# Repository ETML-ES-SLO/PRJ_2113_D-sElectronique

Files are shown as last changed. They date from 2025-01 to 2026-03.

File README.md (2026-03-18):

# 2113_DeElectronique_V3

Ce projet implémente une application pour microcontrôleur PIC32MM0064GPL020, développée avec MPLAB X et XC32.

## Sommaire

- [Présentation](#présentation)
- [Informations de génération](#informations-de-génération)
- [Compilation](#compilation)
- [Utilisation](#utilisation)
- [Documentation Doxygen](#documentation-doxygen)
- [Diagrammes](#diagrammes)
- [Ressources](#ressources)

## Présentation

Ce dépôt contient le code source et la configuration pour le projet électronique basé sur le PIC32MM.
Il s’agit de réaliser un dé électronique qui puisse être produit en petite série à l’ETML et distribué aux visiteurs de l’ES, par exemple lors des portes ouvertes. S’agissant d’un cadeau, une attention particulière sera portée à la minimalisation des coûts. Le fonctionnement sera le suivant :

Lorsque le montage est secoué puis reposé à l’horizontale, un nombre aléatoire entre 1 et 6 sera affiché à l’aide de 7 LEDs. Il ne doit y avoir aucun bouton. Les LED seront disposées à la manière d’un dé à lancer. Les LED restent allumées 10 secondes, puis le montage s’éteint (coupure d’alimentation totale, sauf pour l’élément de détection du secouement). Ce dernier est le seul sous tension en permanence et réveille le montage à chaque nouveau secouement.

""" Actuellement un bouttons est nécéssaire lors du premier allumage pour configurer accéléromètre, aussi la demande à été modifier pour passer à 3s d'affichage """

Utilisation de l'accéléromètre MC3419 avec une configuration nécéssitant ~0,5g pour déclenchement. 
La résolution du capteur MC3419 est typiquement de 14 bits (0 à 16383 pour ±2g).
1 LSB = 4g (de -2g à +2g)/ 16384 = 0,000244 g ≈ 0,244 mg

Seuil (g) = Valeur_seuil * (Plage_en_g / 2^résolution)
          = 2000 * (4 / 16384 )
          = 2000 * 0,000244
          = 0,488 g

La documentation technique est générée avec Doxygen.

## Modifications apportées entre V2 et V3

- Modification de la fonction d'attente avec utilisation du timer (précision accrue et meilleure gestion du temps).
- Ajout de la possibilité de modifier le changement de la consigne PWM avec le CoreTimer (meilleure flexibilité et contrôle).
- Ajout du réglage d'intensité automatique avec les "rampes" (transition douce de l'intensité).
- Refactorisation et amélioration des commentaires pour une meilleure génération de documentation Doxygen.
- Refactorisation de la structure principale du main.

## Informations de générations

```
Product Revision  :  PIC24 / dsPIC33 / PIC32MM MCUs - 1.75.1
Device            :  PIC32MM0064GPL020

Les drivers générés sont testés avec :
    Compiler      :  XC16 v1.35
    MPLAB         :  MPLAB X v5.05

La version 3 de cette application est conçue et testée avec :
    Compiler      :  XC32 v2.5 
    MPLAB         :  MPLAB X v5.50
```

## Versionning 
 Latest Hardware : 2113E_DeElectronique
 
 Latest Software : 2113_DeElectonique_V3.X_2024

le Hardware version D et E sont compatibles avec le soft V3  

## Compilation

1. crée un dossier "PROJ" sous" C:\microchip\harmony\v2_06\apps\"
2. Cloner ce dépôt à l'intérieur  le chemin devrais être : "C:\microchip\harmony\v2_06\apps\PROJ\PRJ_2113_D-sElectronique"
4. Ouvrez le projet dans MPLAB X.
5. Sélectionnez le compilateur XC32 v2.5.
6. Compilez le projet (`Build Project`).

## Utilisation

- Chargez le firmware sur la carte cible (2113E_DeElectronique) via MPLAB X (la carte doit être alimentée en +1,5V).
- Maintenire le bouton S1 enfoncer pendant la durée de programmation de la carte.
- Retirer la sonde de programation (snap/icd4) appuyer sur le switch environs 1s.
- secouer
- pour éteindre: retirer la pile 

## Etat actuel 

- Les résistances R14 et R17 ont été changées, 1k & 5k6 --> 10k & 56k.

### Résultat des tirrages 
- sur 130 tirrages: 



Le N°1 sort le plus souvent

## Documentation Doxygen

La documentation complète du code est disponible dans le dossier [html/](html/).  
[Consulter la documentation Doxygen](https://docdees.neocities.org/)
(ouvrir dans un browser une fois le dépot en local) exemple du rendus : 





## Diagrammes

Précédente version (V2)



Nouvelle version (V3) 



les autres diagrammes sont disponibles sous "C:\microchip\harmony\v2_06\apps\PROJ\PRJ_2113_D-sElectronique\soft\2113_DeElectronique_V3.X\code2flow"

## Ressources

- [Diagramme de flux (Code2Flow)](https://app.code2flow.com/)
- [VS Code](https://code.visualstudio.com/)
- [GitHub Copilot](https://github.com/features/copilot)
- [MPLAB X IDE](https://www.microchip.com/en-us/tools-resources/develop/mplab-x-ide)
- [Graphviz](https://graphviz.gitlab.io/)
- [Doxygen](https://www.doxygen.nl/index.html)
- [MCC Standalone (MPLAB Code Configurator)](https://www.microchip.com/en-us/tools-resources/configure/mplab-code-configurator)
- [Documentation Microchip PIC32MM](https://www.microchip.com/wwwproducts/en/PIC32MM0064GPL020)

---

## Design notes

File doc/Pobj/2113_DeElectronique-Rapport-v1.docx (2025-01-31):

2113_DeElectronique

Travail de diplôme

École supérieure

Filière électronique

A l'attention de :

M.Castoldi

M.Isoz

M.Zosso

8 novembre 2021

ETML

Maxime Colloud

# Introduction

## Contexte

Ce projet porte sur la conception d’un dé électronique destiné à être produit en série à l’EML et distribué aux visiteurs des portes ouvertes de l’ETML-ES.

## Résumé du cahier des charges

(Cahier des charges à voir en annexe)

### Objectif

Réaliser un dé électronique le moins couteux possible qui une fois secoué puis reposé horizontalement affichera pour une durée de 10 sec un chiffre aléatoire entre 1 et 6 à l’aide de 7LEDS disposées à la manière d’un dé à lancer. Après la durée d’affichage, le système se met hors-tension (sauf pour l’élément de détection de secousse).

### Données d’objectif

#### A) Les composants principaux

- 7 LEDs
- Accéléromètre avec interruption pour l’enclenchement du système
- MCU PC32MX ou PIC32MM
- Alimentation par pile AA ou AAA

#### B) Autonomie

Autonomie minimale de 10'000 lancés de dé et d’un an en mode veille

#### C) Coûts

- Composants peu couteux
- PCB simple ou double face (pas de composants bottom)
- Boitier simple concevable à l’ETML

#### D) Dimensions maximales

Dimensions maximales du boitier : 70 x 70 x 25 mm.

#### E) Logo

Logo ETML + mention « Ecole supérieure – filière électronique » doivent être visible sur l’objet final.

# Pré-étude

## Planning

(Voir planning en annexe)

## Schéma général du système

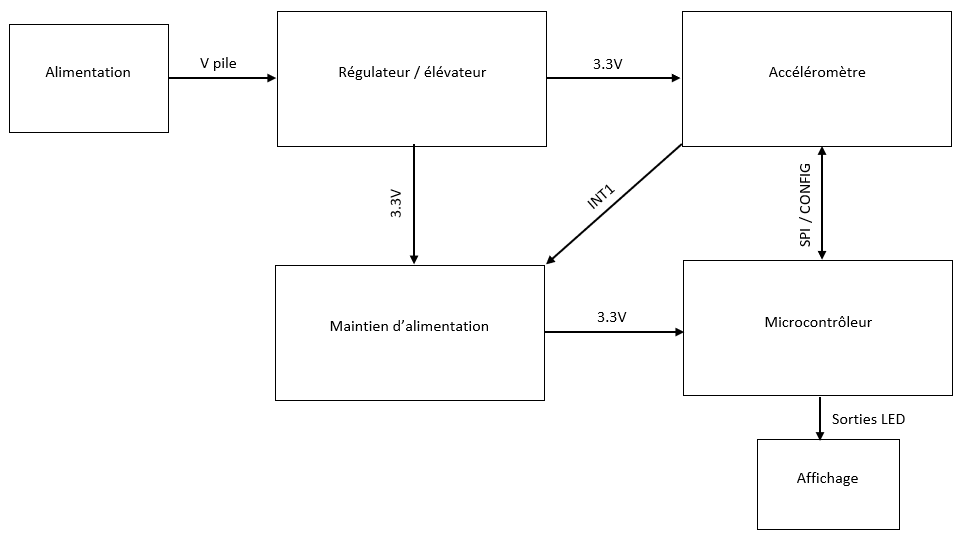
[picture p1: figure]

## Contrainte du choix des composants

Pour le choix des composants, le cahier des charges ne donne pas de contrainte particulière autre que 2 familles de microcontrôleur à choix, l’alimentation par pile AA ou AAA et un coût bas des prix.

### Méthode sélection des composants :

Pour choisir les composants qui seront utilisés pour le projet, plusieurs éléments ont été pris en compte :

- Le prix du composant
- Disponibilité du composant
- Utilisabilité
- Disponibilité
- Taille de boitier

## Choix de l’alimentation

### Tension d’alimentation du système :

L’alimentation du système est définie par les deux circuits : microcontrôleur et accéléromètre.

#### Tension microcontrôleur

#### Tension accéléromètre

### Options d’alimentation :

#### 2 piles :

2 piles AA permettent une tension entre 2V piles vides et 3V piles pleines. Cette option serait fonctionnelle mais utilise 2 piles. Pour la fonction simple d’un dé, 2 piles font beaucoup de capacité et prennent plus de place

#### 2 piles + régulateur :

Avec un régulateur, les problèmes sont identiques que pour 2 piles seules, le régulateur viendra ajouter une stabilité à la tension, mais usera moins les piles dû à la perte de tension régulateur de 0.3V en moyenne entre l’entrée et la sortie.

#### 1 pile + élévateur :

L’élévateur permet d’utiliser une seule pile et de l’utiliser jusqu’à sa décharge complète.

#### Choix effectué :

J’ai choisi l’option 1 pile + élévateur. Cette option permet d’utiliser 1 seule pile utilisant un minimum de place sur le PCB et d’utiliser la pile jusqu’à sa fin de vie. L’élévateur conservera une tension fixe sur la carte.

## Choix des composants principaux

### Complexité des recherches

Avec les pénuries actuelles de semi-conducteurs, il est prévu que des problèmes de disponibilité de composants se fassent ressentir, ne permettant pas forcément d’acquérir les composants les plus efficaces mais de choisir au contraire des composants utilisable et disponible.

### Microcontrôleur

Le choix du microcontrôleur était contraint par un choix entre deux famille PIC32MM et PIC32 MX. Le choix s’est porté sur le plus petit microcontrôleur étant donné que pour le fonctionnement du dé électronique ne demande que peu de mémoire RAM et peu de mémoire FLASH. Puisque le projet est destiné à être un cadeau à des visiteurs et que le prix doit être au plus bas, en comparant les deux familles de microcontrôleur et ceux disponible, le choix final s’est porté sur la famille MM qui est moins cher et sur le modèle PIC32MM064GPL020.

### Accéléromètre

Les problèmes de semi-conducteur, se sont fait ressentir dans le choix de l’accéléromètre. La famille ST était un choix de départ par sa documentation très complète, des exemples de codes disponibles. De plus cette famille d’accéléromètre a déjà été utilisé à l’ETML-ES et un support d’aide sur son fonctionnement serait possible. Le fabricant conçoit de plus des petites cartes avec l’accéléromètre monté qui permet de pouvoir tester le fonctionnement de l’accéléromètre avec un kit micro en attendant l’arrivée de la commande du PCB et le montage de la carte.

Malheureusement la grande partie des accéléromètres sont en rupture de stock, les cartes montées sont indisponibles et les accéléromètres disponibles ont un prix élevé. Le choix s’est donc tourné sur un accéléromètre disponible, à bas prix avec une documentation complète, des fichiers .h et .c de l’accéléromètre, cependant pas d’exemples de codes disponible. Selon ces derniers critères, il ne restait que le MC3419.

### Élévateur

L’élévateur est le composant dont le choix a été le plus complexe avec les problèmes de semi-conducteur. La plupart des élévateurs sont en rupture de stock. Je me suis tourné sur le choix de la disponibilité et de l’utilisabilité d’un élévateur, mais aussi sur un élévateur possédant un boitier standard afin de permettre à la fin de la pénurie de remplacer l’élévateur actuel par un autre élévateur plus adapté, voir même moins couteux. En triant les options de tensions de sortie entre 3 et 3.3V, le seul élévateur restant disponible était le R1210N331D-TR-FE.

Le choix était tout d’abord tourné vers un élévateur avec une tension de sortie de 3V ce qui consommerait moins qu’une tension de 3.3V mais tous les élévateurs utilisables étaient en rupture de stock.

# Design

## Schéma bloc

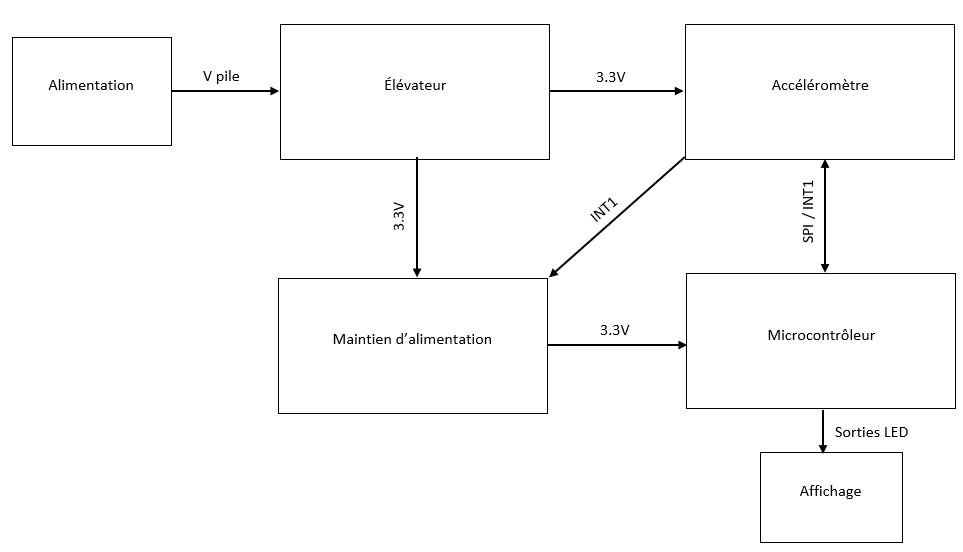
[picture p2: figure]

## Détail des blocs fonctionnels

### Général

Le principe utilisé est une alimentation du système par une pile AA.

La pile est connectée à l’élévateur pour élever sa tension à 3.3V et permet le fonctionnement du microcontrôleur et de l’accéléromètre.

Afin de garder le système en basse consommation hors utilisation, seul l’accéléromètre est alimenté en permanence par l’élévateur afin rester fonctionnel. Lorsque l’accéléromètre décèle un mouvement de secouement, il active une pin d’interruption qui vient activer l’alimentation du microcontrôleur.

Le microcontrôleur à son réveil affiche un chiffre aléatoire pour une durée de 10sec puis reset l’interruption de l’accéléromètre coupant l’alimentation du microcontrôleur.

### Alimentation

L’alimentation est une pile de format AA 1.5V.

### Élévateur

Le bloc élévateur a pour but d’élever la tension de la pile à la tension fixe de 3.3V pour alimenter le système. L’élévateur accepte une tension de minimum 1V pour son fonctionnement (tension d’une pile considérée vide).

### Maintien d’alimentation

Cette partie sert « d’interrupteur » à l’alimentation du microcontrôleur. Celui-ci bloque le 3.3V de l’élévateur et le laisse passer lorsque l’accéléromètre active le montage qui alimente le microcontrôleur.

### Accéléromètre

L’accéléromètre a pour intérêt de détecter un mouvement, dont le seuil de détection pour être réglé pour détecter un secouement plus ou moins fort. L’accéléromètre agit avec la partie de maintien d’alimentation en activant une sortie d’intettupt quand les conditions de secouements sont atteintes et enclenche l’alimentation du microcontrôleur.

### Microcontrôleur

Cœur du système, le microcontrôleur entre en action lorsque l’accéléromètre active son alimentation. Celui-ci à son réveil déterminera si le montage est alimenté pour la première fois (réveil par détection de pile sans action de l’accéléromètre) dans quel cas il activera une sortie agissant sur le maintien d’alimentation pour se garder alimenter le temps de configurer l’accéléromètre, puis s’éteindra en baissant cette pin.

Dans le cas d’un réveil par l’accéléromètre, le microcontrôleur sera connecté à la pin interrupt de l’accéléromètre pour détecter un réveil pour accéléromètre. Il génèrera un chiffre aléatoire pour une durée de 10sec avant de reset l’interrupt de l’accéléromètre et retourner en état hors tension.

### Affichage

L’affichage se fait à partir de 7 LED basse consommation disposé de la manière d’un dé à lancer.

## Calculs

### Évaluation des couts

Les couts ont été calculés sur la base du prix lors d’une commande de 100 pièces.

(Voir évaluation des couts en annexes)

### Évaluation de la consommation

#### Consommation hors utilisation :

Hors utilisation, la consommation provient de l’accéléromètre et de perte dans l’élévateur.

La datasheet indique une consommation de 77uA.

Le courant sur la pile est plus élevé que le courant en sortie de l’élévateur dû à l’élévation de tension, pour faire une moyenne approximative, je vais prendre comme tension de pile 1.25V.

3.3V / 1.25V = 2.64 (rapport d’augmentation in / out)

Le courant sur la pile est donc en moyenne 2.64x plus gros qu’à la sortie de l’élévateur.

Les 77uA deviennent alors :

77 * 2.64 = 203.28uA

En considérant une capacité de pile moyennant 2000mAh, on peut calculer la durée approximative du système hors fonctionnement.

2000 / 0.20328 / 24 = 409.9 jours.

#### Consommation en utilisation :

Par approximation, on considère en moyenne que 3.5 LED sont allumées sur 100 lancés. Pour 2mA de consommation, ça fait 7mA nécessaire pour les LED.

7 * 2.64 = 18.48 mA sur la pile

Je considère par approximation une consommation moyenne de 20mA.

Un lancer dure en moyenne 10 sec.

Donc on peut calculer.

Nbr lancer= (Capacité pile)/(I*T)= (2000*3600)/(20*10)= 36^(') 000 lancers

### Dimensionnement de l’élévateur

Pour dimensionner l’élévateur, les calculs d’un autre élévateur de taxas instruments ont été utilisés puisque l’élévateur choisi n’indique pas de calculs de dimensionnement dans sa datasheet.

La recherche du pire cas a été utilisée pour calculer les composants.

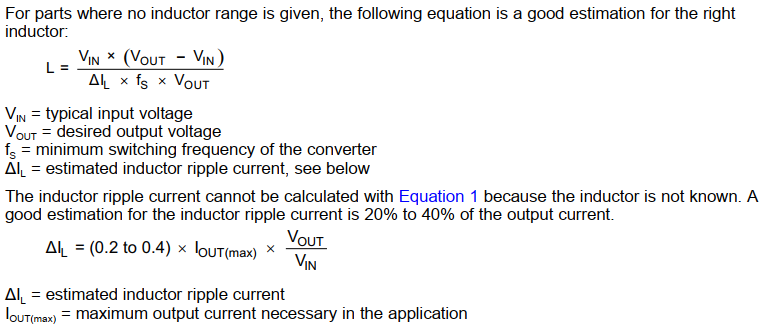
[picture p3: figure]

La fréquence de switching de l’élévateur est indiquée à 180kHz par le fabricant.

Le courant max utilisé est une approximation à 20mA.

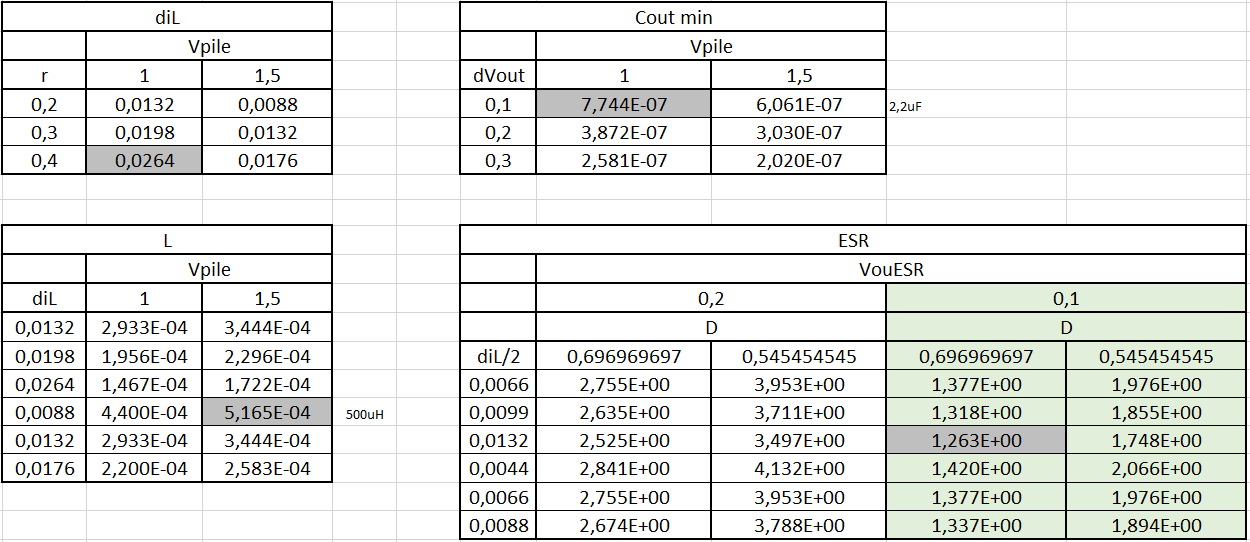
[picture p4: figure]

L est arrondi à 560uA.

## Schéma électrique complet

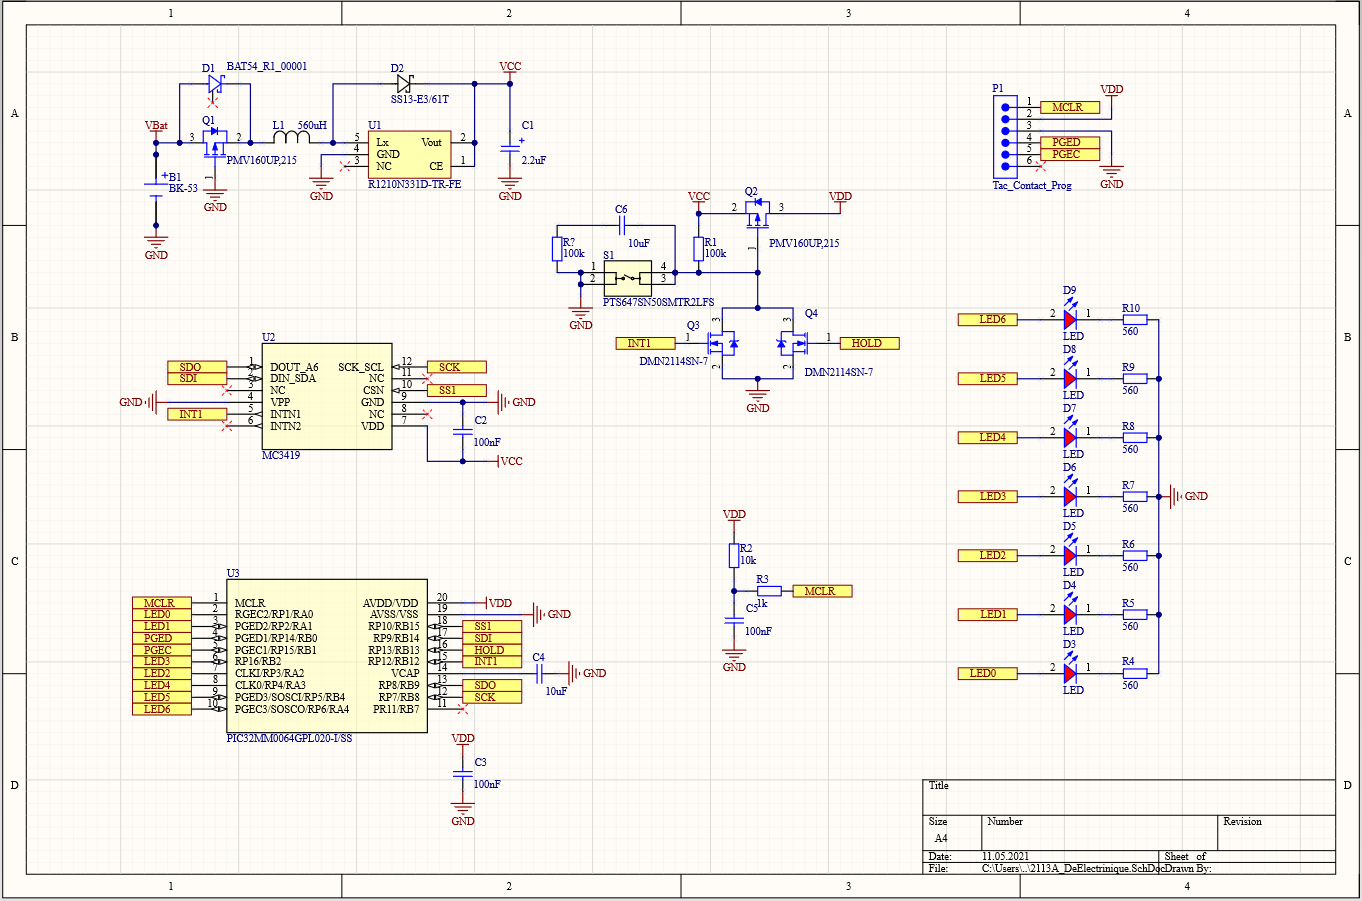
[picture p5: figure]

(Voir en annexe le schéma en meilleur format)

## Bloc schématique

### Alimentation

La pile est connectée à l’élévateur qui augmentera la tension à 3.3V. La diode D2 est une équivalente à la diode recommandée par le fabricant.

Pour éviter les tensions inverse par une mise à l’envers de la pile, un MOSFET canal P est placé avec la source sur la pile ce qui permet selon le fonctionnement interne d’avoir la diode du MOSFET qui permet la conduction avec la pile dans le bon sens. La diode D1 est prévue par sécurité pour permettre d’avoir la tension minimal drain source si la diode du MOSFET demande une tension trop élevée. Pile vide = 1V, si la diode du MOSFET demande 0.7V, la tension drain-source ne sera plus respectée.

### Maintien d’alimentation

Les valeurs du RC sur le schéma ne sont pas les meilleurs. Le but étant de tester le fonctionnement, puis de chercher les bonnes valeurs si le montage fonctionne comme voulu.

Le principe de fonctionnement de ce montage est le suivant :

Le MOSFET Q2 est un canal P et celui-ci conduite lorsqu’il y a une logique basse sur sa gate. Les MOSFET Q3 et Q4 sont canaux N et conduisent avec une logique haute.

Par défaut, les MOSFET Q3 et Q4 ne conduisent pas, le MOSFET Q2 a donc la tension 3.3V à ses bornes. Lorsqu’il y a un des deux MOSFET Q3 ou Q4 qui conduit, la gate du MOSFET Q2 se trouve à la masse et se met à conduire. La résistance R1 permet de créer une différence de potentiel entre le drain et la gate du MOSFET Q2 lors de sa conduction. Elle permet de plus une limitation de courant et avec une valeur de 100k, les pertes d’énergie son basses.

Dans le but de détecter une première mise sous tension, un RC avec C6, R1 et R11 a été implémenté, celui-ci va créer lors d’une mise de pile, une tension de 0V sur la gate Q2 et permettre une conduction. Le condensateur va ensuite se charger et restera charger évitant des pertes d’énergies par la suite.

Le but de la résistance R11 est de limiter le courant qui circulera au travers des MOSFET lors de la décharge du condensateur.

Par sécurité en cas de non-fonctionnement du RC, un bouton est implémenté en parallèle pour permettre de faire la détection de première mise sous tension manuellement et de configurer l’accéléromètre.

Le signal HOLD provient du microcontrôleur pour activer son auto-maintient d’alimentation.

Le signal INT1 provient de la pin d’interrupt de l’accéléromètre pour activer l’alimentation lors d’une détection de secoument.

L’ajout de la partie détection de première mise sous tension a été faite précipitamment pour cause d’un envoi de PCB en fabrication qui devait se faire au plus vite. Les valeurs schématique R11 et C6 ne sont pas représentative des valeurs du besoin et fonctionnelle. Celle-ci non pas été calculé avant la commande du PCB et ont été déterminé par la suite.

### Accéléromètre

L’accéléromètre fonctionne en SPI ou I2C, pour activer la communication par SPI, il suffi de mettre la pin 10 CSN à 0. La pin 1 DOUT_A6 est une sortie de donnée SPI, la pin 2 DIN_SDA est une entrée de donnée SPI, la pin 12 SCK_SCL est l’entrée clock SPI et la pin 5 INTN1 est la pin d’interrupt de l’accéléromètre qui se mettra à 1 lors d’une détection de secouement.

C2 est un condensateur de découplage.

### Microcontrôleur

Le microcontrôleur utilise les pins SPI en 4 fils, il utilise une pin pour le signal de maintien d’alimentation HOLD, une pin d’entrée avec le signal INT1 de l’accéléromètre pour avoir l’information lors de son réveil d’un réveil par accéléromètre et non la première mise sous tension.

Chaque LED sont connectées sur une pin du microcontrôleur.

### Debug

Il a été choisi pour le connecteur de débug d’utiliser des pads sans connecteur et de venir directement se plug sur la carte. Ça permet une économie de place et de prix.

### Affichage

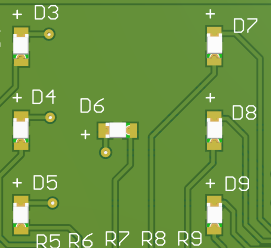
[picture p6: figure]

Les LEDS sont des LED low power rouge, permettant un besoin de 2mA pour fonctionner. Les LED rouges sont les LED qui demandaient la tension la plus basse de fonctionnement.

## PCB

L’implémentation des composants s’est faite comme suit :

Les LED ont été placées au milieu de la carte. Le support de pile en bordure de carte pour permettre l’ajout et le retrait facile de la pile. Le reste des composants a été placé selon la place restante et par bloc fonctionnel.

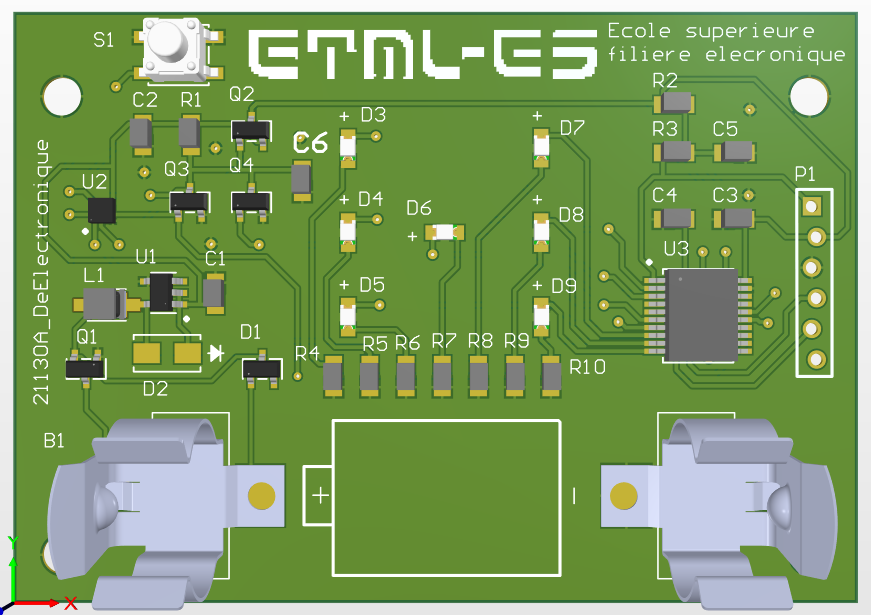
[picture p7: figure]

# Soft

## Diagramme du soft

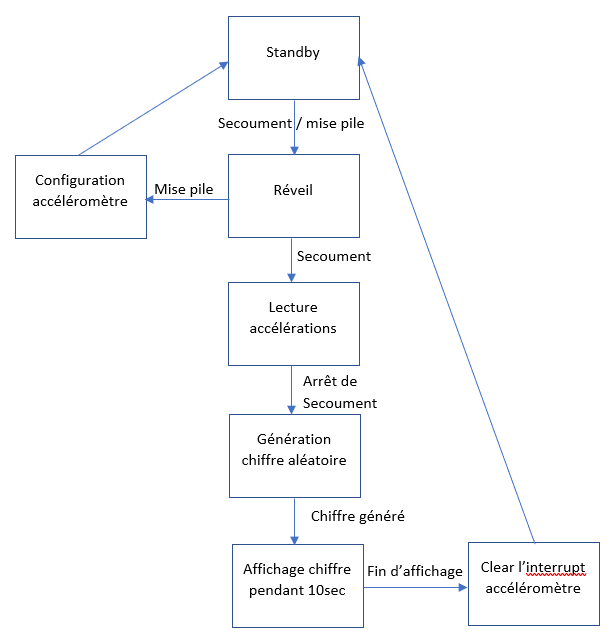
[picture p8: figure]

### Explication soft

Initialement, le programme est en standby avec le microcontrôleur hors tension.

Lors de la mise de la pile ou par l’accéléromètre, le microcontrôleur se réveille et se configure. Il lit le signal INT1 pour connaitre la raison de son réveil (mise de la pile ou réveil par l’accéléromètre). Si le signal INT1 est à 0, alors c’est une mise de pile, dans ce cas, le signal HOLD est levé pour maintenir l’alimentation du microcontrôleur, puis par SPI, configure l’accéléromètre selon les paramètres nécessaires au fonctionnement du dé avec de descendre le signal HOLD et couper l’alimentation du microcontrôleur.

Lors d’un réveil par l’accéléromètre, le signal INT1 est lu à l’état haut et le programme lit les registres d’axes pour identifier la continuité ou l’arrêt de l’action de secoument. Une foi le secoument terminé, les axes sont lus et les valeurs sont utilisés avec la fonction RAND qui permet une génération pseudo aléatoire d’un nombre, le modulo 6 de ce nombre est effectué pour acquérir un chiffre entre 0 et 5 pseudo aléatoire.

Le nombre une fois généré est affiché sur les LED pour une durée de 10 sec puis le flag d’interruption qui aura pour effet de remettre le signal INT1 à 0 et ainsi couper l’alimentation du microcontrôleur

## Création d’un projet MCC

Les projets utilisant la famille MM utilise pour la configuration des chips, le Code Configurator ou MCC d’MPLAB X. Il faut alors au préalable avoir installé l’extension du MCC trouvable sur le site MPLAB X.

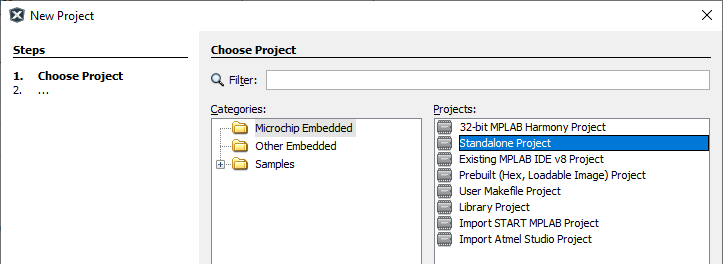
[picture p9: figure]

Une fois installé, il faut créer un projet Standalone Project puis choisir le microcontrôleur utilisé (pour le dé c’est le PIC32MM064GPL020).

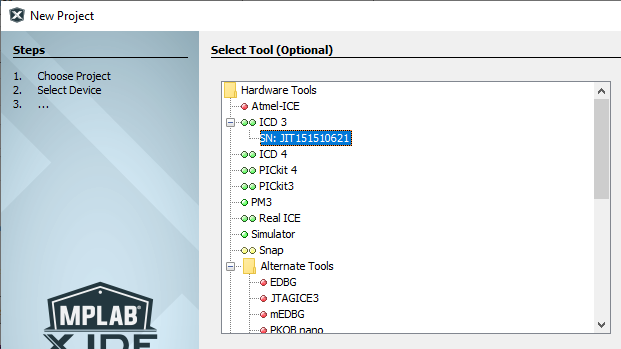
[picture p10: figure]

Pour ce projet, l’outil utilisé est l’ICD 3

Avec le compilateur XC32

On nomme ensuite le projet qui peut être placé à n’importe quel endroit.

## Configuration du microcontrôleur

Pour ouvrir le MCC, il faut aller sous l’onglet Tools -> Embedded et choisir le MCC.

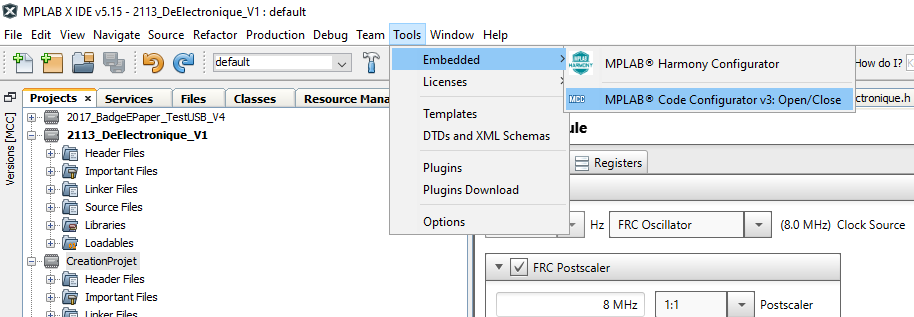
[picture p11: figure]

L’interface du code configurator est intuitif et on se repère rapidement.

### Clock

Par défaut, le clock secondaire est actif et ceci empêche l’utilisation de 2 pins, il faut desable le SOSCEN.

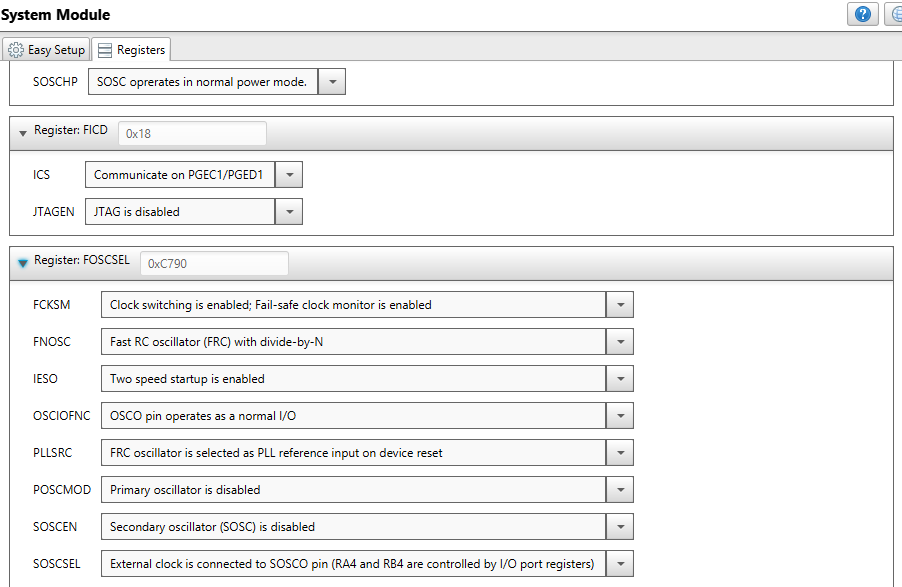
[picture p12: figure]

### Timer

Puisque le dé doit afficher un chiffre pour une durée de 10sec (spécification du cahier des charges), un timer est ajouté pour timer précisément cette durée.

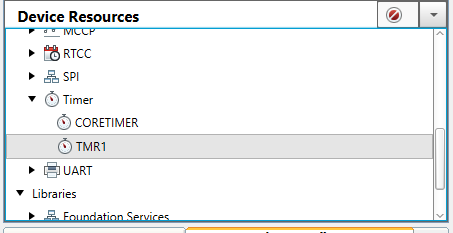
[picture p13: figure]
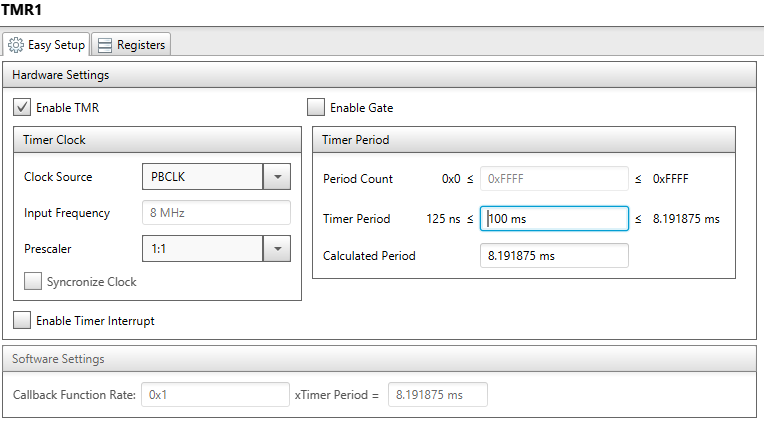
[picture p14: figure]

L’interface permet de rentrer manuellement la durée de période. Une durée de 100ms a été choisi en premier lieu pour effectuer des tests et dans le cas où une durée plus courte de 10sec soit nécessaire.

Lorsque l’on rentre la durée souhaitée, si le timer ne permet pas d’accéder à la durée choisie, il se configurera avec la valeur la plus proche. Ci-dessus, le prescaler étant trop petit, la durée max est de 8.191875ms.

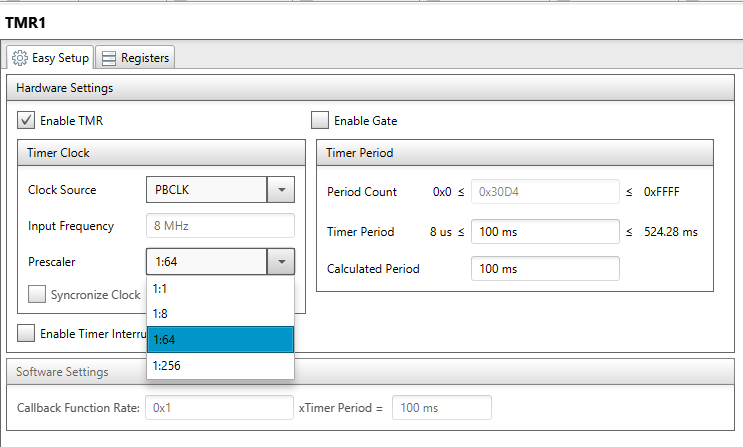
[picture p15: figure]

Il suffi dans ce cas de modifier le prescaler et de rentrer de nouveau les 100ms pour configurer la période comme choisi.

### SPI

Le SPI est configuré comme suit :

Enable en mode 8 bits, le BaudRate est laissé par défaut de même que le clock source.

La partie SPI Mode a été configurée par le biais de mesure pour correspondre à la forme de signaux que l’accéléromètre utilise. Cela car je n’ai pas exactement compris à quoi correspond le Clock Polarity et le Clock Edge.

Signaux mesurés :

MISO

MOSI

CSS

CLK

Forme des signaux de la datasheet :

### Pins configuration

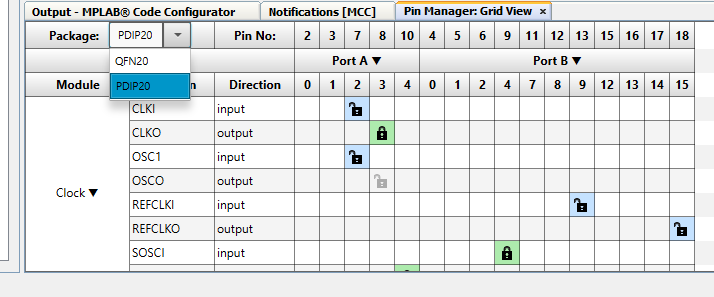
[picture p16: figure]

Pour la configuration des pins il faut prêter attention à une chose, ce microcontrôleur possède plusieurs boitiers, il faut donc commencer par sélectionner le bon package.

On sélectionne les pins d’entrées et sorties facilement avec le pin manager.

Le cadenas bleu représente une configuration possible non active, les cadenas verts représentent une configuration active et les cadenas beige représente les configurations bloquées. Par exemple une pin output ne peut être également input.

Il faut prêter également attention au pin module, les pins output doivent avoir la case output coché sinon celles-ci seront considérées input même si la configuration du pin manager est output. Il est aussi possible ici de configurer une pin pour démarrer à l’état haut.

### Interrupt

Dans l’Interrupt Manager, on détermine les interruptions actives. Pour le dé, l’interrupt du TMR1 est activée.

### Warning restant

Un warning est restant, mais ne pose pas de problème au fonctionnement. Je n’ai pas trouvé à quoi il correspond et comment le régler.

### Génération

Pour générer les configurations, il suffit de cliquer sur Generate et les fichiers sont automatiquement générés ou modifiés.

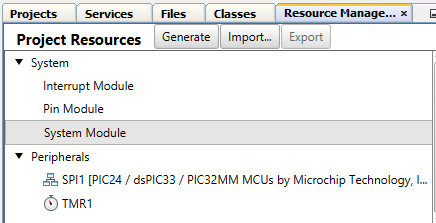
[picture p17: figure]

En annexe les fichiers main.c, DeElectronique.c / .h

## Configurations accéléromètre

Pour la configuration de l’accéléromètre, l’init de base du fichier.c fourni par le fabricant a été utilisé et complété. (Par manque de temps et le projet pas entièrement fonctionnel, les configurations ne sont pas optimales au fonctionnement et ont été copiées des fichiers d’exemples trouvés.

### Range

Le registre range permet de définir l’intensité et la plage de détection de secousses.

La configuration à 2g de l’init de base du fabricant a été utilisée.

### Sample Rate

Le Sample Rate règle la fréquence de mesure des axes.

La configuration à 100 Hz du fabricant a été laissée.

### INT1

La polarité de la pin INT1 peut être configuré avec le registre suivant :

Selon l’utilisation besoin, les bit 2 et 3 sont activés pour configurer la sortie en push-pull active haute. Par défaut La sortie INT1 se met automatiquement à 1 lorsque le flag de l’interruption qui sera utilisée est levé et se remet à 0 quand le flag est baissé.

### Activation de l’interruption Shake

Plusieurs type d’interrupt sont existantes et peuvent être configurés.

L’interruption qui sera la plus pertinente est la Shake interrupt.

Pour activer cette interruption, il faut configurer plusieurs registres :

Le bit 3 du registre 0x06

Et les bit 2 et 3 du registre 0x09

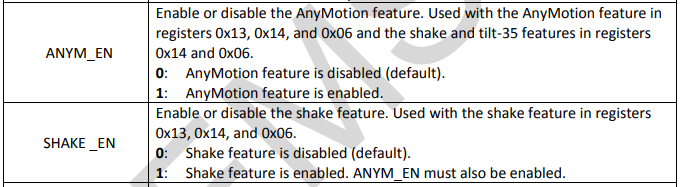
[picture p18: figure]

Le fabricant indique que lors d’un contrôle du flag d’interrupt en polling, il est préférable d’utiliser le registre 0x14 et y lire le bit 3. Si celui-ci est à 1, le flag est levé. On peut ensuite clear le flag en mettant ce même bit à 0.

### Utiliser l’interruption Shake

Beaucoup de temps a été dépensé pour comprendre et configurer correctement l’interruption. Ceci dû à des tournures de phrase peu clair et à des codes exemples inexistant. Après un moment au point mort, le maître de diplôme a fourni de l’aide afin de comprendre comment bien configurer cette interruption et la rendre fonctionnelle.

Après un moment de recherche et de compréhension de documentation, il s’est avéré que d’autres registres devaient impérativement être configuré car les valeurs par défaut ne fonctionnaient pas.

Le Shake Treshold Registers

Qui détermine la valeur de secousse à dépasser.

Et le Shake Duration, Peak-To-Peak Register

Qui détermine selon ce que j’ai compris avec le SHK_CNT le nombre de fois en une période de mesure que la valeur limite doit être dépassée.

Il n’a pas été compris à quoi correspond la valeur PK_P2P_DUR.

En cherchant sur le net, nous avons finalement trouvé une bride d’information utilisable. Une datasheet d’une carte pluggable avec l’accéléromètre a été trouvé.

Dans cette documentation des valeurs sont présentes et nous avons configurés les registres avec ces valeurs.

Finalement les interruptions ont pu fonctionner avec ces valeurs.

En annexe les fichier accéléromètre .c / .h qui contiennent les fonctions et define de l’accéléromètre.

# Tests et Mesures

## Lecture accéléromètre

Pour tester la lecture des registres, j’utilise une variable qui contiendra la lecture du registre à lire. Le registre choisi pour ce test est le registre d’ID du chip, il contient donc la valeur connu 0xA4 (information du datasheet)

La valeur lue est celle attendu, la lecture des registres est fonctionnelle.

## Écriture accéléromètre

Pour confirmer l’écriture dans les registres, j’utilise une variable qui lit un registre avant modification, j’écris une donnée dans le registre, puis lis de nouveau le registre. Si la valeur lue change pour afficher la nouvelle configuration, alors l’écriture fonctionne correctement.

Le registre utilisé possède la valeur 0x10 par défaut.

La valeur du registre est remplacée par la valeur 0xAA, puis le registre est lu de nouveau.

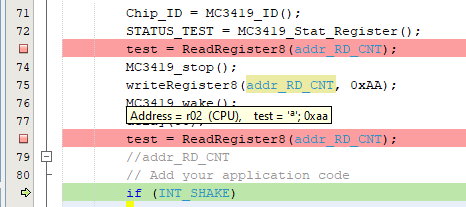
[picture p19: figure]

Lors des premiers tests d’écriture, je ne parvenais pas à écrire dans les registres et la valeur par défaut ne se modifiait pas. Finalement j’ai appris après plusieurs tests, que le chip doit être mis en mode standby afin d’écrire dans les registres (l’information n’était pas présente dans la datasheet).

L’écriture dans les registres est donc belle et bien fonctionnelle.

## Configurations

Pour tester les configurations des registres. Afin de vérifier si les données sont bien envoyées et les registres configurés, j’ai lu chaque registre afin de confirmer les valeurs modifiées et les configurations de l’accéléromètre.

En mode débug, chaque valeur est lue une par une en pas à pas.

Les valeurs de chaque registre sont bien configurées comme voulu.

## Alimentation

Dans un premier temps, l’élévateur a été monté et testé seul sans le reste de la carte.

La tension en sortie de l’élévateur et le courant de consommation a été relevé avec un multimètre. Une alimentation variable a été utilisée en remplacement de la pile aux conditions de tension d’une pile pleine (1.5V) et d’une pile vide (1V).

Tension d’alime mesurée à 1.5V :

Vout = 3.302V

I = 349uA

Tension d’alime mesurée à 1V :

Vout = 3.3V

I = 798uA

Alimentation inverse : pas de courant qui circule dans le circuit. (Juste élévateur monté)

## Signaux d’alimentation avec pile

Le signal du 3.3V est mesuré en mode AC afin de retirer la constante continue.

Le signal a beaucoup de bruit mais la tension oscille peu, le signal est globalement assez stable. Une oscillation de 19.75mV est mesurée.

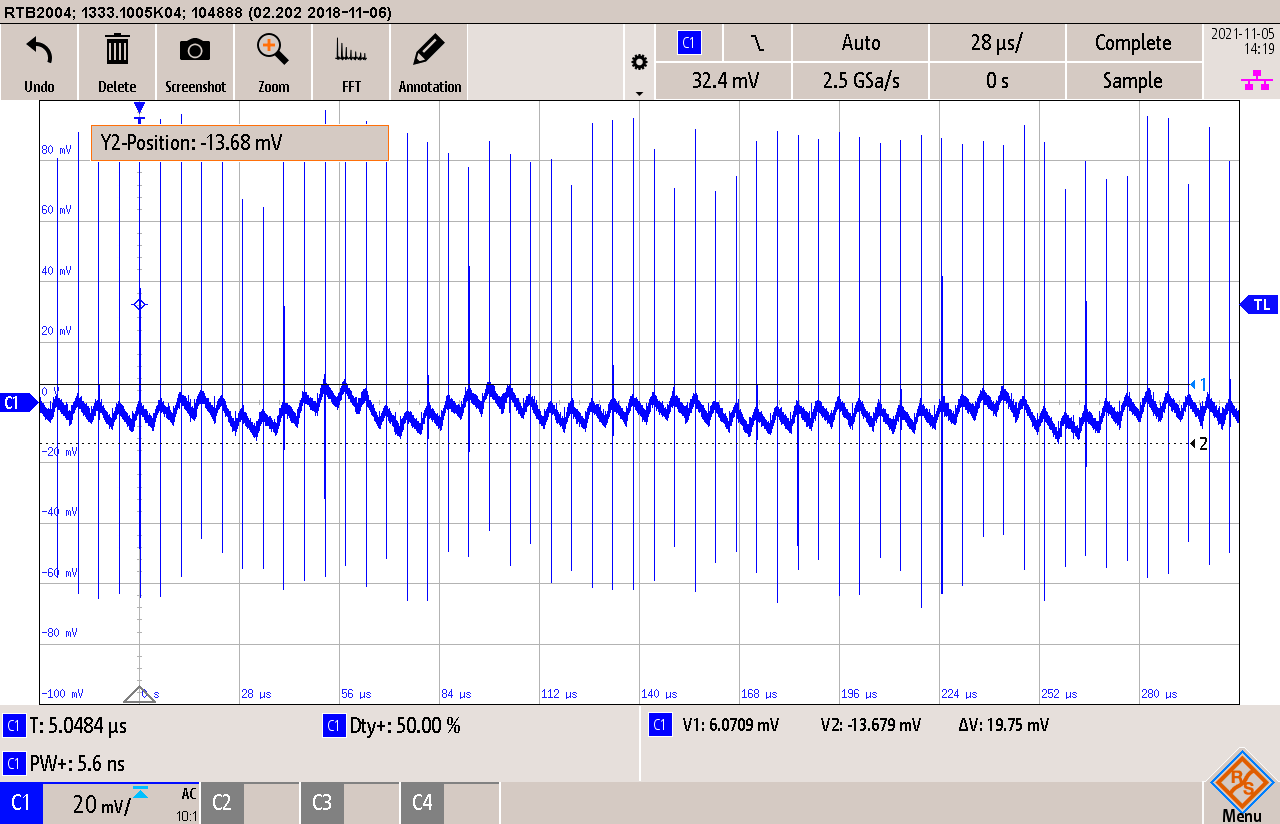
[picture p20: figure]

En zoomant sur les piques de bruit, on observe une oscillation du signal qui doit être dû au fonctionnement de l’élévateur. L’oscillation est faible 155.46mV et ne pose pas de problème particulier.

## Alimentation lors d’un secouement

Lorsque l’action de secoument est effectuée, un dysfonctionnement du dé apparait. Le programme contrôle en permanence le flag d’interruption puis lorsqu’un secoument intervient, les LED s’allument. Cependant lors du secoument, les LED clignotent brièvement au lieu du temps désigné. Ceci intervient lors de l’alimentation par pile. En utilisant le mode debug et en alimentant par la sonde de debug, ce problème n’intervient aucunement.

Lors d’un secoument par pile, le signal 3.3V chute d’environ 1.1V.

## État dysfonctionnel du dé

Un état dysfonctionnel du dé a été observé dans le cas d’alimentation par pile lorsqu’un secoument est détecté et que les LED doivent s’allumer.

Le dé se met à essayer d’allumer les LED sans arrêt mais celles-ci ne s’allument que très brièvement au lieu du durée d’éclairage programmée pour 5sec lors du test. Le bref clignotement des LED persiste ensuite sans arrêt et la carte ne parvient pas à se mettre hors tension.

## Test RC et bouton

Le montage RC de détection de première mise sous tension, permet en effet de mettre sous tension le microcontrôleur lors de la mise de la pile. Cependant il semble que le condensateur ne se charge pas et le montage reste en permanence sous tension.

Le RC a donc été retiré et le bouton mit à la place.

Avec le bouton monté, j’ai remarqué un problème quelque peu étrange. En effet la mise de la pile met sous tension le microcontrôleur.

Une mesure de conductivité a été faite pour contrôler un éventuel court-circuit entre les alimentations mais celle-ci sont bien séparées.

Pour trouver l’origine du problème, j’ai mesuré différents points autour des MOSFET Q2, Q3 et Q4.

Première mesure drain Q2 pin 2 : 3.3V, 2ème mesure gate Q2 : 0V.

Ces premières mesures indiquent alors que l’un des MOSFET Q3 ou Q4 conduit.

Q4 étant relié au microcontrôleur celui-ci ne devrait pas pouvoir conduire à l’insertion de la pile étant piloté par le microcontrôleur qui se trouve hors tension à ce moment. L’accéléromètre quant à lui en partant du principe qu’il doit être reconfiguré après chaque mise hors tension, le pin relié à la gate Q3 elle en open drain et ne devrait pas pouvoir piloter le MOSFET non plus.

Mesure gate Q4 : 0V

Mesure gate Q3 : lors de la mesure de tension éteint la LED de test (mise hors tension du montage) tension mesurée : aucune, pin en l’air.

Selon les observations, lors de la mise sous tension du microcontrôleur, la gate du MOSFET Q3 étant en l’air est parasité et maintient l’alimentation du système.

Pour retirer les parasite, dû aux pins en l’air, l’accéléromètre est configuré avec sa pin d’interruption en push-pull.

Pour les parasites du microcontrôleur, des résistances pull-down sont ajoutées à la gate des MOSFET Q3 et Q4.

Pull-down Q4 :

100k

Pull-down Q3 :

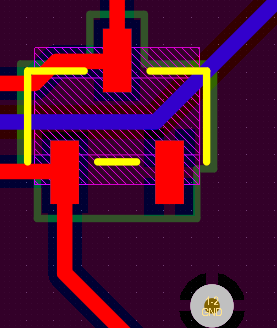
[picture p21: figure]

0

100k

Les pull-down ont pu régler les problèmes de parasite, le système ne se met plus sous tension sans action de mise sous tension voulu.

## Mise pile et utilisation du bouton

Le signal 3.3V a été mesuré lors de la mise de la pile, de l’appui bouton qui configure l’accéléromètre suivi d’un secouement et de l’allumage des LED.

Détection de secouement

Bouton

Mise pile

Sur cet oscillogramme, on remarque une chute de tension lors de l’appui bouton, une chute plus importante encore lors du secouement. On peut ensuite voir une dernière chute de tension qui correspond à l’état dysfonctionnel du dé.

Lors des chutes de tensions, la tension d’alimentation se trouve en dessous du seuil de fonctionnement des deux IC.

## Test des signaux du maintien d’alimentation

Observant le problème de dysfonctionnement, les signaux 3.3V élévateur, 3.3V microcontrôleur et HOLD sont mesurés ensemble.

Cette première mesure est effectuée sous les paramètres de programme suivants :

Activation du signal HOLD, configuration de l’accéléromètre et remise à 0 du signal HOLD. Cette partie étant sans RC, le bouton est utilisé pour indiquer la première mise sous tension.

Ces mesures sont faites sans le RC puis avec RC, les signaux restent identiques.

Canal 1 : tension du condensateur RC

Canal 2 : Tension de l’alimentation du microcontrôleur.

Canal 3 : Signal HOLD

Canal 4 : Tension de sortie d’élévateur

Dans cette première mesure, la mise de la pile ne pose pas de problème, la tension de sortie d’élévateur est à 3.3V. Lors de l’appui sur le bouton, on remarque une chute de tension de 1.5V pour tomber à 1.86V qui se trouve en dessous de la tension d’alimentation de fonctionnement minimum nécessaire. Pour ce programme, même si la chute de tension est trop importante, il n’y a pas de problème soft ni hardware.

Cette deuxième mesure, utilise le même procédé que la précédente mais le programme doit allumer les LED avant de couper l’alimentation.

Pour cette fonctionnalité, la tension de sortie de l’élévateur tombe à 2.21V, même si le microcontrôleur devrait pouvoir supporter une tension d’alimentation minimale de 2V, il y a un effet perturbateur qui provoque le dysfonctionnement du programme.

Lors de l’affichage, on perçoit un bref allumage qui se répète sans arrêt. Sur la mesure on peut voir que le signal HOLD chute pratiquement à 0V avant de remonter. D’après les observations, ceci se produit au moment de l’allumage des LED.

## Ajout du RC

Le fonctionnement du RC est testé de nouveau maintenant les problèmes de pins flottantes réglés afin de déterminer l’utilisabilité de ce système en tant que détection de mise de pile. Bien que le dé doive encore non fonctionnel, on peut déjà déterminer le fonctionnement sans la partie d’allumage des LED.

Comme précédemment, la mesure est faite lors de la mise de la pile, la configuration de l’accéléromètre et la remise à 0 du signal HOLD par le soft. Le condensateur du RC est un 100nF pour avoir un RC faible et la résistance R1 à 10 ohms (suffisamment faible pour éviter un diviseur de tension problématique sur la gate de Q2).

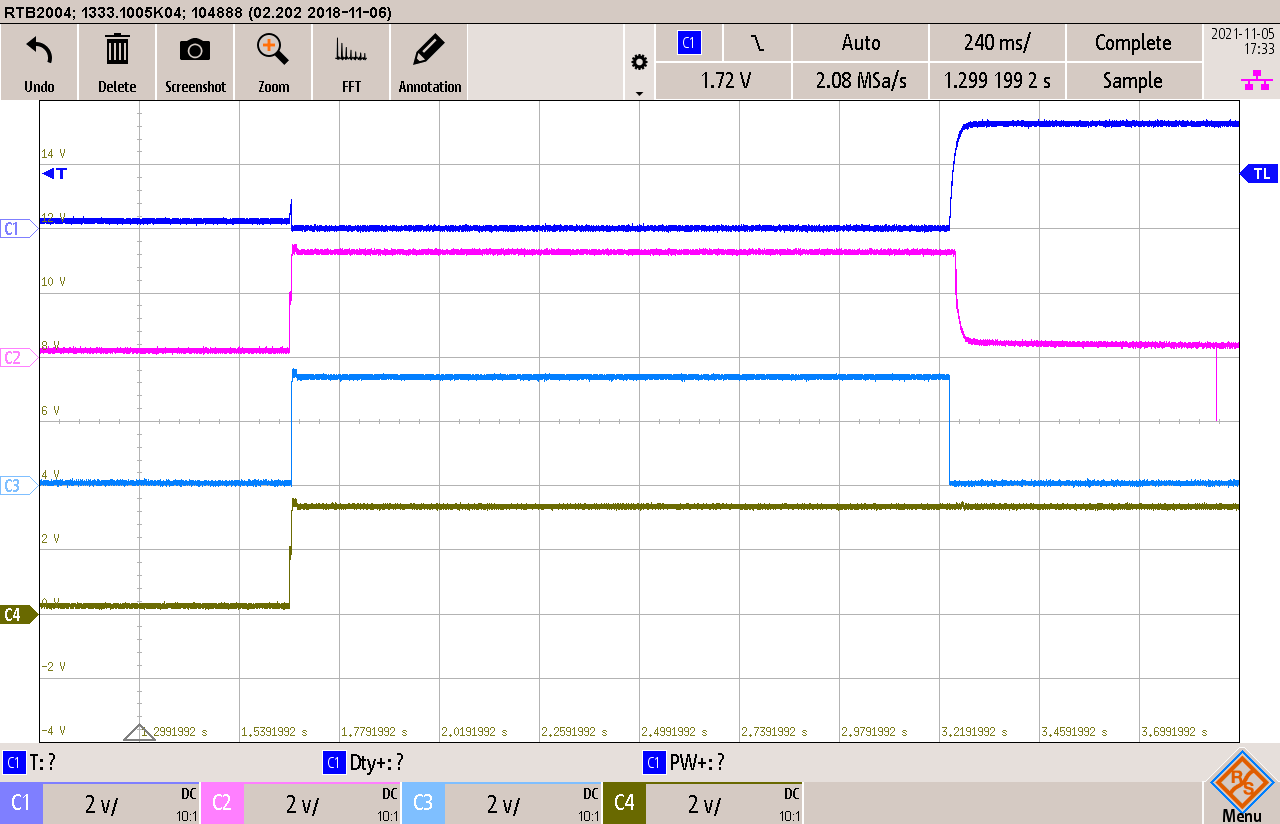
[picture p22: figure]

On peut bien voir que le RC fonctionne bien et peut être utiliser sur la forme finale du projet fonctionnel. On voit à la mise de la pile un pique de tension sur le condensateur. Correspondant à la charge du condensateur le temps de la configuration du microcontrôleur et la mise à 1 du signal HOLD par le soft. Une foi le signal de maintien levé, le condensateur se décharge au travers du MOSFET ouvert.

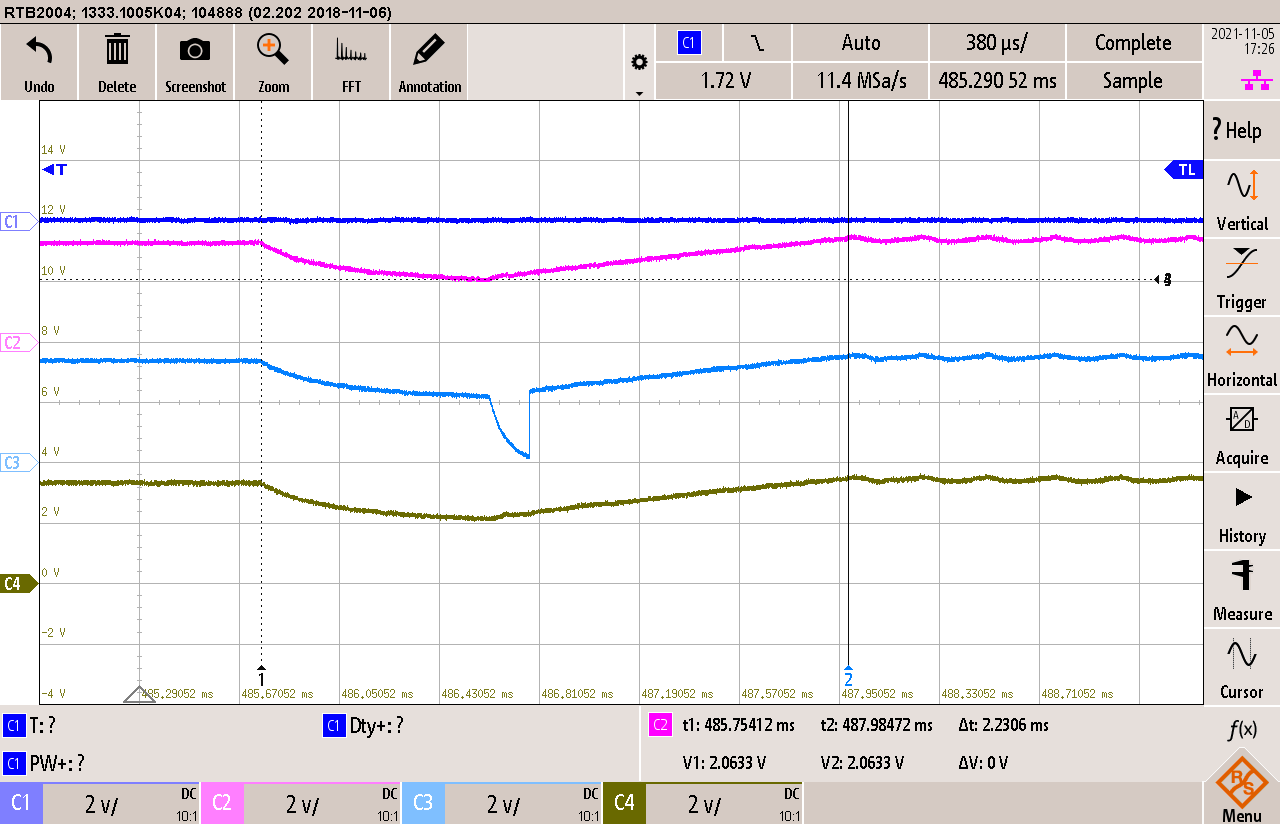
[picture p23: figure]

Pour effet comparatif, la mesure avec l’allumage des LED comme précédemment sans RC a été effectuée avec le RC monté. Le même problème est observé.

Les chutes de tensions interviennent lors de l’affichage des LED uniquement lors d’alimentation par l’élévateur, je suppose donc que l’élévateur ne parvient pas à fournir l’appel de courant créer par l’affichage. Je suppose qu’il serait possible de régler ce problème en utilisant un condensateur en sortie de l’élévateur avec une capacité suffisante pour compenser la demande d’énergie.

## Test fonctionnement D1

La diode D1 avait été prévu dans le cas où la diode du MOSFET Q1 demanderait trop de tension pour conduire et empêcherait d’avoir la tension minimum de conduction du FET.

Pour tester le besoin de cette diode, la diode D1 n’a dans un premier temps pas été monté et à l’aide d’une alimentation, la conduction du MOSFET a été testé à 1.5V d’entrée et 1V d’entrée (tensions de pile pleine et pile vide). Dans les deux cas la conduction s’est faite ce qui montre donc que la diode D1 n’est finalement pas nécessaire. Cependant il est possible que le seuil de conduction de la diode du MOSFET et le seuil de conduction VGS soit à l’avantage et que sur une série de 100 dés, quelques-uns peuvent se retrouver avec les seuils à désavantage et dans ce cas, D1 resterait nécessaire. Par précaution, la diode restera sur le montage.

# Conclusion

## Priorités

Les priorités quant à l’élaboration du projet ont été redéfini en cours de réalisation, selon le planning, après la commande du PCB, le boitier devait être créé. Celui-ci n’étant finalement pas la partie importante, il a été laissé pour la fin, de plus la forme de la carte pourrait être changé sur la version finale, le boitier n’est donc que la dernière chose à concevoir.

Pour commencer c’est la validation du microcontrôleur qui était prioritaire puis de l’accéléromètre avec communication entre les deux. Ensuite la partie alimentation, suivi du maintien d’alimentation, de la détection de première mise sous tension et enfin du boitier.

## Problèmes rencontrés

### SPI

#### Inversion des signaux :

Lors de la conception schématique, une confusion avec les signaux SDI et SDO est intervenu, le signal out du microcontrôleur avait été connecté au signal out de l’accéléromètre, idem avec les signal in SPI.

Les pistes ont été coupées et des fils connectés correctement.

#### Clock

Au départ, la communication SPI ne fonctionnait pas, ceci était dû au clock qui n’était pas correctement réglé et a dû être réglé à l’aide de mesure des signaux.

(Se référer à la partie configuration du SPI)

### PCB

#### Composant manquant

L’ajout de la détection de première mise sous tension avait été effectuée avec précipitation et la résistance n’a pas eu de désignation. Lors de l’importation sur le PCB le message d’erreur n’a pas été vu et la résistance n’est pas présente sur le PCB

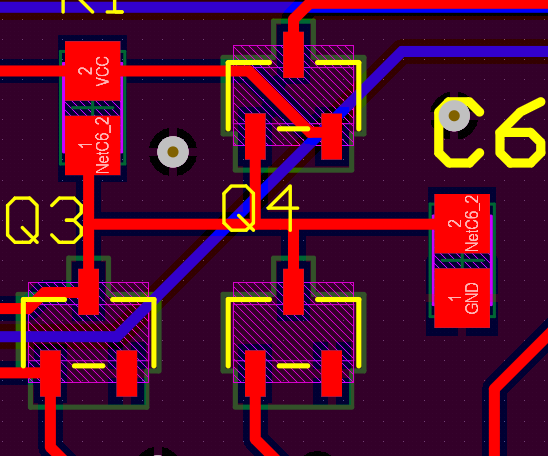
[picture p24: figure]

### Pull-down

Précisé dans la partie Tests et Mesures, la gate des MOSFET de maintien d’alimentation était en l’air et des conductions non désirées sont apparus. Des pull-down ont donc été ajoutées.

### Génération de fichier bug

Lors de la création du projet, un bug soft est intervenu lors la génération des fichiers. Celui-ci ne faisait plus lien correctement avec l’exploration de fichier et les fichiers. La conséquence fut l’incapacité d’ouvrir les fichiers du projet pour les modifier. Le problème fut persistant malgré plusieurs essais différents pour le régler. Finalement le bug avait disparu le lendemain, mais a fait perdre une grande partie de la journée.

### Configuration de l’interruption accéléromètre

La plus grosse difficulté rencontrée était la configuration de l’interruption de l’accéléromètre. Plusieurs jours ont été utilisés pour parvenir à comprendre comment configurer correctement l’interruption. Après plusieurs tests différents, des exemples recherchés, la solution a été trouvé avec l’aide du maître de diplôme.

Ne trouvant pas de solution, j’ai laissé de côté un moment le soft pour monter et valider l’alimentation sur une deuxième carte PCB.

## Conclusion du projet

### Communication

La communication entre l’accéléromètre et le microcontrôleur fonctionne parfaitement, on peut lire et écrire dans les registres. La configuration fonctionne ainsi que l’interruption lors de secoument.

### Génération de chiffre aléatoire

La génération du chiffre aléatoire n’est pas mentionnée dans le rapport car les mesures de validation n’ont pas été effectuées par manque de temps. Des tests rapides ont été fait. La génération aléatoire semble correctement fonctionnelle mais par manque de mesure et de test de répétition, cette partie n’est pas validé.

### Détection de mise de pile

La détection de mise de pile est fonctionnelle comme souhaité avec le RC.

### Détection de secouement

La détection de secouement fonctionne et l’accéléromètre parvient à réveiller le microcontrôleur.

### Alimentation

L’élévateur parvient à créer du 3.3V avec la tension d’une pile pleine et vide.

### Durée d’affichage

La durée d’affichage de 10 sec a été rapidement hors mesure et fonctionnait correctement.

### Chute de tension

Le dysfonctionnement observé et mesuré du système provient par supposition d’une demande de courant lors de l’allumage des LED que l’élévateur ne parvient pas à fournir. La tension d’alimentation du microcontrôleur chutant trop, provoque un dysfonctionnement de celui-ci.

### Boitier

Par manque de temps et n’étant que la dernière priorité du projet, le boitier n’a pas été conçu.

## Améliorations

### Alimentation

Je suppose qu’il serait possible d’utiliser un condensateur de sortie d’élévateur avec une meilleure capacité afin de fournir l’énergie demandé lors de l’allumage des LED et compensé la chute de tension avec le condensateur pour l’annuler.

Le dimensionnement avait été effectué avec une approximation de courant max de sortie à 20mA qui après constat du dysfonctionnement n’est pas le cas. La consommation est plus élevée mais n’a pas pu être correctement mesurée dû au LED qui ne parviennent à s’allumer correctement.

### Renommage des fonctions

Renommer les fonctions du soft pour les rendre plus compréhensible.

## Suite du projet

Il reste au projet de régler le problème de chute de tension trop élevé. De terminer et valider le soft.

Ainsi que d’effectué les modifications nécessaire (voir fichier de modification).

## Suivi du planning

Voir le suivi d’avancement en annexe

Globalement, le planning a assez bien été suivi, avec un peu de retard. La dernière semaine, plusieurs tâches ont été effectuées le planning n’est plus suivi. Ce fait dû au problème de configuration de l’interrupt Shake rencontré et du choix de mettre un peu de côté ce point pour tester la partie alimentation.

Lausanne le, 8 novembre 2021

Maxime Colloud

# Annexes

- Cahier des charge
- Planning
- Suivi d’avancement
- Schéma électrique
- Évaluation des couts
- Fichiers soft accéléromètre et projet
- Journal de travail
- Procès-verbaux

Page 47 sur 47 08.11.2021

Maxime Colloud 2113_DeElectronique

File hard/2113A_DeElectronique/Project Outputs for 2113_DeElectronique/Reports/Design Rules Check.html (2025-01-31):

Altium

# Design Rule Verification Report

Date: | | 15.10.2021
Time: | | 16:04:30
Elapsed Time: | | 00:00:01
Filename: | | C:\Users\Public\Documents\Altium\Projects\2113_DeElectronique\2113_DeElectronique.PcbDoc

Warnings: | | 0
Rule Violations: | | 0

## Summary

Warnings | Count
Total | 0

Rule Violations | Count
Clearance Constraint (Gap=0.15mm) (All),(All) | 0
Short-Circuit Constraint (Allowed=No) (All),(All) | 0
Un-Routed Net Constraint ( (All) ) | 0
Modified Polygon (Allow modified: No), (Allow shelved: No) | 0
Width Constraint (Min=0.15mm) (Max=1.5mm) (Preferred=0.2mm) (All) | 0
Power Plane Connect Rule(Relief Connect )(Expansion=0.175mm) (Conductor Width=0.2mm) (Air Gap=0.2mm) (Entries=4) (All) | 0
Minimum Annular Ring (Minimum=0.175mm) (((ObjectKind = 'Pad') OR (ObjectKind = 'Via')) And (Layer = 'MultiLayer') And (HoleDiameter <= AsMM(0.45))) | 0
Minimum Annular Ring (Minimum=0.175mm) (((ObjectKind = 'Pad') OR (ObjectKind = 'Via')) And (Layer = 'MultiLayer') And (HoleDiameter > AsMM(0.45))) | 0
Hole Size Constraint (Min=0.25mm) (Max=10mm) (All) | 0
Hole To Hole Clearance (Gap=0.35mm) (All),(All) | 0
Minimum Solder Mask Sliver (Gap=0.08mm) (All),(All) | 0
Silk To Solder Mask (Clearance=0.2mm) (IsPad),(All) | 0
Silk to Silk (Clearance=0.2mm) (All),(All) | 0
Net Antennae (Tolerance=0mm) (All) | 0
Board Clearance Constraint (Gap=0mm) (All) | 0
Height Constraint (Min=0mm) (Max=25mm) (Prefered=12.5mm) (All) | 0
Total | 0

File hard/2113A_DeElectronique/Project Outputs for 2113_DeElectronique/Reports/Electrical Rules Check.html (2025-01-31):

Altium

# Electrical Rule Check Report

Date: | | 15.10.2021
Time: | | 16:04:31
Filename: | | C:\Users\Public\Documents\Altium\Projects\2113_DeElectronique\Project Outputs for 2113_DeElectronique\Reports\Electrical Rules Check.html

Class | Document | Message
Warning | 2113_DeElectrinique.SchDoc | NetD4_2 contains IO Pin and Unspecified Port objects (Pin U3-3, Port LED1, Port LED1).
Warning | 2113_DeElectrinique.SchDoc | NetD6_2 contains IO Pin and Unspecified Port objects (Pin U3-6, Port LED3, Port LED3).
Warning | 2113_DeElectrinique.SchDoc | NetD8_2 contains IO Pin and Unspecified Port objects (Pin U3-9, Port LED5, Port LED5).
Warning | 2113_DeElectrinique.SchDoc | NetD9_2 contains IO Pin and Unspecified Port objects (Pin U3-10, Port LED6, Port LED6).
Warning | 2113_DeElectrinique.SchDoc | NetP1_4 contains IO Pin and Unspecified Port objects (Pin U3-4, Port PGED, Port PGED).
Warning | 2113_DeElectrinique.SchDoc | NetP1_5 contains IO Pin and Unspecified Port objects (Pin U3-5, Port PGEC, Port PGEC).
Warning | 2113_DeElectrinique.SchDoc | NetQ3_1 contains IO Pin and Output Pin objects (Pin U3-15, Pin U2-5).
Warning | 2113_DeElectrinique.SchDoc | NetQ3_1 contains IO Pin and Unspecified Port objects (Pin U3-15, Port INT1, Port INT1, Port INT1).
Warning | 2113_DeElectrinique.SchDoc | NetQ3_1 contains Output Pin and Unspecified Port objects (Pin U2-5, Port INT1, Port INT1, Port INT1).
Warning | 2113_DeElectrinique.SchDoc | NetQ4_1 contains IO Pin and Unspecified Port objects (Pin U3-16, Port HOLD, Port HOLD).
Warning | 2113_DeElectrinique.SchDoc | NetU2_1 contains IO Pin and Unspecified Port objects (Pin U2-1, Pin U3-13, Port SDO, Port SDO).
Warning | 2113_DeElectrinique.SchDoc | NetU2_2 contains IO Pin and Unspecified Port objects (Pin U2-2, Pin U3-17, Port SDI, Port SDI).
Warning | 2113_DeElectrinique.SchDoc | NetU2_10 contains Input Pin and Unspecified Port objects (Pin U2-10, Port SS1, Port SS1).
Warning | 2113_DeElectrinique.SchDoc | NetU2_10 contains IO Pin and Unspecified Port objects (Pin U3-18, Port SS1, Port SS1).
Warning | 2113_DeElectrinique.SchDoc | NetU2_12 contains Input Pin and Unspecified Port objects (Pin U2-12, Port SCK, Port SCK).
Warning | 2113_DeElectrinique.SchDoc | NetU2_12 contains IO Pin and Unspecified Port objects (Pin U3-12, Port SCK, Port SCK).
Warning | 2113_DeElectrinique.SchDoc | Un-Designated Part R?

Back to top

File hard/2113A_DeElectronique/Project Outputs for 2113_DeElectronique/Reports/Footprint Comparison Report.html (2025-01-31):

Altium customize

# Footprint Comparison Report

Date: | | 15.10.2021
Time: | | 16:04:32
Elapsed Time: | | 00:00:00
Filename: | | C:\Users\Public\Documents\Altium\Projects\2113_DeElectronique\2113_DeElectronique.PcbDoc

## Contents

Contents

Components Status Summary

Matched Components List

Missing PCB Components List

## Components Status Summary

## Matched Components List

Designator | Footprint | Footprint reference | Footprint to reference Library
B1 | BK-53 | BK-53 | C:\Users\Public\Documents\Altium\Projects\2113_DeElectronique\2113_DeElectronique.PcbLib
C1 | CONDO_0805 | Condo_0805 | C:\Users\Public\Documents\Altium\Projects\2113_DeElectronique\2113_DeElectronique.PcbLib
C2 | CONDO_0805 | Condo_0805 | C:\Users\Public\Documents\Altium\Projects\2113_DeElectronique\2113_DeElectronique.PcbLib
C3 | CONDO_0805 | Condo_0805 | C:\Users\Public\Documents\Altium\Projects\2113_DeElectronique\2113_DeElectronique.PcbLib
C4 | CONDO_0805 | Condo_0805 | C:\Users\Public\Documents\Altium\Projects\2113_DeElectronique\2113_DeElectronique.PcbLib
C5 | CONDO_0805 | Condo_0805 | C:\Users\Public\Documents\Altium\Projects\2113_DeElectronique\2113_DeElectronique.PcbLib
C6 | Condo_0805 | Condo_0805 | C:\Users\Public\Documents\Altium\Projects\2113_DeElectronique\2113_DeElectronique.PcbLib
D1 | SOT23-3 | SOT23-3 | C:\Users\Public\Documents\Altium\Projects\2113_DeElectronique\2113_DeElectronique.PcbLib
D2 | DO-214AC | DO-214AC | C:\Users\Public\Documents\Altium\Projects\2113_DeElectronique\2113_DeElectronique.PcbLib
D3 | LED_0805 | LED_0805 | C:\Users\Public\Documents\Altium\Projects\2113_DeElectronique\2113_DeElectronique.PcbLib
D4 | LED_0805 | LED_0805 | C:\Users\Public\Documents\Altium\Projects\2113_DeElectronique\2113_DeElectronique.PcbLib
D5 | LED_0805 | LED_0805 | C:\Users\Public\Documents\Altium\Projects\2113_DeElectronique\2113_DeElectronique.PcbLib
D6 | LED_0805 | LED_0805 | C:\Users\Public\Documents\Altium\Projects\2113_DeElectronique\2113_DeElectronique.PcbLib
D7 | LED_0805 | LED_0805 | C:\Users\Public\Documents\Altium\Projects\2113_DeElectronique\2113_DeElectronique.PcbLib
D8 | LED_0805 | LED_0805 | C:\Users\Public\Documents\Altium\Projects\2113_DeElectronique\2113_DeElectronique.PcbLib
D9 | LED_0805 | LED_0805 | C:\Users\Public\Documents\Altium\Projects\2113_DeElectronique\2113_DeElectronique.PcbLib
L1 | self 1206 (3225) | self 1206 (3225) | C:\Users\Public\Documents\Altium\Projects\2113_DeElectronique\2113_DeElectronique.PcbLib
P1 | TAC_CONTACT_PROG | TAC_Contact_Prog | C:\Users\Public\Documents\Altium\Projects\2113_DeElectronique\2113_DeElectronique.PcbLib
Q1 | SOT23-3 | SOT23-3 | C:\Users\Public\Documents\Altium\Projects\2113_DeElectronique\2113_DeElectronique.PcbLib
Q2 | SOT23-3 | SOT23-3 | C:\Users\Public\Documents\Altium\Projects\2113_DeElectronique\2113_DeElectronique.PcbLib
Q3 | SOT23-3 | SOT23-3 | C:\Users\Public\Documents\Altium\Projects\2113_DeElectronique\2113_DeElectronique.PcbLib
Q4 | SOT23-3 | SOT23-3 | C:\Users\Public\Documents\Altium\Projects\2113_DeElectronique\2113_DeElectronique.PcbLib
R1 | RES_0805 | Res_0805 | C:\Users\Public\Documents\Altium\Projects\2113_DeElectronique\2113_DeElectronique.PcbLib
R2 | RES_0805 | Res_0805 | C:\Users\Public\Documents\Altium\Projects\2113_DeElectronique\2113_DeElectronique.PcbLib
R3 | RES_0805 | Res_0805 | C:\Users\Public\Documents\Altium\Projects\2113_DeElectronique\2113_DeElectronique.PcbLib
R4 | RES_0805 | Res_0805 | C:\Users\Public\Documents\Altium\Projects\2113_DeElectronique\2113_DeElectronique.PcbLib
R5 | RES_0805 | Res_0805 | C:\Users\Public\Documents\Altium\Projects\2113_DeElectronique\2113_DeElectronique.PcbLib
R6 | RES_0805 | Res_0805 | C:\Users\Public\Documents\Altium\Projects\2113_DeElectronique\2113_DeElectronique.PcbLib
R7 | RES_0805 | Res_0805 | C:\Users\Public\Documents\Altium\Projects\2113_DeElectronique\2113_DeElectronique.PcbLib
R8 | RES_0805 | Res_0805 | C:\Users\Public\Documents\Altium\Projects\2113_DeElectronique\2113_DeElectronique.PcbLib
R9 | RES_0805 | Res_0805 | C:\Users\Public\Documents\Altium\Projects\2113_DeElectronique\2113_DeElectronique.PcbLib
R10 | RES_0805 | Res_0805 | C:\Users\Public\Documents\Altium\Projects\2113_DeElectronique\2113_DeElectronique.PcbLib
S1 | PTS647SN50SMTR2LFS | PTS647SN50SMTR2LFS | C:\Users\Public\Documents\Altium\Projects\2113_DeElectronique\2113_DeElectronique.PcbLib
U1 | SOT23-5 | SOT23-5 | C:\Users\Public\Documents\Altium\Projects\2113_DeElectronique\2113_DeElectronique.PcbLib
U2 | MC3419 | MC3419 | C:\Users\Public\Documents\Altium\Projects\2113_DeElectronique\2113_DeElectronique.PcbLib
U3 | SSOP20_SS_MCH | SSOP20_SS_MCH | C:\Users\Public\Documents\Altium\Projects\2113_DeElectronique\2113_DeElectronique.PcbLib

Back to top

## Missing PCB Components List

Designator | Footprint | Footprint reference | Path to reference Library
R? | | Res_0805 | C:\Users\Public\Documents\Altium\Projects\2113_DeElectronique\2113_DeElectronique.PcbLib

Back to top

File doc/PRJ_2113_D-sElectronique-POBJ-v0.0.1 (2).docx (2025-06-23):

# Projet ETML-ES – Modification POBJ

Note: Les textes explicatifs en italique peuvent être supprimés

A remplir par l'initiateur

PROJET: | 2113-D-sElectronique
Entreprise/Client: | ETML-ES | Département: | SLO
Demandé par (Prénom, Nom): | | Date: | -
Objet (No ou réf, pièce, PCB...) | Software / Firmware
Version à modifier: | V2.X

A remplir par l'exécutant

Auteur (ETML-ES): | Aymeric Clauzel | Filière: | SLO
Nouvelle version: | V3 | Date: | 03.02.2025

# 1 Projet

## 1.1 Description sommaire du projet à modifier

Il s’agit de réaliser un dé électronique qui puisse être produit en petite série à l’ETML et distribué aux visiteurs de l’ES, par exemple lors des portes ouvertes. S’agissant d’un cadeau, une attention particulière sera portée à la minimalisation des coûts. Le fonctionnement sera le suivant :

Lorsque le montage est secoué puis reposé à l’horizontale, un nombre aléatoire entre 1 et 6 sera affiché à l’aide de 7 LEDs. Il ne doit y avoir aucun bouton. Les LED seront disposées à la manière d’un dé à lancer. Les LED restent allumées 10 secondes, puis le montage s’éteint (coupure d’alimentation totale, sauf pour l’élément de détection du secouement). Ce dernier est le seul sous tension en permanence et réveille le montage à chaque nouveau secouement.

## 1.2 Référence conception

Disponibles dans le dossier du projet (rapport, cdc…):
K:\ES\PROJETS\SLO\2113_DeElectronique

# 2 Objectifs principaux des modifications ou ajouts

L’objectif principale est de faire en sorte qu’à chaque secouement les leds s’allument pendant 10 secondes avant de s’éteindre. Un nouveau secouement doit redéclencher le roll du dé, peu importe la force ou le temps. L’extinction totale du système se fait en retirant la pille.

# 3 Résumé de l’état actuel

Actuellement l’allumage des LEDS ne correspond pas à la demande du cdc, parfois elles ne s’allument pas. Parfois il faut secouer pendant longtemps avant que les leds s’allument.

# 4 Tâches à réaliser

## 4.1 Livrable

Firmware ou software qui réalise la ou les fonctions demandées par le CDC, dans sa version 3. structogramme / flow chart du fonctionnement principal.
Flow chart/détails des fonctions sous formes de diagrammes de flux/structo.

## 4.2 Archivage sur Github (optionnel)

Le projet est archivé sur Git selon accord avec le mandant

https://github.com/ETML-ES-SLO/PRJ_2113_D-sElectronique

Donner les droits de collaboration

## 4.3 Table des tâches à réaliser

Contenu du tableau ci-dessous en exemple

# | Priorité | Description | Fait | Vu

1 | 3 | Lire le rapport effectué par MAXIME COLLOUD | ok
2 | 2 | Créer un nouveau projet dans l’environnement Mplab(v3) | ok
3 | 2 | Tester le fonctionnement actuel | ok
4 | 1 | Faire le descriptif détaillé avec lien correspondant au soft actuel | Nok
5 | 1 | Maitrise des registres de configuration accéléromètre | Ok
6 | 1 | Test de gestion de l’interruption de Wake-up | Ok
7 | 1 | Faire nouveau structo/flow chart | ok
8 | 1 | Faire les modifications nécessaires du soft | ok
9 | 1 | Tester le fonctionnement final | ok
10 | 2 | Faire le descriptif détaillé avec lien correspondant au soft actuel | nok
11 | 1 | Valider le fonctionnement avec client | Ok
n | 1 | Documenter tout le travail effectué. | X

1 = Elevé 2 = Moyen 3 = Faible

# 5 Détail des modifications ou ajouts

# | Description | Fait | Approuvé

1 | Réaliser une fonction PWM, pour gérer l’allumage des LEDs (0-100%) | x
2 | Modification de la fonction d’attente (bloquante) | x
3 | Modifier si nécessaire la gestion de l’interruption de l’accéléromètre | Pas besoin
4 | Réaliser une rampe pour l’allumage et l’extinction des LEDs | x
5 | Refractor structure principale pour SM | x
6 | Ajout de la détection d’une interruption anymotion pour plus de fluidité | x
7 | Crée une fonction qui a pour seul but de Clear l’interruption | x
8 | Utiliser le CoreTimer pour modifier la consigne de Rapport cyclique (inutilisée) | x
9 | Création d’un Readme pour le repo | x

# 6 Matériel nécessaire

- MPLAB X version IDE 5.15→ V5.5 et version compilateur 2.15→ V2.5
- PCB_DéElectronique Version « E »
- Débugger : Mplab-ICD4 / Snap

## 6.1 Stockage du fichier

Ce fichier sera stocké à la racine du dossier /doc du projet 2113_DeElectronique.

Ainsi, tous les fichiers de modifications des pièces ou PCBs faisant partie du projet sont centralisés dans le même répertoire. La numérotation devient implicite.

## 6.2 Stockage des logiciels

Les codes sources sont stockés ici :

Racine du dossier /soft

Ou sur GitHub :

https://github.com/ETML-ES-SLO/PRJ_2113_D-sElectronique

JMO – Nov 20182203_Bootloader-MOD-V2.0.docxPage 1

ECOLE SUPERIEURE ELCO – SLO

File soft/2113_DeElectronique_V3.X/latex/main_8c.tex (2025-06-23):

\doxysection{main.\+c File Reference}
\hypertarget{main_8c}{}\label{main_8c}\index{main.c@{main.c}}
{\ttfamily \#include "{}Main.\+h"{}}\newline
{\ttfamily \#include "{}Mc32\+Delays.\+h"{}}\newline
{\ttfamily \#include "{}mcc\+\_\+generated\+\_\+files/system.\+h"{}}\newline
{\ttfamily \#include "{}mcc\+\_\+generated\+\_\+files/spi1.\+h"{}}\newline
{\ttfamily \#include "{}mcc\+\_\+generated\+\_\+files/pin\+\_\+manager.\+h"{}}\newline
{\ttfamily \#include "{}Accelerometre.\+h"{}}\newline
{\ttfamily \#include "{}De\+Electronique.\+h"{}}\newline
{\ttfamily \#include "{}mcc\+\_\+generated\+\_\+files/tmr1.\+h"{}}\newline
{\ttfamily \#include $<$stdbool.\+h$>$}\newline
{\ttfamily \#include $<$stdlib.\+h$>$}\newline
Include dependency graph for main.\+c\+:\nopagebreak
\begin{figure}[H]
\begin{center}
\leavevmode

\end{center}
\end{figure}
\doxysubsubsection*{Functions}
\begin{DoxyCompactItemize}
\item 
int \mbox{\hyperlink{main_8c_a840291bc02cba5474a4cb46a9b9566fe}{main}} (void)
\begin{DoxyCompactList}\small\item\em Point d\textquotesingle{}entrée principal de l\textquotesingle{}application. \end{DoxyCompactList}\item 
void \mbox{\hyperlink{main_8c_af345062c9eb0b26d8fac05edc69e3e03}{APP\+\_\+\+TMR1\+\_\+\+Call\+Back}} (void)
\begin{DoxyCompactList}\small\item\em Callback du timer 1, décrémente le délai stocké dans App\+Data. \end{DoxyCompactList}\item 
void \mbox{\hyperlink{main_8c_abcbd1769c7d03ea90681c10fe1f03775}{APP\+\_\+\+Wait\+Start}} (uint16\+\_\+t waiting\+Time\+\_\+ms)
\begin{DoxyCompactList}\small\item\em Attente bloquante pendant un temps donné en ms (utilise le timer 1). \end{DoxyCompactList}\item 
void \mbox{\hyperlink{main_8c_a4fa8fbe773cf61081a19c1a85c05ff51}{Set\+States}} (\mbox{\hyperlink{_main_8h_aa19be6305a5a4485e1e70de70ed7d677}{states}} newstate)
\begin{DoxyCompactList}\small\item\em Change l\textquotesingle{}état courant de l\textquotesingle{}application. \end{DoxyCompactList}\item 
void \mbox{\hyperlink{main_8c_a096c0676aeef0819a2515076d21a363e}{APP\+\_\+\+CORETIMER\+\_\+\+CALLBACK}} (void)
\begin{DoxyCompactList}\small\item\em Callback du core timer pour gérer la variation de RC. \end{DoxyCompactList}\end{DoxyCompactItemize}
\doxysubsubsection*{Variables}
\begin{DoxyCompactItemize}
\item 
\mbox{\hyperlink{structapp_data}{app\+Data}} \mbox{\hyperlink{main_8c_a49a8f8cf002afdba8fdadf6769c332c9}{appdata}}
\end{DoxyCompactItemize}

\doxysubsection{Function Documentation}
\Hypertarget{main_8c_a096c0676aeef0819a2515076d21a363e}\index{main.c@{main.c}!APP\_CORETIMER\_CALLBACK@{APP\_CORETIMER\_CALLBACK}}
\index{APP\_CORETIMER\_CALLBACK@{APP\_CORETIMER\_CALLBACK}!main.c@{main.c}}
\doxysubsubsection{\texorpdfstring{APP\_CORETIMER\_CALLBACK()}{APP\_CORETIMER\_CALLBACK()}}
{\footnotesize\ttfamily \label{main_8c_a096c0676aeef0819a2515076d21a363e} 
void APP\+\_\+\+CORETIMER\+\_\+\+CALLBACK (\begin{DoxyParamCaption}\item[{void}]{}{}\end{DoxyParamCaption})}

Callback du core timer pour gérer la variation de RC. 

\Hypertarget{main_8c_af345062c9eb0b26d8fac05edc69e3e03}\index{main.c@{main.c}!APP\_TMR1\_CallBack@{APP\_TMR1\_CallBack}}
\index{APP\_TMR1\_CallBack@{APP\_TMR1\_CallBack}!main.c@{main.c}}
\doxysubsubsection{\texorpdfstring{APP\_TMR1\_CallBack()}{APP\_TMR1\_CallBack()}}
{\footnotesize\ttfamily \label{main_8c_af345062c9eb0b26d8fac05edc69e3e03} 
void APP\+\_\+\+TMR1\+\_\+\+Call\+Back (\begin{DoxyParamCaption}\item[{void}]{}{}\end{DoxyParamCaption})}

Callback du timer 1, décrémente le délai stocké dans App\+Data. 

End of File \Hypertarget{main_8c_abcbd1769c7d03ea90681c10fe1f03775}\index{main.c@{main.c}!APP\_WaitStart@{APP\_WaitStart}}
\index{APP\_WaitStart@{APP\_WaitStart}!main.c@{main.c}}
\doxysubsubsection{\texorpdfstring{APP\_WaitStart()}{APP\_WaitStart()}}
{\footnotesize\ttfamily \label{main_8c_abcbd1769c7d03ea90681c10fe1f03775} 
void APP\+\_\+\+Wait\+Start (\begin{DoxyParamCaption}\item[{uint16\+\_\+t}]{waiting\+Time\+\_\+ms}{}\end{DoxyParamCaption})}

Attente bloquante pendant un temps donné en ms (utilise le timer 1). 

Lance une attente bloquante pendant un temps donné (ms).

\begin{DoxyParams}{Parameters}
{\em waiting\+Time\+\_\+ms} & Durée d\textquotesingle{}attente en millisecondes \\
\hline
\end{DoxyParams}
Here is the call graph for this function\+:\nopagebreak
\begin{figure}[H]
\begin{center}
\leavevmode

\end{center}
\end{figure}
Here is the caller graph for this function\+:\nopagebreak
\begin{figure}[H]
\begin{center}
\leavevmode

\end{center}
\end{figure}
\Hypertarget{main_8c_a840291bc02cba5474a4cb46a9b9566fe}\index{main.c@{main.c}!main@{main}}
\index{main@{main}!main.c@{main.c}}
\doxysubsubsection{\texorpdfstring{main()}{main()}}
{\footnotesize\ttfamily \label{main_8c_a840291bc02cba5474a4cb46a9b9566fe} 
int main (\begin{DoxyParamCaption}\item[{void}]{}{}\end{DoxyParamCaption})}

Point d\textquotesingle{}entrée principal de l\textquotesingle{}application. 

\begin{DoxyReturn}{Returns}
1 en cas de fin de programme 
\end{DoxyReturn}
Initialisation de l\textquotesingle{}application.

\begin{DoxyItemize}
\item Configure le système et les périphériques.
\item Définit les valeurs par défaut des variables d\textquotesingle{}état.
\item Vérifie l\textquotesingle{}absence d\textquotesingle{}interruption pour configurer l\textquotesingle{}accéléromètre.
\item Passe à l\textquotesingle{}état d\textquotesingle{}attente d\textquotesingle{}interruption.
\end{DoxyItemize}

Attente d\textquotesingle{}une interruption de l\textquotesingle{}accéléromètre.

\begin{DoxyItemize}
\item Lit le registre d\textquotesingle{}état de l\textquotesingle{}accéléromètre.
\item Vérifie les interruptions de type "{}shake"{} et "{}any motion"{}.
\item Si une interruption est détectée et que c\textquotesingle{}est la première fois depuis la mise sous tension, passe à l\textquotesingle{}état de calcul.
\end{DoxyItemize}

Calcule la valeur pseudo-\/aléatoire du dé à partir des registres de l\textquotesingle{}accéléromètre.

\begin{DoxyItemize}
\item Additionne les valeurs des axes X, Y, Z pour obtenir une graine.
\item Utilise srand/rand pour générer un nombre pseudo-\/aléatoire.
\item Garantit que le résultat est compris entre 1 et 6 (jamais 0).
\item Passe à l\textquotesingle{}état d\textquotesingle{}affichage.
\end{DoxyItemize}

Prépare l\textquotesingle{}affichage du résultat sur les LEDs.

\begin{DoxyItemize}
\item Initialise le rapport cyclique PWM (RC) à 10.
\item Active l\textquotesingle{}affichage (disp=1).
\item Passe à l\textquotesingle{}état d\textquotesingle{}attente d\textquotesingle{}affichage.
\end{DoxyItemize}

Lance l\textquotesingle{}attente d\textquotesingle{}affichage du résultat.

\begin{DoxyItemize}
\item Démarre l\textquotesingle{}attente bloquante (affichage du dé).
\item Passe à l\textquotesingle{}état d\textquotesingle{}extinction.
\end{DoxyItemize}

Éteint les LEDs et met le système en veille si aucune interruption n\textquotesingle{}est détectée.

\begin{DoxyItemize}
\item Éteint l\textquotesingle{}affichage.
\item Efface les interruptions de l\textquotesingle{}accéléromètre.
\item Si aucune interruption, coupe l\textquotesingle{}alimentation et boucle infinie pour arrêt total.
\end{DoxyItemize}Here is the call graph for this function\+:\nopagebreak
\begin{figure}[H]
\begin{center}
\leavevmode

\end{center}
\end{figure}
\Hypertarget{main_8c_a4fa8fbe773cf61081a19c1a85c05ff51}\index{main.c@{main.c}!SetStates@{SetStates}}
\index{SetStates@{SetStates}!main.c@{main.c}}
\doxysubsubsection{\texorpdfstring{SetStates()}{SetStates()}}
{\footnotesize\ttfamily \label{main_8c_a4fa8fbe773cf61081a19c1a85c05ff51} 
void Set\+States (\begin{DoxyParamCaption}\item[{\mbox{\hyperlink{_main_8h_aa19be6305a5a4485e1e70de70ed7d677}{states}}}]{newstate}{}\end{DoxyParamCaption})}

Change l\textquotesingle{}état courant de l\textquotesingle{}application. 

\begin{DoxyParams}{Parameters}
{\em newstate} & Nouvel état à appliquer \\
\hline
\end{DoxyParams}
Here is the caller graph for this function\+:\nopagebreak
\begin{figure}[H]
\begin{center}
\leavevmode

\end{center}
\end{figure}

\doxysubsection{Variable Documentation}
\Hypertarget{main_8c_a49a8f8cf002afdba8fdadf6769c332c9}\index{main.c@{main.c}!appdata@{appdata}}
\index{appdata@{appdata}!main.c@{main.c}}
\doxysubsubsection{\texorpdfstring{appdata}{appdata}}
{\footnotesize\ttfamily \label{main_8c_a49a8f8cf002afdba8fdadf6769c332c9} 
\mbox{\hyperlink{structapp_data}{app\+Data}} appdata}

Generated \doxylink{main_8c}{main.\+c} file from MPLAB Code Configurator

@\+Company Microchip Technology Inc.

@\+File Name \doxylink{main_8c}{main.\+c} la

@\+Summary This is the generated \doxylink{main_8c}{main.\+c} using PIC24 / ds\+PIC33 / PIC32\+MM MCUs.

@\+Description This source file provides main entry point for system intialization and application code development. Generation Information \+: Product Revision \+: PIC24 / ds\+PIC33 / PIC32\+MM MCUs -\/ 1.\+75.\+1 Device \+: PIC32\+MM0064\+GPL020 The generated drivers are tested against the following\+: Compiler \+: XC16 v1.\+35 MPLAB \+: MPLAB X v5.\+05 Section\+: Included Files

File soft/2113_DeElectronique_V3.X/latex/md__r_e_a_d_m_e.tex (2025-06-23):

\chapter{2113\+\_\+\+De\+Electronique\+\_\+\+V3}
\hypertarget{md__r_e_a_d_m_e}{}\label{md__r_e_a_d_m_e}\index{2113\_DeElectronique\_V3@{2113\_DeElectronique\_V3}}
\label{md__r_e_a_d_m_e_autotoc_md0}%
\Hypertarget{md__r_e_a_d_m_e_autotoc_md0}%

Ce projet implémente une application pour microcontrôleur PIC32\+MM0064\+GPL020, développée avec MPLAB X et XC32.\hypertarget{md__r_e_a_d_m_e_autotoc_md1}{}\doxysection{\texorpdfstring{Sommaire}{Sommaire}}\label{md__r_e_a_d_m_e_autotoc_md1}

\begin{DoxyItemize}
\item Présentation
\item Informations de génération
\item Compilation
\item Utilisation
\item Documentation Doxygen
\item Diagrammes
\item Ressources
\end{DoxyItemize}\hypertarget{md__r_e_a_d_m_e_autotoc_md2}{}\doxysection{\texorpdfstring{Présentation}{Présentation}}\label{md__r_e_a_d_m_e_autotoc_md2}
Ce dépôt contient le code source et la configuration pour le projet électronique basé sur le PIC32\+MM. ~\newline
 La documentation technique est générée avec Doxygen.\hypertarget{md__r_e_a_d_m_e_autotoc_md3}{}\doxysection{\texorpdfstring{Modifications apportées entre V2 et V3}{Modifications apportées entre V2 et V3}}\label{md__r_e_a_d_m_e_autotoc_md3}

\begin{DoxyItemize}
\item Modification de la fonction d\textquotesingle{}attente avec utilisation du timer (précision accrue et meilleure gestion du temps).
\item Ajout de la possibilité de modifier le changement de la consigne PWM avec le Core\+Timer (meilleure flexibilité et contrôle).
\item Ajout du réglage d\textquotesingle{}intensité automatique avec les "{}rampes"{} (transition douce de l\textquotesingle{}intensité).
\item Refactorisation et amélioration des commentaires pour une meilleure génération de documentation Doxygen.
\item Refactorisation de la structure principale du main.
\end{DoxyItemize}\hypertarget{md__r_e_a_d_m_e_autotoc_md4}{}\doxysection{\texorpdfstring{Informations de générations}{Informations de générations}}\label{md__r_e_a_d_m_e_autotoc_md4}

\begin{DoxyCode}{0}
\DoxyCodeLine{Product\ Revision\ \ :\ \ PIC24\ /\ dsPIC33\ /\ PIC32MM\ MCUs\ -\/\ 1.75.1}
\DoxyCodeLine{Device\ \ \ \ \ \ \ \ \ \ \ \ :\ \ PIC32MM0064GPL020}
\DoxyCodeLine{}
\DoxyCodeLine{Les\ drivers\ générés\ sont\ testés\ avec\ :}
\DoxyCodeLine{\ \ \ \ Compiler\ \ \ \ \ \ :\ \ XC16\ v1.35}
\DoxyCodeLine{\ \ \ \ MPLAB\ \ \ \ \ \ \ \ \ :\ \ MPLAB\ X\ v5.05}
\DoxyCodeLine{}
\DoxyCodeLine{La\ version\ 3\ de\ cette\ application\ est\ conçue\ et\ testée\ avec\ :}
\DoxyCodeLine{\ \ \ \ Compiler\ \ \ \ \ \ :\ \ XC32\ v2.5\ }
\DoxyCodeLine{\ \ \ \ MPLAB\ \ \ \ \ \ \ \ \ :\ \ MPLAB\ X\ v5.50}

\end{DoxyCode}
\hypertarget{md__r_e_a_d_m_e_autotoc_md5}{}\doxysection{\texorpdfstring{Compilation}{Compilation}}\label{md__r_e_a_d_m_e_autotoc_md5}

\begin{DoxyEnumerate}
\item crée un dossier "{}\+PROJ"{} sous"{} C\+:\textbackslash{}microchip\textbackslash{}harmony\textbackslash{}v2\+\_\+06\textbackslash{}apps\textbackslash{}"{} 2. Cloner ce dépôt à l\textquotesingle{}intérieur  le chemin devrais être \+: "{}C\+:\textbackslash{}microchip\textbackslash{}harmony\textbackslash{}v2\+\_\+06\textbackslash{}apps\textbackslash{}\+PROJ\textbackslash{}\+PRJ\+\_\+2113\+\_\+D-\/s\+Electronique"{} 4. Ouvrez le projet dans MPLAB X. 5. Sélectionnez le compilateur XC32 v2.\+5. 6. Compilez le projet ($<$tt$>$\+Build Project$<$/tt$>$).  @section autotoc\+\_\+md6 Utilisation  -\/ Chargez le firmware sur la carte cible (2113\+E\+\_\+\+De\+Electronique) via MPLAB X (la carte doit être alimentée en +1,5\+V). -\/ Retirer la sonde de programation (snap/icd4) appuyer sur le switch environs 1s. -\/ secouer -\/ pour éteindre\+: retirer la pile   @section autotoc\+\_\+md7 Etat actuel -\/ Possibilité d\textquotesingle{}apparition de l\textquotesingle{}interruption sans que le microcontroleur ne soit totalement éteind/allumé à déterminer.  -\/ Après quelques rolls de dé puis laisser \texorpdfstring{$\sim$}{\string~}2h un roll était toujour possible aucun problème... (n\textquotesingle{}empêche pas le point précédent) @section autotoc\+\_\+md8 Documentation Doxygen  \+La documentation complète du code est disponible dans le dossier $<$a href="{}html/"{} \texorpdfstring{$>$}{>}html/
\end{DoxyEnumerate}. ~\newline
 \href{./html/index.html}{\texttt{ Consulter la documentation Doxygen}} (ouvrir dans un browser une fois le dépot en local) exemple du rendus \+:

\hypertarget{md__r_e_a_d_m_e_autotoc_md9}{}\doxysection{\texorpdfstring{Diagrammes}{Diagrammes}}\label{md__r_e_a_d_m_e_autotoc_md9}
Précédente version (V2)

Nouvelle version (V3)

les autres diagrammes sont disponibles sous "{}\+C\+:\textbackslash{}microchip\textbackslash{}harmony\textbackslash{}v2\+\_\+06\textbackslash{}apps\textbackslash{}\+PROJ\textbackslash{}\+PRJ\+\_\+2113\+\_\+\+D-\/s\+Electronique\textbackslash{}soft\textbackslash{}2113\+\_\+\+De\+Electronique\+\_\+\+V3.\+X\textbackslash{}code2flow"{}

\#\# Ressources

\begin{DoxyItemize}
\item \href{https://app.code2flow.com/}{\texttt{ Diagramme de flux (Code2\+Flow)}}
\item \href{https://code.visualstudio.com/}{\texttt{ VS Code}}
\item \href{https://github.com/features/copilot}{\texttt{ Git\+Hub Copilot}}
\item \href{https://www.microchip.com/en-us/tools-resources/develop/mplab-x-ide}{\texttt{ MPLAB X IDE}}
\item \href{https://graphviz.gitlab.io/}{\texttt{ Graphviz}}
\item \href{https://www.doxygen.nl/index.html}{\texttt{ Doxygen}}
\item \href{https://www.microchip.com/en-us/tools-resources/configure/mplab-code-configurator}{\texttt{ MCC Standalone (MPLAB Code Configurator)}}
\item \href{https://www.microchip.com/wwwproducts/en/PIC32MM0064GPL020}{\texttt{ Documentation Microchip PIC32\+MM}}
\end{DoxyItemize}

\DoxyHorRuler{0}

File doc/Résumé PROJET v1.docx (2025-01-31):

RESUMÉ - Projet Maxime Colloud

SLO

2021

Titre:

DeElectronique

Contexte et objectifs :

Ce projet est un dé électronique destiné à être distribué aux visiteurs des portes ouvertes de l’ES. Le dé a pour objectif d’afficher un chiffre lorsqu’il détecte une action de secouement.

Le chiffre s’affichera pour une durée de 10sec. L’appareil utilise une pile AA pour son fonctionnement et possède une grande autonomie.

Résultats obtenus et conclusion :

Dans son état actuel, le dé ne fonctionne pas par pile à cause d’un problème d’alimentation avec la tension qui chute lors des appels de courant d’affichage. La pile parvient à être utilisée jusqu’à sa décharge complète.

Les actions de secouements sont correctement détectées et un chiffre aléatoire s’affiche.

La taille est plus petite que la taille maximale autorisée dans le cahier des charges.

Maître(s) de projet : SCA

Ecole supérieure, école des métiers Lausanne Rue de Sébeillon 12 CH-1004 Lausanne www.etml-es.ch | 1 / 1 |

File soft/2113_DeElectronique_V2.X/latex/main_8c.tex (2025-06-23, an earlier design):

\doxysection{main.\+c File Reference}
\hypertarget{main_8c}{}\label{main_8c}\index{main.c@{main.c}}
{\ttfamily \#include "{}mcc\+\_\+generated\+\_\+files/system.\+h"{}}\newline
{\ttfamily \#include "{}mcc\+\_\+generated\+\_\+files/spi1.\+h"{}}\newline
{\ttfamily \#include "{}mcc\+\_\+generated\+\_\+files/pin\+\_\+manager.\+h"{}}\newline
{\ttfamily \#include "{}Accelerometre.\+h"{}}\newline
{\ttfamily \#include "{}De\+Electronique.\+h"{}}\newline
{\ttfamily \#include "{}mcc\+\_\+generated\+\_\+files/tmr1.\+h"{}}\newline
Include dependency graph for main.\+c\+:
\nopagebreak
\begin{figure}[H]
\begin{center}
\leavevmode

\end{center}
\end{figure}
\doxysubsubsection*{Functions}
\begin{DoxyCompactItemize}
\item 
int \mbox{\hyperlink{main_8c_a840291bc02cba5474a4cb46a9b9566fe}{main}} (void)
\end{DoxyCompactItemize}

\doxysubsection{Function Documentation}
\Hypertarget{main_8c_a840291bc02cba5474a4cb46a9b9566fe}\index{main.c@{main.c}!main@{main}}
\index{main@{main}!main.c@{main.c}}
\doxysubsubsection{\texorpdfstring{main()}{main()}}
{\footnotesize\ttfamily \label{main_8c_a840291bc02cba5474a4cb46a9b9566fe} 
int main (\begin{DoxyParamCaption}\item[{void}]{}{}\end{DoxyParamCaption})}

Generated \doxylink{main_8c}{main.\+c} file from MPLAB Code Configurator

@\+Company Microchip Technology Inc.

@\+File Name \doxylink{main_8c}{main.\+c}

@\+Summary This is the generated \doxylink{main_8c}{main.\+c} using PIC24 / ds\+PIC33 / PIC32\+MM MCUs.

@\+Description This source file provides main entry point for system intialization and application code development. Generation Information \+: Product Revision \+: PIC24 / ds\+PIC33 / PIC32\+MM MCUs -\/ 1.\+75.\+1 Device \+: PIC32\+MM0064\+GPL020 The generated drivers are tested against the following\+: Compiler \+: XC16 v1.\+35 MPLAB \+: MPLAB X v5.\+05 Section\+: Included Files Here is the call graph for this function\+:
\nopagebreak
\begin{figure}[H]
\begin{center}
\leavevmode

\end{center}
\end{figure}

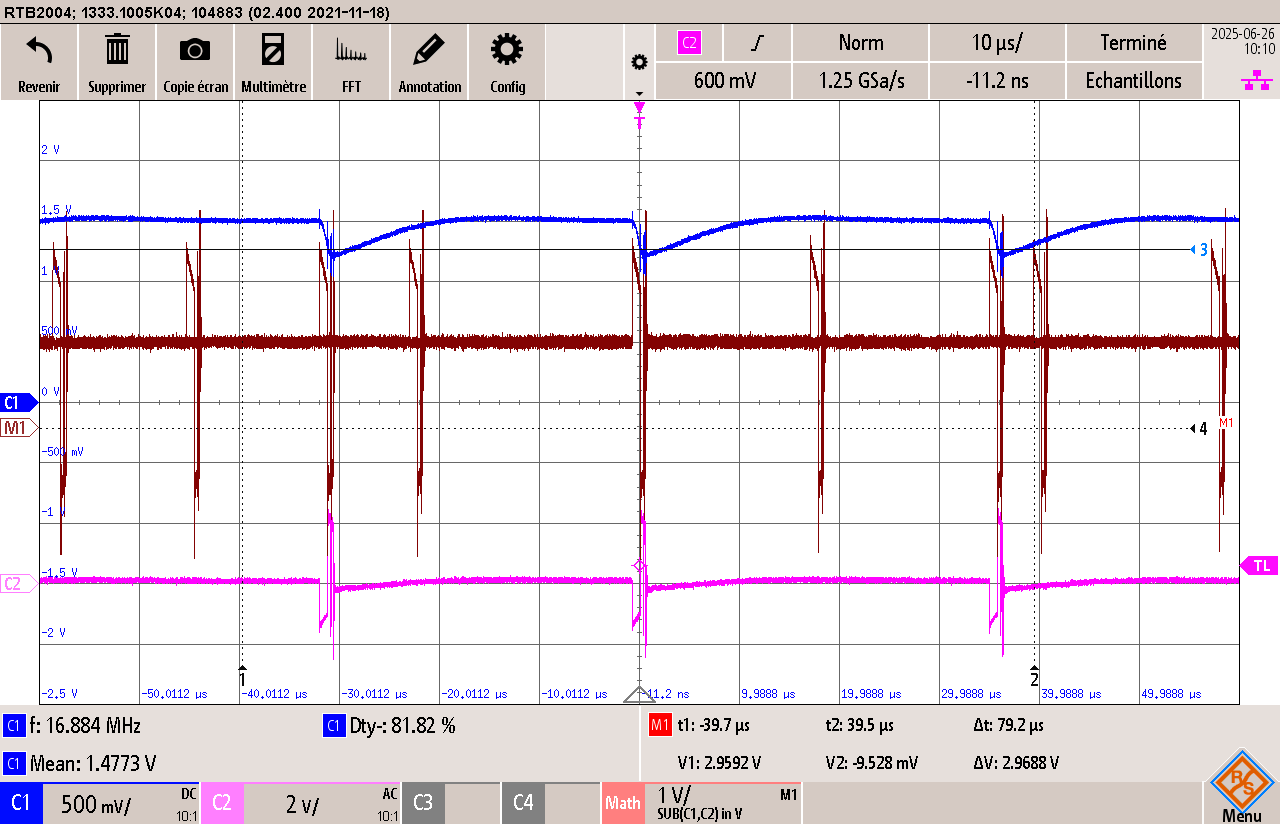
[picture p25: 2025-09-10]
doc/UL.PNG

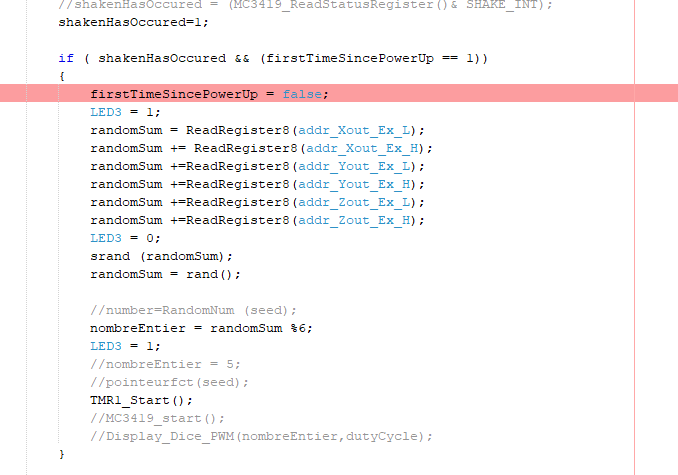
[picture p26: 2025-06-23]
doc/Pobj/Mesures/code.png

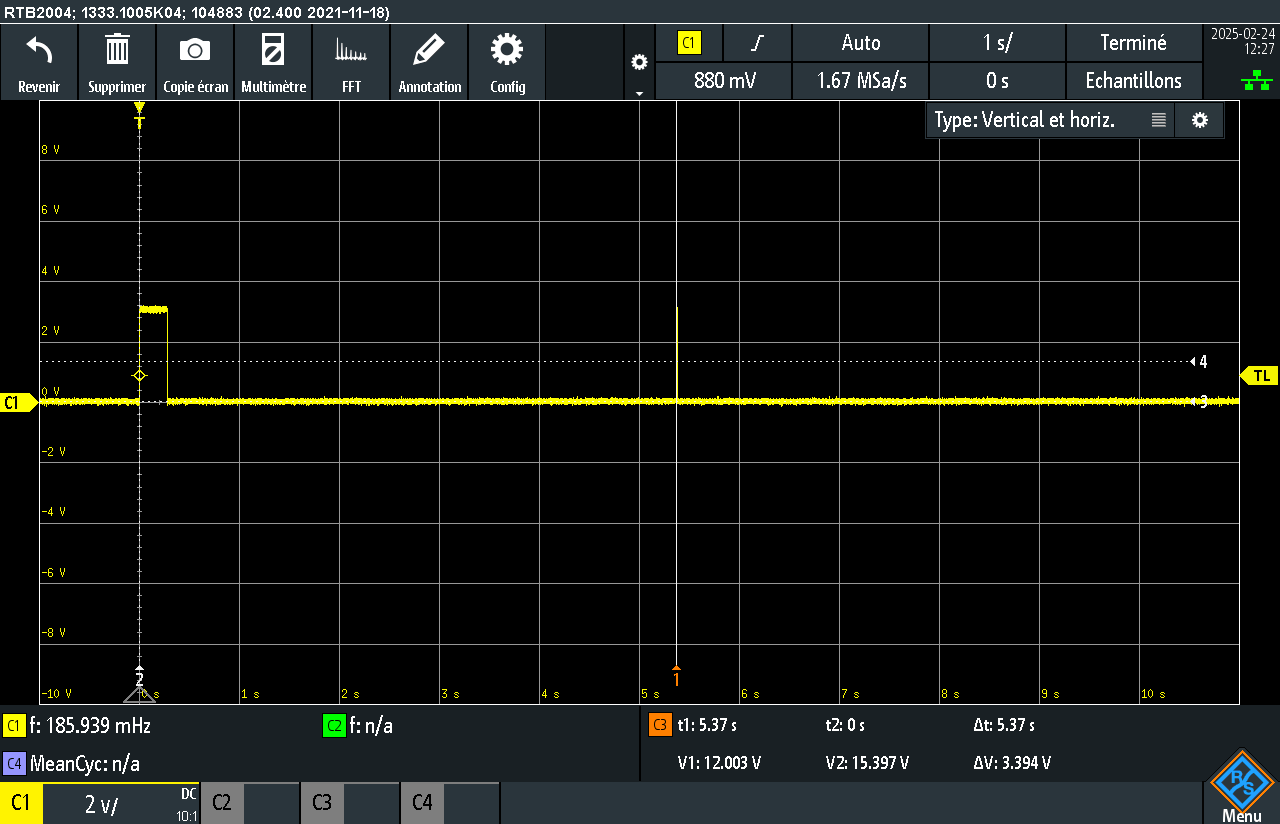
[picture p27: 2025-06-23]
doc/Pobj/Mesures/attenteinterruption.png

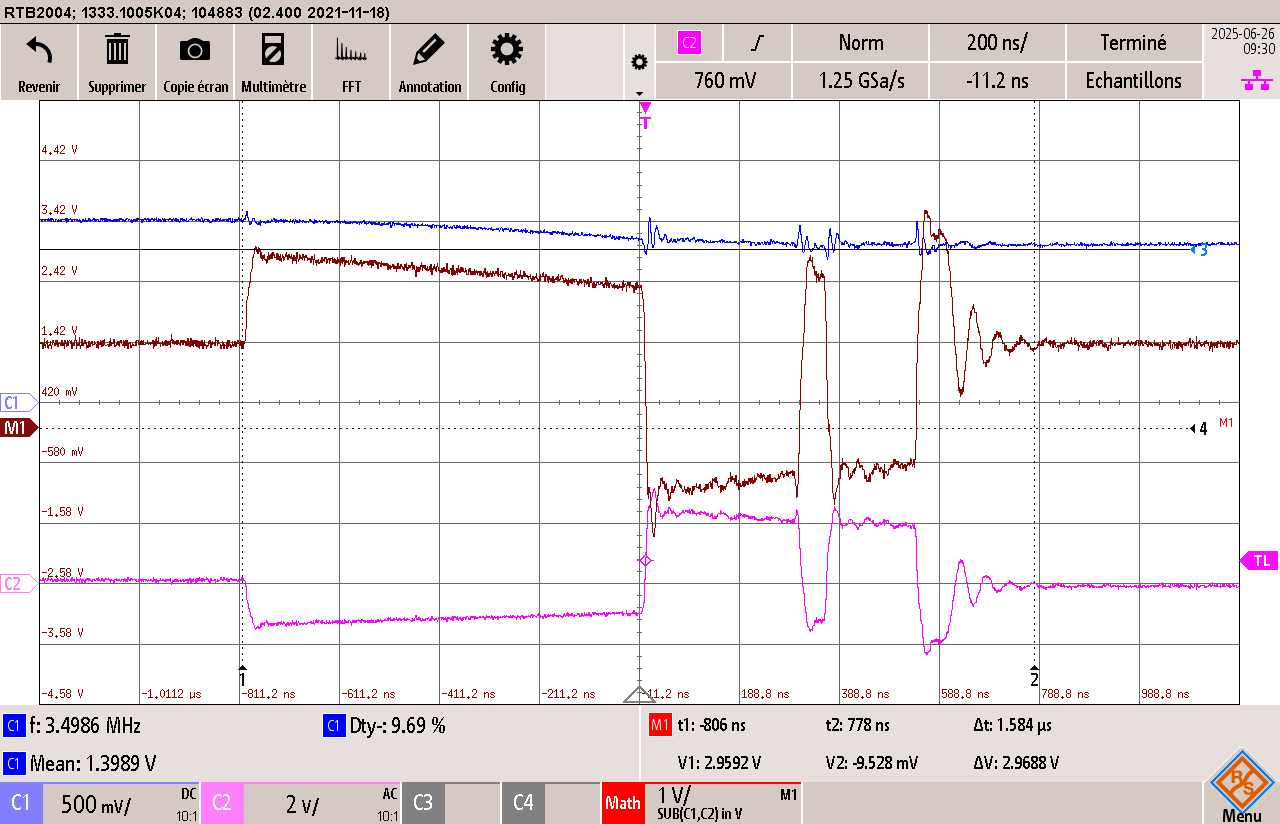
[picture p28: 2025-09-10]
doc/UL2.PNG

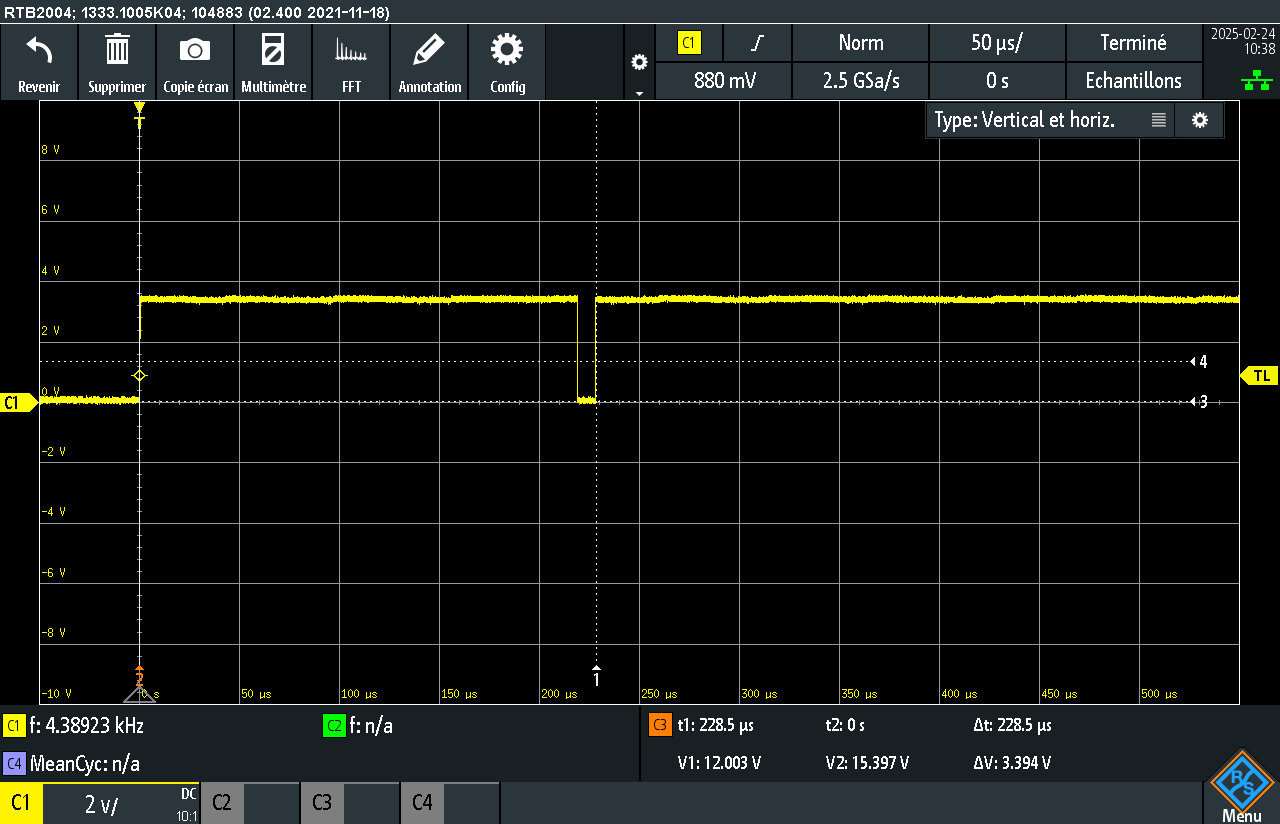
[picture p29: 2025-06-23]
doc/Pobj/Mesures/Lecture_accel_somme.png

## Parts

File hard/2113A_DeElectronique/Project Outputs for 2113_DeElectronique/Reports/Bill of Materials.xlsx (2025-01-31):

Designator | Supplier | SupplierPart | Manufacturer | ManufacturerPart | Comment | Quantity
B1 | Digi-Key | BK-53-ND | MPD (Memory Protection Devices) | BK-53 | BK-53 | 1
C1, C2, C3, C4, C5, C6 | Mouser | 187-CL21B225KPFNNNG, 80-C0805C104K5RACLR, 187-CL21A106KOCLRNC | Samsung Electro-Mechanics, KEMET | CL21B225KPFNNNG, C0805C104K5RAC7411, CL21A106KOCLRNC | 2.2uF, 100nF, 10uF | 6
D1, Q1, Q2, Q3, Q4 | Mouser | 241-BAT54_R1_00001, 771-PMV160UP215, 621-DMN2114SN-7 | Panjit, Nexperia, Diodes Incorporated | BAT54_R1_00001, PMV160UP,215, DMN2114SN-7 | BAT54_R1_00001, PMV160UP,215, DMN2114SN-7 | 5
D2 | Mouser | 625-SS13-E3 | Vishay | SS13-E3/61T | SS13-E3/61T | 1
D3, D4, D5, D6, D7, D8, D9 | Mouser | 604-APT2012LSECKJ3RV | Kingbright | APT2012LSECK/J3-PRV | LED | 7
L1 | Mouser | 81-LQH32CN561K23L | Murata Electronics | LQH32CN561K23L | 560uH | 1
P1 |  |  |  |  | Tac_Contact_Prog | 1
R1, R2, R3, R4, R5, R6, R7, R8, R9, R10, R? | Mouser, Digi-Key | 594-MCS04020D1003BE0, RMCF0805JT10K0CT-ND, RNCP0805FTD1K00CT-ND, 667-ERA-6AED561V | Vishay / Beyschlag, Stackpole Electronics Inc, Panasonic | MCS04020D1003BE000, RMCF0805JT10K0, RNCP0805FTD1K00, ERA-6AED561V | 100k, 10k, 1k, 560 | 11
S1 | Mouser | 611-PTS647SN50SMTR2L | C&K | PTS647SN50SMTR2LFS | PTS647SN50SMTR2LFS | 1
U1 | Digi-Key | 2129-R1210N331D-TR-FECT-ND | Ricoh Electronic Devices Company | R1210N331D-TR-FE | R1210N331D-TR-FE | 1
U2 | Mouser | 498-MC3419 | MEMSIC | MC3419 | MC3419 | 1
U3 | Mouser | 579-MM0064GPL020ISS | MicroChip | PIC32MM0064GPL020-I/SS | PIC32MM0064GPL020-I/SS | 1

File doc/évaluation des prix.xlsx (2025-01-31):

Liste de composant
Type de composant |  | Référence fabricant | Qty | Prix
Microcontrôleur |  | PIC32MM0064GPL020-I/SS | 1 | 1.46 CHF
Condo découplage | 100nF | C0805C104K5RAC7411 | 3 | 0.04 CHF
Cefc | 10uF | CL21A106KOCLRNC | 1 | 0.05 CHF
R1 MLR | 1k | RNCP0805FTD1K00 | 1 | 0.03 CHF
R2 MCLR | 10k | RMCF0805JT10K0 | 1 | 0.01 CHF
Accéléromètre |  | MC3419 | 1 | 0.96 CHF
MOSFET | Canal P | PMV160UP,215 | 2 | 0.18 CHF
 | Canal N | DMN2114SN-7 | 2 | 0.22 CHF
LEDs |  | APT2012LSECK/J3-PRV | 7 | 0.16 CHF
RLED 560 ohms |  | ERA-6AED561V | 7 | 0.28 CHF
Résistance 100k ohms |  | MCS04020D1003BE000 | 1 | 0.14 CHF
Support de pile |  | BK-53 | 1 | 0.53 CHF
Pile AA |  | LR03XWA/B | 1 | 0.25 CHF
Diode Shottky |  | BAT54_R1_00001 | 1 | 0.08 CHF
Convertisseur step up |  | R1210N331D-TR-FE | 1 | 0.95 CHF
Cout | 2,2uF | CL21B225KPFNNNG | 1 | 0.04 CHF
self | 560uH | LQH32CN561K23L | 1 | 0.17 CHF
Schottky spé par le fab |  | SS13-E3/61T | 1 | 0.15 CHF
Prix final |  |  |  | 8.64 CHF

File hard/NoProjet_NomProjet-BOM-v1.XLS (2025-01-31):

ETML
Refs | Nb | Désignation | Type | Valeur | Fournisseur | N° de commande | Prix u / 1 | Prix u / 10 | Prix u / 100 | Prix u / 1000 | Unité(s) d'emballage | Prix u / unité d'emballage | Prix de référence | Choix | Prix tot | Remarques
X1,X2 | 2 | Connecteur header pour câble plat DIN 41 651 sans bride de rétension | 3421-7600 | 20 pôles | Sasco Spoerle | 238221 |  |  | 2.450 | 2.150 | 100 | 2.450 | / un emb | * | 4.900 | p 3-23.002
 |  |  |  |  |  |  |  |  |  |  |  |  | -
 | 0.14 | m de câble plat 20 pôles | 3365-20 | 20 pôles | Sasco Spoerle | 270327 | 2.050 |  | 1.10 | 0.860 | 91m | 1.100 | / un emb | * | 0.154 | p3-26.029
 |  |  |  |  |  |  |  |  |  |  |  |  | -
 | 1 | montage |  |  | CIP |  |  |  |  |  |  |  | -
 |  |  |  |  | GXE |  |  | 4.000 | 3.000 |  |  |  | / 10 | * | 4.000
 |  |  |  |  |  |  |  |  |  |  |  |  | - | * | 0
 |  |  |  |  |  |  |  |  |  |  |  |  | -
 |  |  |  |  |  |  |  |  |  |  |  |  | - | * | 0
 |  |  |  |  |  |  |  |  |  |  |  |  | -
 |  |  |  |  |  |  |  |  |  |  |  |  | - | * | 0
 |  |  |  |  |  |  |  |  |  |  |  |  | -
 |  |  |  |  |  |  |  |  |  |  |  |  | - | * | 0
 |  |  |  |  |  |  |  |  |  |  |  |  | -
 |  |  |  |  |  |  |  |  |  |  |  |  | - | * | 0
 |  |  |  |  |  |  |  |  |  |  |  |  | -
 |  |  |  |  |  |  |  |  |  |  |  |  | - | * | 0
 |  |  |  |  |  |  |  |  |  |  |  |  | -
 |  |  |  |  |  |  |  |  |  |  |  |  | - | * | 0
 |  |  |  |  |  |  |  |  |  |  |  |  | -
 |  |  |  |  |  |  |  |  |  |  |  |  | - | * | 0
 |  |  |  |  |  |  |  |  |  |  |  |  | -
 |  |  |  |  |  |  |  |  |  |  |  |  | - | * | 0
 |  |  |  |  |  |  |  |  |  |  |  |  | -
 |  |  |  |  |  |  |  |  |  |  |  |  | - | * | 0
 |  |  |  |  |  |  |  |  |  |  |  |  | -
 |  |  |  |  |  |  |  |  |  |  |  |  | - | * | 0
 |  |  |  |  |  |  |  |  |  |  |  |  | -
 |  |  |  |  |  |  |  |  |  |  |  |  | - | * | 0
 |  |  |  |  |  |  |  |  |  |  |  |  | -
 |  |  |  |  |  |  |  |  |  |  |  |  | - | * | 0
 |  |  |  |  |  |  |  |  |  |  |  |  | -
 |  |  |  |  |  |  |  |  |  |  |  |  | - | * | 0
 |  |  |  |  |  |  |  |  |  |  |  |  | -
 |  |  |  |  |  |  |  |  |  |  |  |  | - | * | 0
 |  |  |  |  |  |  |  |  |  |  |  |  | -
 |  |  |  |  |  |  |  |  |  |  |  |  | - | * | 0
 |  |  |  |  |  |  |  |  |  |  |  |  | -
 |  |  |  |  |  |  |  |  |  |  |  |  | - | * | 0
 |  |  |  |  |  |  |  |  |  |  |  |  | -
 |  |  |  |  |  |  |  |  |  |  |  |  |  | Total: | 9.05

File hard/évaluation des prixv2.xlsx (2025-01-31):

Liste de composant original avec les composant initiaux |  |  |  |  |  |  | Liste de composant original les prix actuels |  |  |  |  |  |  |  | Liste de composant avec solution Sousa |  |  |  |  |  |  |  |  |  | Liste de composant avec solution Moreno
 |  | Version 1 |  |  |  |  |  |  | Version 1 |  |  |  |  |  |  | Version 2 |  |  |  |  |  |  |  |  |  | Version 2
Type de composant |  | Référence fabricant | Qty | Prix ancien | Prix total | Prix pour 100 | Type de composant |  | Référence fabricant | Qty | Prix actuel | Prix total | Prix pour 100 | Type de composant |  | Référence fabricant | lien | Qty | prix unité | prix total unité | Qty pour 100 | prix pour 100 | prix total (100) | Type de composant |  | Référence fabricant | lien | Qty | prix unité | prix total unité | Qty pour 100 | prix pour 100 | prix total (100)
Microcontrôleur |  | PIC32MM0064GPL020-I/SS | 1 | 1.46 CHF | 1.46 CHF | 146.00 CHF | Microcontrôleur |  | PIC32MM0064GPL020-I/SS | 1 | 1.55 CHF | 1.55 CHF | 155.00 CHF | Microcontrôleur |  | PIC32MM0064GPL020-I/SS | PIC32MM0064GPL020-I/SS - Microchip | Farnell CH (https://ch.farnell.com/microchip/pic32mm0064gpl020-i-ss/mcu-32bit-pic32-25mhz-ssop-20/dp/2610360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) | 1 | 1.55 CHF | 1.55 CHF | 100 | 1.34 CHF | 134.00 CHF | Microcontrôleur |  | PIC32MM0064GPL020-I/SS | PIC32MM0064GPL020-I/SS - Microchip | Farnell CH (https://ch.farnell.com/microchip/pic32mm0064gpl020-i-ss/mcu-32bit-pic32-25mhz-ssop-20/dp/2610360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) | 1 | 1.55 CHF | 1.55 CHF | 100 | 1.34 CHF | 134.00 CHF
Condo découplage | 100nF | C0805C104K5RAC7411 | 3 | 0.04 CHF | 0.12 CHF | 12.30 CHF | Condo découplage | 100nF | C0805C104K5RAC7411 | 3 | 0.04 CHF | 0.12 CHF | 12.00 CHF | Condo découplage | 100nF | C0805C104K5RAC7411 | C0805C104K5RAC7411 KEMET | Mouser Schweiz (https://www.mouser.ch/ProductDetail/KEMET/C0805C104K5RAC7411?qs=jbRM9o5BbzPcVXF0wW9AYg%3D%3D) | 3 | 0.04 CHF | 0.12 CHF | 300 | 0.04 CHF | 12.30 CHF | Condo découplage | 100nF | C0805C104K5RAC7411 | C0805C104K5RAC7411 KEMET | Mouser Schweiz (https://www.mouser.ch/ProductDetail/KEMET/C0805C104K5RAC7411?qs=jbRM9o5BbzPcVXF0wW9AYg%3D%3D) | 3 | 0.04 CHF | 0.12 CHF | 300 | 0.04 CHF | 12.30 CHF
Cefc | 10uF | CL21A106KOCLRNC | 1 | 0.05 CHF | 0.05 CHF | 4.80 CHF | Cefc | 10uF | CL21A106KOCLRNC | 1 | 0.05 CHF | 0.05 CHF | 4.80 CHF | Cefc | 10uF | CL21A106KOCLRNC |  | 5 | 0.05 CHF | 0.24 CHF | 300 | 0.05 CHF | 14.40 CHF | Cefc | 10uF | CL21A106KOCLRNC |  | 3 | 0.05 CHF | 0.14 CHF | 300 | 0.05 CHF | 14.40 CHF
R1 MLR | 1k | RNCP0805FTD1K00 | 3 | 0.03 CHF | 0.08 CHF | 8.28 CHF | R1 MLR | 1k | RNCP0805FTD1K00 | 3 | 0.03 CHF | 0.08 CHF | 8.28 CHF | R1 MLR | 1k | RNCP0805FTD1K00 |  | 3 | 0.03 CHF | 0.08 CHF | 300 | 0.03 CHF | 8.28 CHF | R1 MLR | 1k | RNCP0805FTD1K00 |  | 3 | 0.03 CHF | 0.08 CHF | 300 | 0.03 CHF | 8.28 CHF
R2 MCLR | 10k | RMCF0805JT10K0 | 1 | 0.01 CHF | 0.01 CHF | 0.75 CHF | R2 MCLR | 10k | RMCF0805JT10K0 | 1 | 0.01 CHF | 0.01 CHF | 0.75 CHF | R2 MCLR | 10k | RMCF0805JT10K0 |  | 1 | 0.01 CHF | 0.01 CHF | 100 | 0.01 CHF | 0.75 CHF | R2 MCLR | 10k | RMCF0805JT10K0 |  | 1 | 0.01 CHF | 0.01 CHF | 100 | 0.01 CHF | 0.75 CHF
 |  |  |  |  | 0.00 CHF | 0.00 CHF |  |  |  |  |  | 0.00 CHF | 0.00 CHF
Accéléromètre |  | MC3419 | 1 | 0.96 CHF | 0.96 CHF | 96.00 CHF | Accéléromètre |  | MC3419 | 1 | 1.86 CHF | 1.86 CHF | 186.00 CHF | Accéléromètre |  | MC3419 | MC3419 Memsic Inc. | Sensors, Transducers | DigiKey (https://www.digikey.ch/en/products/detail/MC3419/3502-MC3419CT-ND/15292813?curr=usd) | 1 | 1.86 CHF | 1.86 CHF | 100 | 0.99 CHF | 99.00 CHF | Accéléromètre |  | MC3419 | MC3419 Memsic Inc. | Sensors, Transducers | DigiKey (https://www.digikey.ch/en/products/detail/MC3419/3502-MC3419CT-ND/15292813?curr=usd) | 1 | 1.86 CHF | 1.86 CHF | 100 | 0.99 CHF | 99.00 CHF
 |  |  |  |  | 0.00 CHF | 0.00 CHF |  |  |  |  |  | 0.00 CHF | 0.00 CHF
MOSFET | Canal P | PMV160UP,215 | 2 | 0.18 CHF | 0.36 CHF | 36.20 CHF | MOSFET | Canal P | PMV160UP,215 | 2 | 0.18 CHF | 0.36 CHF | 36.20 CHF | MOSFET | Canal P | PMV160UP,215 |  | 2 | 0.18 CHF | 0.36 CHF | 200 | 0.18 CHF | 36.20 CHF | MOSFET | Canal P | PMV160UP,215 |  | 2 | 0.18 CHF | 0.36 CHF | 200 | 0.18 CHF | 36.20 CHF
 | Canal N | DMN2114SN-7 | 2 | 0.22 CHF | 0.43 CHF | 43.40 CHF |  | Canal N | DMN2114SN-7 | 2 | 0.22 CHF | 0.43 CHF | 43.40 CHF |  | Canal N | DMN2114SN-7 |  | 2 | 0.22 CHF | 0.43 CHF | 200 | 0.22 CHF | 43.40 CHF |  | Canal N | DMN2114SN-7 |  | 2 | 0.22 CHF | 0.43 CHF | 200 | 0.22 CHF | 43.40 CHF
 |  |  |  |  | 0.00 CHF | 0.00 CHF |  |  |  |  |  | 0.00 CHF | 0.00 CHF
LEDs |  | APT2012LSECK/J3-PRV | 7 | 0.16 CHF | 1.13 CHF | 112.70 CHF | LEDs |  | APT2012LSECK/J3-PRV | 7 | 0.65 CHF | 4.55 CHF | 455.00 CHF | LEDs |  | APT2012LSECK/J3-PRV | APT2012LSECK/J3-PRV Kingbright | Optoelectronics | DigiKey (https://www.digikey.ch/en/products/detail/APT2012LSECK-J3-PRV/754-1935-1-ND/5177465?curr=chf) | 7 | 0.65 CHF | 4.55 CHF | 1000 | 0.18 CHF | 180.00 CHF | LEDs |  | APT2012LSECK/J3-PRV | APT2012LSECK/J3-PRV Kingbright | Optoelectronics | DigiKey (https://www.digikey.ch/en/products/detail/APT2012LSECK-J3-PRV/754-1935-1-ND/5177465?curr=chf) | 7 | 0.65 CHF | 4.55 CHF | 1000 | 0.18 CHF | 180.00 CHF
RLED 560 ohms |  | ERA-6AED561V | 7 | 0.28 CHF | 1.96 CHF | 196.00 CHF | RLED 560 ohms |  | ERA-6AED561V | 7 | 0.40 CHF | 2.80 CHF | 280.00 CHF | RLED 560 ohms |  | ERA-6AED561V | ERA-6AED561V Panasonic | Mouser Suisse (https://www.mouser.ch/ProductDetail/Panasonic/ERA-6AED561V?qs=MNPzkKEzRtSreMWvSlWHLQ%3D%3D) | 7 | 0.40 CHF | 2.80 CHF | 1000 | 0.58 CHF | 580.00 CHF | RLED 560 ohms |  | ERA-6AED561V | ERA-6AED561V Panasonic | Mouser Suisse (https://www.mouser.ch/ProductDetail/Panasonic/ERA-6AED561V?qs=MNPzkKEzRtSreMWvSlWHLQ%3D%3D) | 7 | 0.40 CHF | 2.80 CHF | 1000 | 0.58 CHF | 580.00 CHF
Résistance 100k ohms |  | MCS04020D1003BE000 | 1 | 0.14 CHF | 0.14 CHF | 14.40 CHF | Résistance 100k ohms |  | MCS04020D1003BE000 | 1 | 0.14 CHF | 0.14 CHF | 14.40 CHF | Résistance 100k ohms |  | MCS04020D1003BE000 |  | 1 | 0.14 CHF | 0.14 CHF | 100 | 0.14 CHF | 14.40 CHF | Résistance 100k ohms |  | MCS04020D1003BE000 |  | 1 | 0.14 CHF | 0.14 CHF | 100 | 0.14 CHF | 14.40 CHF
 |  |  |  |  | 0.00 CHF | 0.00 CHF |  |  |  |  |  | 0.00 CHF | 0.00 CHF
Support de pile |  | BK-53 | 1 | 0.53 CHF | 0.53 CHF | 53.00 CHF | Support de pile |  | BK-53 | 1 | 0.53 CHF | 0.53 CHF | 53.00 CHF | Support de pile |  | BK-53 |  | 1 | 0.53 CHF | 0.53 CHF | 100 | 0.53 CHF | 53.00 CHF | Support de pile |  | BK-53 |  | 1 | 0.53 CHF | 0.53 CHF | 100 | 0.53 CHF | 53.00 CHF
Pile AA |  | LR03XWA/B | 1 | 0.25 CHF | 0.25 CHF | 25.00 CHF | Pile AA |  | LR03XWA/B | 1 | 0.25 CHF | 0.25 CHF | 25.00 CHF | Pile AA |  | LR03XWA/B |  | 1 | 0.25 CHF | 0.25 CHF | 100 | 0.25 CHF | 25.00 CHF | Pile AA |  | LR03XWA/B |  | 1 | 0.25 CHF | 0.25 CHF | 100 | 0.25 CHF | 25.00 CHF
 |  |  |  |  | 0.00 CHF | 0.00 CHF |  |  |  |  |  | 0.00 CHF | 0.00 CHF
Diode Shottky |  | BAT54_R1_00001 | 1 | 0.08 CHF | 0.08 CHF | 8.00 CHF | Diode Shottky |  | BAT54_R1_00001 | 1 | 0.16 CHF | 0.16 CHF | 16.00 CHF | Diode Shottky |  | BAT54_R1_00001 | BAT54_R1_00001 Panjit International Inc. | Discrete Semiconductor Products | DigiKey (https://www.digikey.ch/en/products/detail/BAT54_R1_00001/3757-BAT54_R1_00001CT-ND/14661364?curr=chf) | 1 | 0.16 CHF | 0.16 CHF | 100 | 0.08 CHF | 8.00 CHF | Diode Shottky |  | BAT54_R1_00001 | BAT54_R1_00001 Panjit International Inc. | Discrete Semiconductor Products | DigiKey (https://www.digikey.ch/en/products/detail/BAT54_R1_00001/3757-BAT54_R1_00001CT-ND/14661364?curr=chf) | 1 | 0.16 CHF | 0.16 CHF | 100 | 0.08 CHF | 8.00 CHF
 |  |  |  |  | 0.00 CHF | 0.00 CHF |  |  |  |  |  | 0.00 CHF | 0.00 CHF
Convertisseur step up |  | R1210N331D-TR-FE | 1 | 0.95 CHF | 0.95 CHF | 95.23 CHF | Convertisseur step up |  | R1210N331D-TR-FE | 1 | 0.95 CHF | 0.95 CHF | 95.23 CHF | Convertisseur step up |  | TPS6107 | https://octopart.com/search?q=TPS6107&currency=CHF&specs=0 | 1 | 1.29 CHF | 1.29 CHF | 100 | 1.29 CHF | 129.00 CHF | Convertisseur step up |  | XCL102D303CR-G | XCL102D303CR-G Torex Semiconductor Ltd | Alimentations - Montage sur carte | DigiKey (https://www.digikey.ch/fr/products/detail/torex-semiconductor-ltd/XCL102D303CR-G/7361180) | 1 | 2.70 CHF | 2.70 CHF | 100 | 1.95 CHF | 195.00 CHF
Cout | 2,2uF | CL21B225KPFNNNG | 1 | 0.04 CHF | 0.04 CHF | 3.90 CHF | Cout | 2,2uF | CL21B225KPFNNNG | 1 | 0.04 CHF | 0.04 CHF | 3.90 CHF | bobine | 4,7µH | 744766904 | 744766904 Würth Elektronik | Inductances, bobines, bobines d'arrêt | DigiKey (https://www.digikey.ch/fr/products/detail/w%C3%BCrth-elektronik/744766904/5353118) | 1 | 0.40 CHF | 0.40 CHF | 100 | 0.30 CHF | 30.00 CHF
self | 560uH | LQH32CN561K23L | 1 | 0.17 CHF | 0.17 CHF | 16.70 CHF | self | 560uH | LQH32CN561K23L | 1 | 0.17 CHF | 0.17 CHF | 16.70 CHF | Résistance | 180kΩ |  |  | 1 | 0.03 CHF | 0.03 CHF | 100
Schottky spé par le fab |  | SS13-E3/61T | 1 | 0.15 CHF | 0.15 CHF | 14.60 CHF | Schottky spé par le fab |  | SS13-E3/61T | 1 | 0.15 CHF | 0.15 CHF | 14.60 CHF | Résistance | 1MΩ |  |  | 1 | 0.03 CHF | 0.03 CHF | 100
 |  |  |  |  |  |  |  |  |  |  |  |  |  | PCB |  | Eurocircuit |  |  |  | 43.50 CHF | 100 | 2.95 CHF | 295.00 CHF | PCB |  | Eurocircuit |  |  |  | 43.50 CHF | 100 | 2.95 CHF | 295.00 CHF
Remarque: le convertisseur step up n'est plus disponible |  |  |  |  | pour 1 | pour 100 | Remarque: le convertisseur step up n'est plus disponible |  |  |  |  | pour 1 | pour 100
Prix final |  |  |  |  | 8.87 CHF | 887.26 CHF | Prix final |  |  |  |  | 14.20 CHF | 1420.26 CHF |  |  |  |  |  |  | 58.34 CHF |  | pour 100 | 1662.73 CHF |  |  |  |  |  |  | 59.19 CHF |  | pour 100 | 1698.73 CHF
 |  |  |  |  |  |  |  |  |  |  |  |  |  |  |  |  |  |  |  |  |  | pour 1 | 16.63 CHF |  |  |  |  |  |  |  |  | pour 1 | 16.99 CHF

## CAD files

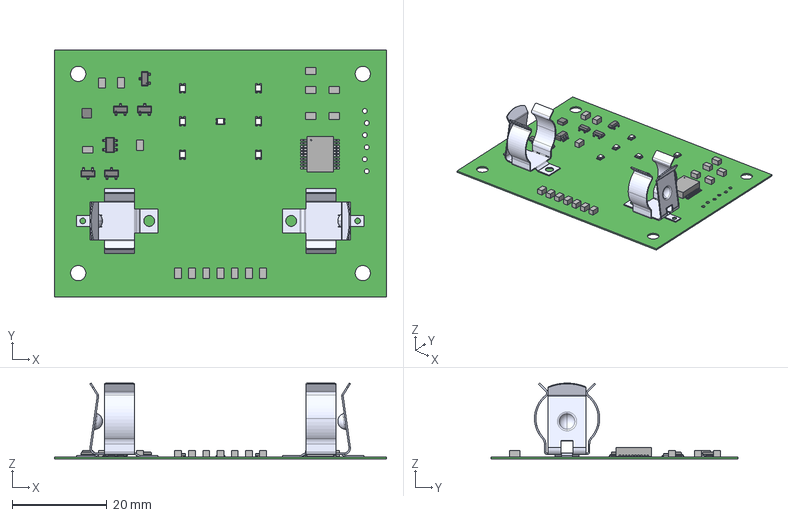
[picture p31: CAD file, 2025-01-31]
hard/2113A_DeElectronique/Project Outputs for 2113_DeElectronique/Export/2113_DeElectronique.step
70.0 x 52.0 x 16.0 mm
SOT-23-5_MC_MCH
VLGA-12_MEM
SSOP20_SS_MCH
Extruded x 16
PMV160UP_NEX x 5
base x 7
cover x 7
housing x 7
marking x 14
base_2 x 7
BK-53--3DModel-STEP-56544 x 2

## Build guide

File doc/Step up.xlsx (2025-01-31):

Iout max | Vo | V pile | FS | D | r | dVout | VoutESR
 |  |  |  |  |  |  |  | diL |  |  |  | Cout min
0.02 | 3.3 | 1 | 180000 | 0.696969697 | 0.2 | 0.1 | 0.2 |  | Vpile |  |  |  | Vpile
 |  | 1.5 |  | 0.5454545455 | 0.3 | 0.2 | 0.1 | r | 1 | 1.5 |  | dVout | 1 | 1.5
 |  |  |  |  | 0.4 | 0.3 | 0 | 0.2 | 0.0132 | 0.0088 |  | 0.1 | 7.744107744e-07 | 6.060606061e-07 | 2,2uF
 |  |  |  |  |  |  |  | 0.3 | 0.0198 | 0.0132 |  | 0.2 | 3.872053872e-07 | 3.03030303e-07
 |  |  |  |  |  |  |  | 0.4 | 0.0264 | 0.0176 |  | 0.3 | 2.581369248e-07 | 2.02020202e-07
 |  |  |  |  |  |  |  | L |  |  |  | ESR
 |  |  |  |  |  |  |  |  | Vpile |  |  |  | VouESR
 |  |  |  |  |  |  |  | diL | 1 | 1.5 |  |  | 0.2 |  | 0.1
 |  |  |  |  |  |  |  | 0.0132 | 0.0002933374145 | 0.0003443526171 |  |  | D |  | D
 |  |  |  |  |  |  |  | 0.0198 | 0.0001955582764 | 0.0002295684114 |  | diL/2 | 0.696969697 | 0.5454545455 | 0.696969697 | 0.5454545455
 |  |  |  |  |  |  |  | 0.0264 | 0.0001466687073 | 0.0001721763085 |  | 0.0066 | 2.754820937 | 3.95256917 | 1.377410468 | 1.976284585
 |  |  |  |  |  |  |  | 0.0088 | 0.0004400061218 | 0.0005165289256 | 500uH | 0.0099 | 2.635046113 | 3.710575139 | 1.317523057 | 1.85528757
 |  |  |  |  |  |  |  | 0.0132 | 0.0002933374145 | 0.0003443526171 |  | 0.0132 | 2.525252525 | 3.496503497 | 1.262626263 | 1.748251748 | > 1,2
 |  |  |  |  |  |  |  | 0.0176 | 0.0002200030609 | 0.0002582644628 |  | 0.0044 | 2.840909091 | 4.132231405 | 1.420454545 | 2.066115702
 |  |  |  |  |  |  |  |  |  |  |  | 0.0066 | 2.754820937 | 3.95256917 | 1.377410468 | 1.976284585
 |  |  |  |  |  |  |  |  |  |  |  | 0.0088 | 2.673796791 | 3.787878788 | 1.336898396 | 1.893939394

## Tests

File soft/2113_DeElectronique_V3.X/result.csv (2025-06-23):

tirage | value
1 | 6 | 1 | 26
2 | 4 | 2 | 23
3 | 5 | 3 | 16
4 | 5 | 4 | 18
5 | 6 | 5 | 25
6 | 6 | 6 | 22
7 | 2
8 | 1
9 | 3
10 | 4
11 | 4
12 | 2
13 | 1
14 | 3
15 | 3
16 | 1
17 | 6
18 | 6
19 | 1
20 | 5
21 | 1
22 | 3
23 | 5
24 | 5
25 | 1
26 | 1
27 | 1
28 | 1
29 | 5
30 | 1
31 | 2
32 | 1
33 | 4
34 | 4
35 | 3
36 | 5
37 | 2
38 | 6
39 | 3
40 | 5
41 | 1
42 | 6
43 | 4
44 | 5
45 | 3
46 | 1
47 | 2
48 | 6
49 | 2
50 | 3
51 | 1
52 | 3
53 | 2
54 | 4
55 | 6
56 | 4
57 | 5
58 | 5
59 | 4
60 | 5
61 | 5
62 | 4
63 | 5
64 | 3
65 | 3
66 | 6
67 | 3
68 | 1
69 | 6
70 | 2
71 | 4
72 | 6
73 | 2
74 | 2
75 | 1
76 | 4
77 | 1
78 | 2
79 | 6
80 | 2
81 | 5
82 | 3
83 | 4
84 | 5
85 | 1
86 | 2
87 | 3
88 | 1
89 | 2
90 | 5
91 | 2
92 | 1
93 | 6
94 | 5
95 | 2
96 | 4
97 | 5
98 | 2
99 | 6
100 | 2
101 | 5
102 | 4
103 | 1
104 | 1
105 | 6
106 | 6
107 | 4
108 | 4
109 | 6
110 | 6
111 | 6
112 | 3
113 | 2
114 | 1
115 | 5
116 | 6
117 | 1
118 | 4
119 | 5
120 | 2
121 | 2
122 | 1
123 | 2
124 | 3
125 | 5
126 | 5
127 | 2
128 | 6
129 | 1
130 | 5
131
132
133
134

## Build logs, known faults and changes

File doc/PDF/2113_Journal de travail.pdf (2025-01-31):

Dates | Avancement | de | à | total d'heures | total h/j | Note
04.10.2021 | Reception du dossier et discussion | 10:00 | 11:20 | 01:20 | 5:00
| Récupération des documents PDF et création des fichiers du projet | 11:20 | 11:35 | 00:15
| élaboration planning | 13:10 | 15:00 | 01:50
| Schéma bloc | 15:00 | 15:10 | 00:10
| Réflexion d'économie d'énergie LED | 15:10 | 15:30 | 00:20 | | Recherche d'une mise en série de 2 LED qui sont tjr allumées ensemble, contrôle alimentation de sortie micro et tension de fonctionnement des LEDs, (pas assez de tension de sortie Mu)
| Recherche | 15:30 | 16:20 | 00:50 | | Recherche d'un accéléromètre
| Documentation | 16:20 | 16:35 | 00:15 | | Journal de travail
05.10.2021 | Recherche d'accéléromètre disponible | 08:35 | 09:10 | 00:35 | 6:25 | Recherche d'accéléromètre disponible à la commande (bonne disponibilité chez mouser uniquement)
| Recherche d'accéléromètre compatible | 09:10 | 09:45 | 00:35 | | Recherche dans les datasheet d'un accéléromètre qui soit utilisable (faible consommation en standbye, peu cher, 3 axes, configurable pour un réveil selon des accélération en 3 axes)
| Recherche microcontrôleur | 10:10 | 10:50 | 00:40 | | Recherche d'un microcontroleur utilisable et peu cher
| Recherche d'un interrupteur | 10:50 | 11:10 | 00:20 | | Recherche d'un éventuel interrupteur à ajouter peu cher
| Recherche de composants | 11:10 | 12:00 | 00:50
| Recherche de composants | 13:10 | 16:35 | 03:25 | | Recherche des composants généraux et recherche d'un régulateur ou élévateur de tension de préférence montable à la main
06.10.2021 | Recherche de composants symbole / footprint | 08:30 | 11:35 | 03:05 | 6:40 | Recherche de composants et comparaison de prix pour choix du moins cher. Récupération et création des footprint et symbole. Comparaison entre régulateur et élévateur
| " | 13:10 | 16:45 | 03:35 | | "
07.10.2021 | Choix accéléromètre | 08:30 | 10:00 | 01:30 | 6:10 | Recherche d'un accéléromètre de chez ST car une bonne documentation en support est founit par ce fabricant. Problème plus aucun accéléromètre dispo sauf 1 à 2 francs. Choix du MC3419
| Comparaison et choix du microcontrôleur | 10:20 | 11:40 | 01:20 | | Choix du microcontrôleur qui sera utilisé entre les différents micro de la sélection initiale
| Réunion avec le mâitre de diplôme | 13:00 | 14:30 | 01:30 | | Discussion d'un montage de protection de tension inverse Choix de variante de montage, le step-up présélectionné n'est pas fait pour de la basse consommation, recherche de convertisseur, contrôle de l'utilisation possible et des courant de fonctionnement de l'accéléromètre. Choix de LED low power pour un minimum de consommation
| Remplissage PC + doc | 14:30 | 15:00 | 00:30
| Recherche de composants | 15:15 | 16:35 | 01:20 | | Recherche de composants selon discussion
08.10.2021 | Recherche composants | 08:30 | 11:50 | 03:20 | 6:45 | Recherche d'un MOSFET 0,7V max de VGSth pour entrer en conduction avec la perte de la diode shottky avec un peu plus d'1V d'alimentation de pile. Choix convertisseur boost et recherche des composants généraux
| Recherche composants | 13:10 | 16:35 | 03:25 | | Recherche d'un convertisseur avec peu de consommation de courant, ses composants et les composants généraux
11.10.2021 | Schéma | 08:30 | 11:50 | 03:20 | 6:45 | Schéma électrique (Création des symbole / footprint) et schéma
| Schéma | 13:10 | 16:35 | 03:25 | | Schéma électrique (Création des symbole / footprint) et schéma, Recherche de composants pour changer les composants plus dispo
12.10.2021 | Schéma bloc | 08:30 | 11:45 | 03:15 | 6:30 | Faire le schéma
| Vérification de schéma | 13:10 | 13:40 | 00:30
| Design PCB | 14:00 | 16:45 | 02:45 | | Design du PCB
13.10.2021 | Design PCB | 08:45 | 11:40 | 02:55 | 6:00 | Design PCB
| Vérification PCB | 13:10 | 14:15 | 01:05 | | Vérification PCB par un collègue
| Mise des template | 14:15 | 15:30 | 01:15 | | Template ES non présent, ajout des templates ES et création des fichiers avec template (PCB refait le copié collé ne marche pas)
| Rapport | 15:50 | 16:35 | 00:45
14.10.2021 | Rapport | 08:45 | 10:00 | 01:15 | 6:35
| Réunion avec le maitre de diplôme | 10:00 | 11:55 | 01:55
| Redimensionnement self et condo | 13:10 | 16:35 | 03:25 | | Recherche des calcul de dimensionnement, calcul self, condo de sortie
15.10.2021 | Recherhce des composants à changer + schéma | 08:30 | 12:00 | 03:30 | 5:35 | Recherche bouton, condo, self, calculs de comparaison des valeurs critiques et modification schéma
| Modification PCB | 13:10 | 14:00 | 00:50
| Passage expert | 14:00 | 15:15 | 01:15 | | Présentation du projet et discussion de fonctionnalités, techniques et éventuelles améliorations
| Modifications PCB | 15:15 | 16:35
18.10.2021 | Recherche exemples microchip pour le pic MM | 08:45 | 10:15 | 01:30 | 6:20 | Rien trouvé chez microchip
| Commande de composants | 10:15 | 10:30 | 00:15
| Test kit MM | 10:30 | 11:40 | 01:10
| Prise en main du Code configurator | 13:10 | 16:35 | 03:25

19.10.2021 | Modification de commande | 08:30 | 09:10 | 00:40 | 6:30 | Retrait des composants présents en stock
| Recherche des registres utiles accéléromètre | 09:10 | 11:35 | 02:25
| Rapport | 13:10 | 16:35 | 03:25
20.10.2021 | Création des fichiers accéléromètre / création des define utiles | 08:45 | 11:35 | 02:50 | 6:15 | Recherche dans le datasheet des registres, adresse, fonctionnement SPI
| Rapport | 13:10 | 16:35 | 03:25
21.10.2021 | config accéléromètre | 08:45 | 11:50 | 03:05 | 6:20 | Recherche des registres utiles, création des define
| Contrôle commande | 13:20 | 13:40 | 00:20 | | Contrôle des composants reçus
| Réunion avec le mâitre de diplôme | 13:40 | 15:00 | 01:20
| Création des fonctions accéléromètre | 15:00 | 16:35 | 01:35
22.10.2021 | Configuration chip | 08:45 | 12:00 | 03:15 | 6:20 | Configuration chip. Le main a une erreur à la génération et ne se fonctionne pas (l'erreur n'est pas connu pour le moment). Aucun message d'erreur n'apparait
| Brasage PCB diego | 13:10 | 14:00 | 00:50 | | Aide au brasage du PCB de M.Correia
| Configuration chip | 14:00 | 15:40 | 01:40 | | Erreur toujours non réglée
| Rapport | 16:00 | 16:35 | 00:35
25.10.2021 | aider diego à son montage PCB | 08:45 | 10:00 | 01:15 | 6:25
| Montage accéléromètre | 10:00 | 12:30 | 02:30 | | Problème au passage au four, la pâte à brasé a durci mais pas fondu. Deuxième passage ok (modification température à atteindre et temps pour pour atteindre la consigne)
| Montage micro | 13:30 | 14:15 | 00:45 | | Montage microcontrôleur et nettoyage carte
| Montage des composant nécessaire au fonctionnement micro + accéléromètre | 14:15 | 14:40 | 00:25
| Test fonctionnalité MPLABX | 14:40 | 14:55 | 00:15 | | Test si le problème du vendredi est toujours présent (toujours présent pour tout les fichiers)
| Configuration programme de test micro | 15:20 | 16:15 | 00:55
| Rapport | 16:15 | 16:35 | 00:20
26.10.2021 | Test micro | 08:45 | 09:35 | 00:50 | 6:25 | Refaire un câble adapté pour la connexion de programmation de la carte + programme de test et test du micro (test court-ciruit d'alimentation effectué avant)
| Test Timer et montage LED | 09:50 | 10:30 | 00:40
| Création des fonctions accéléromètre | 10:30 | 13:00 | 02:30 | | Modification du .h et création des fonctions
| Création des fonctions accéléromètre | 14:10 | 16:35 | 02:25
27.10.2021 | Configuration accéléromètre | 08:45 | 13:00 | 04:15 | 0:00
| Configuration accéléromètre | 14:30 | 16:35 | 02:05
28.10.2021 | Configuration accéléromètre | 08:35 | 09:45 | 01:10 | 6:05
| Passage expert | 09:45 | 10:30 | 00:45
| Modif PCB | 10:30 | 11:55 | 01:25
| Réunion avec le maître de diplôme | 13:20 | 14:30 | 01:10
| Rapport | 15:00 | 16:35 | 01:35
29.10.2021 | Fonctionnement SPI | 08:45 | 11:00 | 02:15 | 6:25 | Fonctionnement ok (arrive à lire le chip ID) Configuration du SPI en Idle:High, Active:Low, Idle to Active, Middle
| Assistance dépannage M.Correia | 11:00 | 11:30 | 00:30
| Configuration accéléromètre | 11:45 | 12:40 | 00:55
| Configuration accéléromètre | 13:50 | 16:35 | 02:45 | | Configuration des interruptions pour activation de la pin INT1 (pour le moment non fonctionnel)
01.11.2021 | Test programme et rapport | 08:35 | 11:35 | 03:00 | 6:25 | Test lecture et écriture des registres, test des configuration et des interruption de l'accéléromètre
| Test programme et rapport | 13:10 | 15:00 | 01:50
| Montage de la partie alime et test | 15:00 | 16:35 | 01:35
02.11.2021 | Montage carte + test | 08:45 | 13:00 | 04:15 | 6:50 | Montage final de la carte et test
| Test harware et modifications | 14:00 | 16:35 | 02:35 | | Test alime, ajout pull-down, test RC
03.11.2021 | Test programme et interruption | 08:45 | 11:50 | 03:05 | 6:30 | Test allumage des LEDS, détection de mouvement et signal INT1
| Test programme et interruption | 13:10 | 16:35 | 03:25
04.11.2021 | Config accéléromètre + timer | 08:45 | 11:35 | 02:50 | 6:55
| Réunion avec maître de diplôme | 13:10 | 15:00 | 01:50 | | Mise au point de l'avacencement et résolution du problème de configuration de l'accéléromètre
| Configuration et avancement du programme | 15:20 | 17:35 | 02:15
05.11.2021 | Test alime + mesures | 08:35 | 12:00 | 03:25 | 8:50
| Test RC + mesure | 13:10 | 18:35 | 05:25
Total | | | | 00:00 | 155:00

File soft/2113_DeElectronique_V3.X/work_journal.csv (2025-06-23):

2025-06-02 | Sweedy3960 | modif readme & modif soft for display n°1
2025-06-01 | Sweedy3960 | modif readme
2025-06-01 | Sweedy3960 | Merge branch 'ACL' of https://github.com/ETML-ES-SLO/PRJ_2113_D-sElectronique into ACL
2025-06-01 | Ironay3960 | Update README.md
2025-06-01 | Ironay3960 | Update README.md
2025-06-01 | Sweedy3960 | diagrams generation
2025-06-01 | Ironay3960 | Update README.md
2025-06-01 | Sweedy3960 | modif comment in soft
2025-06-01 | Sweedy3960 | added doc to the repo
2025-06-01 | Sweedy3960 | modif readme and coms
2025-05-31 | aymeric3960 | now better solution(cnt sur step pwm) and added gitinore
2025-05-26 | aymeric3960 | solution pour rampe static bateau (compteur dans rampe montante)
2025-05-25 | aymeric3960 | added fade out (ramp down) (the PWM setting was set by the coretimer)
2025-05-25 | aymeric3960 | state adding PWM for the display(ramp up)
2025-05-19 | aymeric3960 | need to be tested longer but seem's ok
2025-05-19 | aymeric3960 | refractor main sm -> add coretimer to modify the pwm
2025-05-12 | aymeric3960 | added comments
2025-05-12 | aymeric3960 | soft version3 ok
2025-04-XX | XXXXXXXXXX | measure & fixing &mesure & modifs interrupt still there when mcu is dead
2025-04-XX | XXXXXXXXXX | measure of the wait during the reset of accelerometre & Modification of the wait fucntion
2025-04-XX | XXXXXXXXXX | some measures and modification of the accelerometre sensibility
2025-04-XX | XXXXXXXXXX | the previous version was used to test the accelerometre value of each axis
2025-03-XX | XXXXXXXXXX | removing the power hold instruction and using variable in debug mode to see each axi value
2025-03-XX | XXXXXXXXXX | modif soft for accelerometre anymotion interrupt detection
2025-03-03 | XXXXXXXXXX | measure of alim & interrupt & fixing & mesure &modifs soft
2025-02-03 | aymeric3960 | fix: readme soft v3
2025-02-03 | aymeric3960 | chore: finding Mcc solution pour configuration graphique
2025-02-03 | aymeric3960 | chore: add cdc doc création du cdc (de la fiche de modif) planification
2025-01-31 | user | MAJ PRJ 2113 - 31.01.2025 récupération du projet et mise en place repo

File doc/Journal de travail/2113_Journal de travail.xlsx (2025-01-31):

Dates | Avancement | de | à | total d'heures | total h/j | Note
2021-10-04 | Reception du dossier et discussion | 10:00:00 | 11:20:00 | 1:20:00 | 5:00:00
 | Récupération des documents PDF et création des fichiers du projet | 11:20:00 | 11:35:00 | 0:15:00
 | élaboration planning | 13:10:00 | 15:00:00 | 1:50:00
 | Schéma bloc | 15:00:00 | 15:10:00 | 0:10:00
 | Réflexion d'économie d'énergie LED | 15:10:00 | 15:30:00 | 0:20:00 |  | Recherche d'une mise en série de 2 LED qui sont tjr allumées ensemble, contrôle alimentation de sortie micro et tension de fonctionnement des LEDs, (pas assez de tension de sortie Mu)
 | Recherche | 15:30:00 | 16:20:00 | 0:50:00 |  | Recherche d'un accéléromètre
 | Documentation | 16:20:00 | 16:35:00 | 0:15:00 |  | Journal de travail
2021-10-05 | Recherche d'accéléromètre disponible | 8:35:00 | 9:10:00 | 0:35:00 | 6:25:00 | Recherche d'accéléromètre disponible à la commande (bonne disponibilité chez mouser uniquement)
 | Recherche d'accéléromètre compatible | 9:10:00 | 9:45:00 | 0:35:00 |  | Recherche dans les datasheet d'un accéléromètre qui soit utilisable (faible consommation en standbye, peu cher, 3 axes, configurable pour un réveil selon des accélération en 3 axes)
 | Recherche microcontrôleur | 10:10:00 | 10:50:00 | 0:40:00 |  | Recherche d'un microcontroleur utilisable et peu cher
 | Recherche d'un interrupteur | 10:50:00 | 11:10:00 | 0:20:00 |  | Recherche d'un éventuel interrupteur à ajouter peu cher
 | Recherche de composants | 11:10:00 | 12:00:00 | 0:50:00
 | Recherche de composants | 13:10:00 | 16:35:00 | 3:25:00 |  | Recherche des composants généraux et recherche d'un régulateur ou élévateur de tension de préférence montable à la main
2021-10-06 | Recherche de composants symbole / footprint | 8:30:00 | 11:35:00 | 3:05:00 | 6:40:00 | Recherche de composants et comparaison de prix pour choix du moins cher. Récupération et création des footprint et symbole. Comparaison entre régulateur et élévateur
 | " | 13:10:00 | 16:45:00 | 3:35:00 |  | "
2021-10-07 | Choix accéléromètre | 8:30:00 | 10:00:00 | 1:30:00 | 6:10:00 | Recherche d'un accéléromètre de chez ST car une bonne documentation en support est founit par ce fabricant. Problème plus aucun accéléromètre dispo sauf 1 à 2 francs. Choix du MC3419
 | Comparaison et choix du microcontrôleur | 10:20:00 | 11:40:00 | 1:20:00 |  | Choix du microcontrôleur qui sera utilisé entre les différents micro de la sélection initiale
 | Réunion avec le mâitre de diplôme | 13:00:00 | 14:30:00 | 1:30:00 |  | Discussion d'un montage de protection de tension inverse Choix de variante de montage, le step-up présélectionné n'est pas fait pour de la basse consommation, recherche de convertisseur, contrôle de l'utilisation possible et des courant de fonctionnement de l'accéléromètre. Choix de LED low power pour un minimum de consommation
 | Remplissage PC + doc | 14:30:00 | 15:00:00 | 0:30:00
 | Recherche de composants | 15:15:00 | 16:35:00 | 1:20:00 |  | Recherche de composants selon discussion
2021-10-08 | Recherche composants | 8:30:00 | 11:50:00 | 3:20:00 | 6:45:00 | Recherche d'un MOSFET 0,7V max de VGSth pour entrer en conduction avec la perte de la diode shottky avec un peu plus d'1V d'alimentation de pile. Choix convertisseur boost et recherche des composants généraux
 | Recherche composants | 13:10:00 | 16:35:00 | 3:25:00 |  | Recherche d'un convertisseur avec peu de consommation de courant, ses composants et les composants généraux
2021-10-11 | Schéma | 8:30:00 | 11:50:00 | 3:20:00 | 6:45:00 | Schéma électrique (Création des symbole / footprint) et schéma
 | Schéma | 13:10:00 | 16:35:00 | 3:25:00 |  | Schéma électrique (Création des symbole / footprint) et schéma, Recherche de composants pour changer les composants plus dispo
2021-10-12 | Schéma bloc | 8:30:00 | 11:45:00 | 3:15:00 | 6:30:00 | Faire le schéma
 | Vérification de schéma | 13:10:00 | 13:40:00 | 0:30:00
 | Design PCB | 14:00:00 | 16:45:00 | 2:45:00 |  | Design du PCB
2021-10-13 | Design PCB | 8:45:00 | 11:40:00 | 2:55:00 | 6:00:00 | Design PCB
 | Vérification PCB | 13:10:00 | 14:15:00 | 1:05:00 |  | Vérification PCB par un collègue
 | Mise des template | 14:15:00 | 15:30:00 | 1:15:00 |  | Template ES non présent, ajout des templates ES et création des fichiers avec template (PCB refait le copié collé ne marche pas)
 | Rapport | 15:50:00 | 16:35:00 | 0:45:00
2021-10-14 | Rapport | 8:45:00 | 10:00:00 | 1:15:00 | 6:35:00
 | Réunion avec le maitre de diplôme | 10:00:00 | 11:55:00 | 1:55:00
 | Redimensionnement self et condo | 13:10:00 | 16:35:00 | 3:25:00 |  | Recherche des calcul de dimensionnement, calcul self, condo de sortie
2021-10-15 | Recherhce des composants à changer + schéma | 8:30:00 | 12:00:00 | 3:30:00 | 5:35:00 | Recherche bouton, condo, self, calculs de comparaison des valeurs critiques et modification schéma
 | Modification PCB | 13:10:00 | 14:00:00 | 0:50:00
 | Passage expert | 14:00:00 | 15:15:00 | 1:15:00 |  | Présentation du projet et discussion de fonctionnalités, techniques et éventuelles améliorations
 | Modifications PCB | 15:15:00 | 16:35:00
2021-10-18 | Recherche exemples microchip pour le pic MM | 8:45:00 | 10:15:00 | 1:30:00 | 6:20:00 | Rien trouvé chez microchip
 | Commande de composants | 10:15:00 | 10:30:00 | 0:15:00
 | Test kit MM | 10:30:00 | 11:40:00 | 1:10:00
 | Prise en main du Code configurator | 13:10:00 | 16:35:00 | 3:25:00
2021-10-19 | Modification de commande | 8:30:00 | 9:10:00 | 0:40:00 | 6:30:00 | Retrait des composants présents en stock
 | Recherche des registres utiles accéléromètre | 9:10:00 | 11:35:00 | 2:25:00
 | Rapport | 13:10:00 | 16:35:00 | 3:25:00
2021-10-20 | Création des fichiers accéléromètre / création des define utiles | 8:45:00 | 11:35:00 | 2:50:00 | 6:15:00 | Recherche dans le datasheet des registres, adresse, fonctionnement SPI
 | Rapport | 13:10:00 | 16:35:00 | 3:25:00
2021-10-21 | config accéléromètre | 8:45:00 | 11:50:00 | 3:05:00 | 6:20:00 | Recherche des registres utiles, création des define
 | Contrôle commande | 13:20:00 | 13:40:00 | 0:20:00 |  | Contrôle des composants reçus
 | Réunion avec le mâitre de diplôme | 13:40:00 | 15:00:00 | 1:20:00
 | Création des fonctions accéléromètre | 15:00:00 | 16:35:00 | 1:35:00
2021-10-22 | Configuration chip | 8:45:00 | 12:00:00 | 3:15:00 | 6:20:00 | Configuration chip. Le main a une erreur à la génération et ne se fonctionne pas (l'erreur n'est pas connu pour le moment). Aucun message d'erreur n'apparait
 | Brasage PCB diego | 13:10:00 | 14:00:00 | 0:50:00 |  | Aide au brasage du PCB de M.Correia
 | Configuration chip | 14:00:00 | 15:40:00 | 1:40:00 |  | Erreur toujours non réglée
 | Rapport | 16:00:00 | 16:35:00 | 0:35:00
2021-10-25 | aider diego à son montage PCB | 8:45:00 | 10:00:00 | 1:15:00 | 6:25:00
 | Montage accéléromètre | 10:00:00 | 12:30:00 | 2:30:00 |  | Problème au passage au four, la pâte à brasé a durci mais pas fondu. Deuxième passage ok (modification température à atteindre et temps pour pour atteindre la consigne)
 | Montage micro | 13:30:00 | 14:15:00 | 0:45:00 |  | Montage microcontrôleur et nettoyage carte
 | Montage des composant nécessaire au fonctionnement micro + accéléromètre | 14:15:00 | 14:40:00 | 0:25:00
 | Test fonctionnalité MPLABX | 14:40:00 | 14:55:00 | 0:15:00 |  | Test si le problème du vendredi est toujours présent (toujours présent pour tout les fichiers)
 | Configuration programme de test micro | 15:20:00 | 16:15:00 | 0:55:00
 | Rapport | 16:15:00 | 16:35:00 | 0:20:00
2021-10-26 | Test micro | 8:45:00 | 9:35:00 | 0:50:00 | 6:25:00 | Refaire un câble adapté pour la connexion de programmation de la carte + programme de test et test du micro (test court-ciruit d'alimentation effectué avant)
 | Test Timer et montage LED | 9:50:00 | 10:30:00 | 0:40:00
 | Création des fonctions accéléromètre | 10:30:00 | 13:00:00 | 2:30:00 |  | Modification du .h et création des fonctions
 | Création des fonctions accéléromètre | 14:10:00 | 16:35:00 | 2:25:00
2021-10-27 | Configuration accéléromètre | 8:45:00 | 13:00:00 | 4:15:00 | 0:00:00
 | Configuration accéléromètre | 14:30:00 | 16:35:00 | 2:05:00
2021-10-28 | Configuration accéléromètre | 8:35:00 | 9:45:00 | 1:10:00 | 6:05:00
 | Passage expert | 9:45:00 | 10:30:00 | 0:45:00
 | Modif PCB | 10:30:00 | 11:55:00 | 1:25:00
 | Réunion avec le maître de diplôme | 13:20:00 | 14:30:00 | 1:10:00
 | Rapport | 15:00:00 | 16:35:00 | 1:35:00
2021-10-29 | Fonctionnement SPI | 8:45:00 | 11:00:00 | 2:15:00 | 6:25:00 | Fonctionnement ok (arrive à lire le chip ID) Configuration du SPI en Idle:High, Active:Low, Idle to Active, Middle
 | Assistance dépannage M.Correia | 11:00:00 | 11:30:00 | 0:30:00
 | Configuration accéléromètre | 11:45:00 | 12:40:00 | 0:55:00
 | Configuration accéléromètre | 13:50:00 | 16:35:00 | 2:45:00 |  | Configuration des interruptions pour activation de la pin INT1 (pour le moment non fonctionnel)
2021-11-01 | Test programme et rapport | 8:35:00 | 11:35:00 | 3:00:00 | 6:25:00 | Test lecture et écriture des registres, test des configuration et des interruption de l'accéléromètre
 | Test programme et rapport | 13:10:00 | 15:00:00 | 1:50:00
 | Montage de la partie alime et test | 15:00:00 | 16:35:00 | 1:35:00
2021-11-02 | Montage carte + test | 8:45:00 | 13:00:00 | 4:15:00 | 6:50:00 | Montage final de la carte et test
 | Test harware et modifications | 14:00:00 | 16:35:00 | 2:35:00 |  | Test alime, ajout pull-down, test RC
2021-11-03 | Test programme et interruption | 8:45:00 | 11:50:00 | 3:05:00 | 6:30:00 | Test allumage des LEDS, détection de mouvement et signal INT1
 | Test programme et interruption | 13:10:00 | 16:35:00 | 3:25:00
2021-11-04 | Config accéléromètre + timer | 8:45:00 | 11:35:00 | 2:50:00 | 6:55:00
 | Réunion avec maître de diplôme | 13:10:00 | 15:00:00 | 1:50:00 |  | Mise au point de l'avacencement et résolution du problème de configuration de l'accéléromètre
 | Configuration et avancement du programme | 15:20:00 | 17:35:00 | 2:15:00
2021-11-05 | Test alime + mesures | 8:35:00 | 12:00:00 | 3:25:00 | 8:50:00
 | Test RC + mesure | 13:10:00 | 18:35:00 | 5:25:00
Total |  |  |  | 0:00:00 | 155:00:00

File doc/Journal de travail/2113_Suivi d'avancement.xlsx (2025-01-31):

Date | 2021-10-04 | 2021-10-05 | 2021-10-06 | 2021-10-07 | 2021-10-08 | 2021-10-09 | 2021-10-10 | 2021-10-11 | 2021-10-12 | 2021-10-13 | 2021-10-14 | 2021-10-15 | 2021-10-16 | 2021-10-17 | 2021-10-18 | 2021-10-19 | 2021-10-20 | 2021-10-21 | 2021-10-22 | 2021-10-23 | 2021-10-24 | 2021-10-25 | 2021-10-26 | 2021-10-27 | 2021-10-28 | 2021-10-29 | 2021-10-30 | 2021-10-31 | 2021-11-01 | 2021-11-02 | 2021-11-03 | 2021-11-04 | 2021-11-05 | 2021-11-06 | 2021-11-07 | 2021-11-08 | 2021-11-09
Réception du projet et discussion
Planning
Schéma bloc
Choix des composants critiques
Schéma électrique
Vérification et correction du schéma
Design PCB
Vérification et correction du PCB
Commande PCB
Création du boitier
Commande composants
Configuration de l'accéléromètre
Tests configuration du chip (kit éval)
programme général
Communication Micro et accéléromètre
Montage de la carte
Test et dépannage hardware
Test programme
Divers calculs et estimations des coùts
Réunion avec le maître de diplôme |  |  |  | PV |  |  |  |  |  |  | PV
Rapport
Affiche et résumé
 |  | : deadline du projet

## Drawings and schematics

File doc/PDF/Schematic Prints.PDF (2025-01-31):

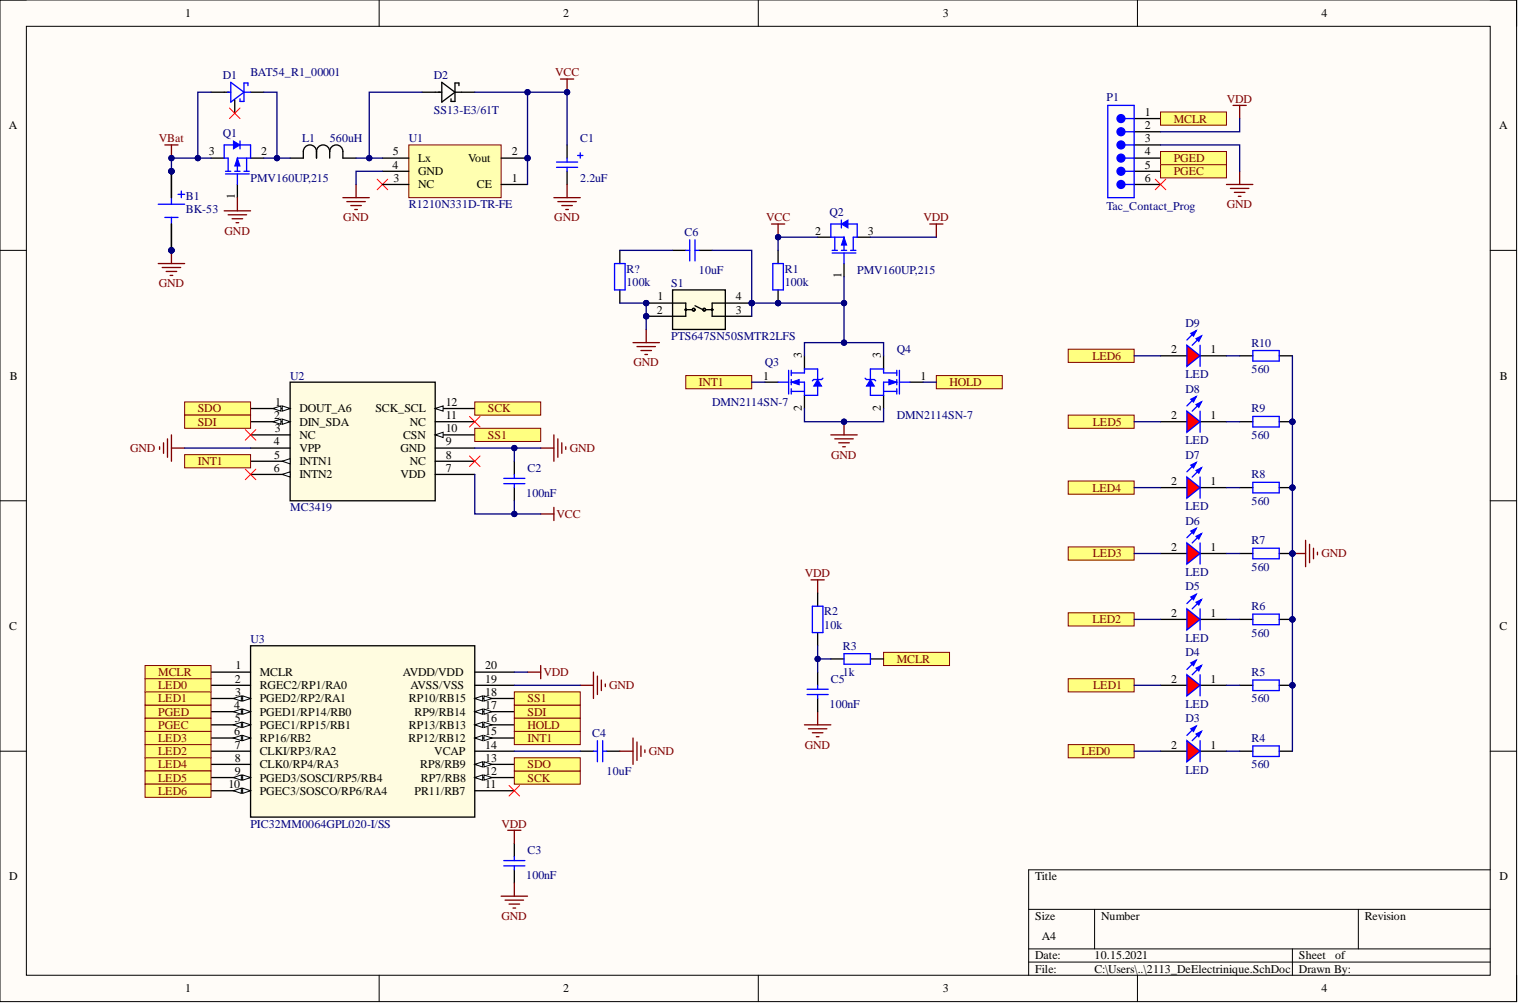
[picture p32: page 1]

LED4 | SDO
LED5 | SCK

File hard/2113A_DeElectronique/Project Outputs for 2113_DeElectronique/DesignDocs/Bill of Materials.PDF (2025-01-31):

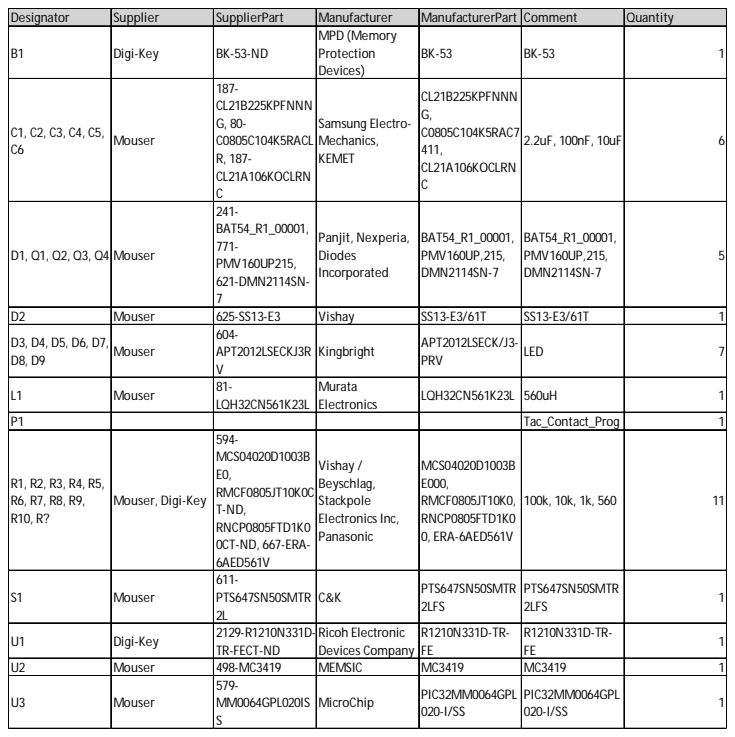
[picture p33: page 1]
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

C1, C2, C3, C4, C5, C6 | Mouser | 187-CL21B225KPFNNN G, 80-C0805C104K5RACL R, 187-CL21A106KOCLRN C | Samsung Electro-Mechanics, KEMET | CL21B225KPFNNN G, C0805C104K5RAC7 411, CL21A106KOCLRN C | 2.2uF, 100nF, 10uF | 6

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

D2 | Mouser | 625-SS13-E3 | Vishay | SS13-E3/61T | SS13-E3/61T | 1
D3, D4, D5, D6, D7, D8, D9 | Mouser | 604-APT2012LSECKJ3R V | Kingbright | APT2012LSECK/J3-PRV | LED | 7

L1 | Mouser | 81-LQH32CN561K23L | Murata Electronics | LQH32CN561K23L | 560uH | 1

P1 | | | | | Tac_Contact_Prog | 1
R1, R2, R3, R4, R5, R6, R7, R8, R9, R10, R? | Mouser, Digi-Key | 594-MCS04020D1003B E0, RMCF0805JT10K0C T-ND, RNCP0805FTD1K0 0CT-ND, 667-ERA-6AED561V | Vishay / Beyschlag, Stackpole Electronics Inc, Panasonic | MCS04020D1003B E000, RMCF0805JT10K0, RNCP0805FTD1K0 0, ERA-6AED561V | 100k, 10k, 1k, 560 | 11

S1 | Mouser | 611-PTS647SN50SMTR 2L | C&K | PTS647SN50SMTR 2LFS | PTS647SN50SMTR 2LFS | 1

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

U2 | Mouser | 498-MC3419 | MEMSIC | MC3419 | MC3419 | 1
U3 | Mouser | 579-MM0064GPL020IS S | MicroChip | PIC32MM0064GPL 020-I/SS | PIC32MM0064GPL 020-I/SS | 1

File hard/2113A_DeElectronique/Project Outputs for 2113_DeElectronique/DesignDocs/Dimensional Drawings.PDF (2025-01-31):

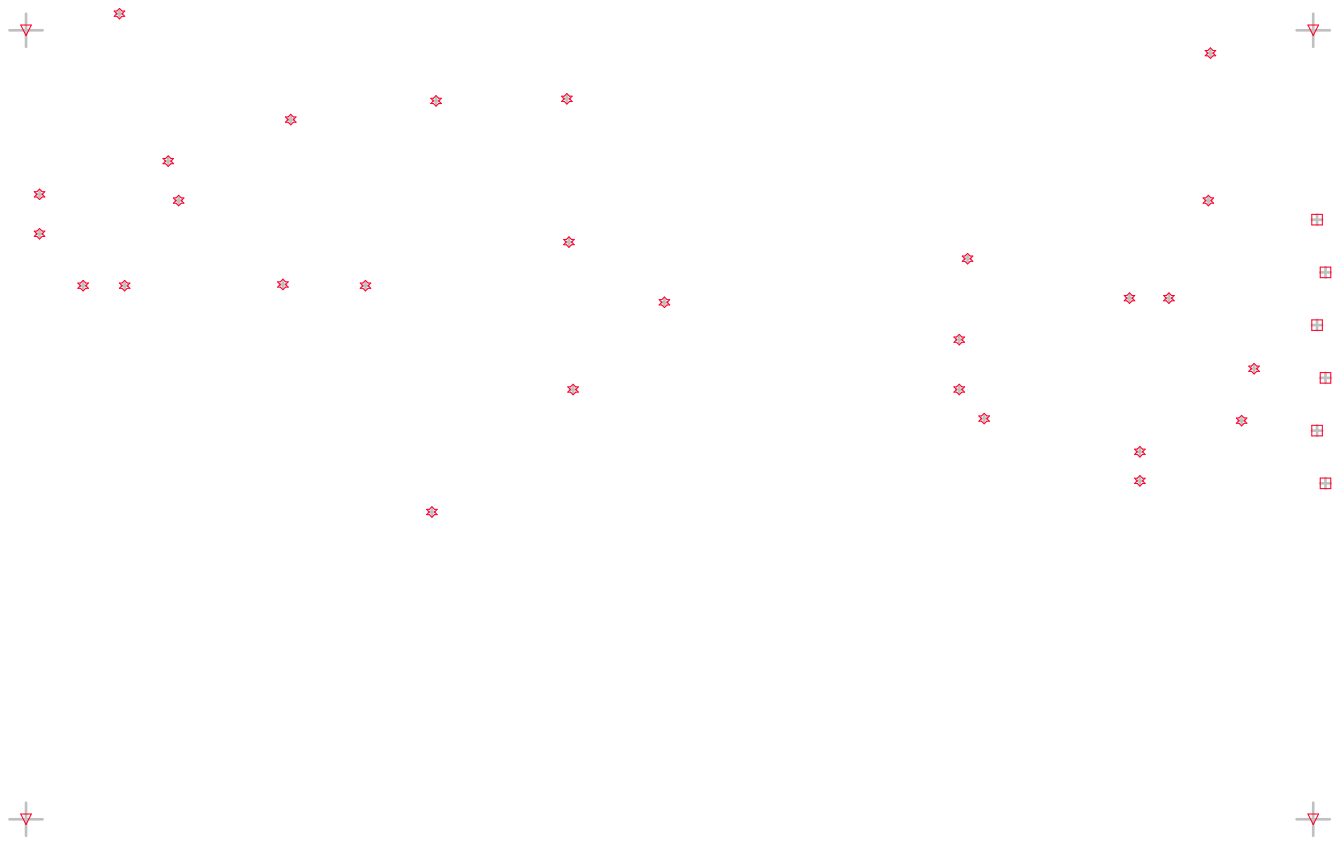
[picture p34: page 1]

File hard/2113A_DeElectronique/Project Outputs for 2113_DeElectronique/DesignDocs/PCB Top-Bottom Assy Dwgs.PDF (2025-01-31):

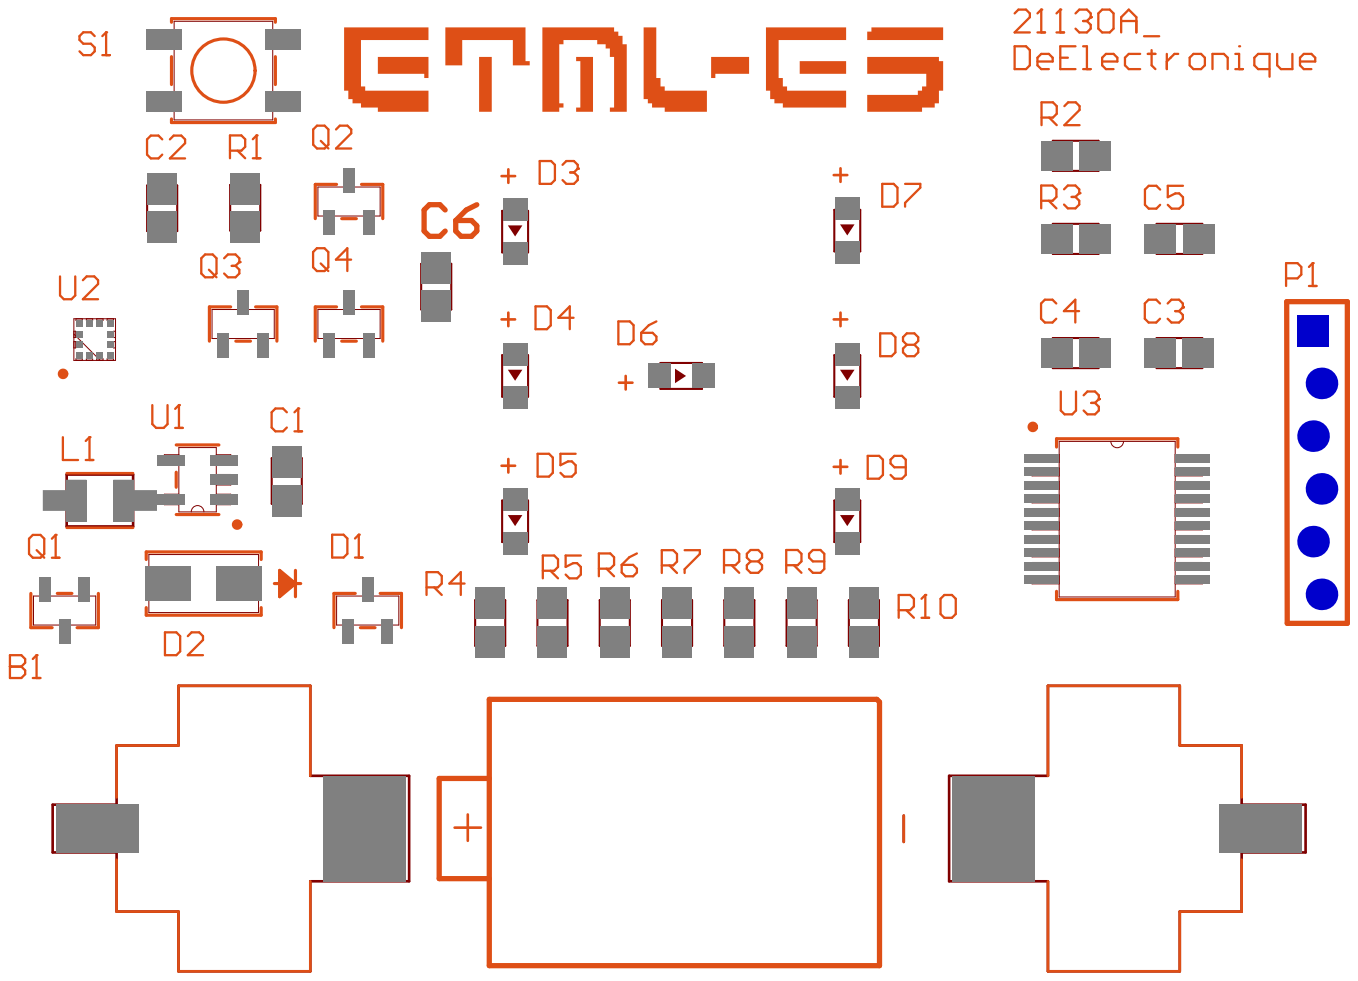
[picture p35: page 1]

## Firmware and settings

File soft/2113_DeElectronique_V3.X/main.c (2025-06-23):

/**
  Generated main.c file from MPLAB Code Configurator

  @Company
    Microchip Technology Inc.

  @File Name
    main.c la 

  @Summary
    This is the generated main.c using PIC24 / dsPIC33 / PIC32MM MCUs.

  @Description
    This source file provides main entry point for system intialization and application code development.
    Generation Information :
        Product Revision  :  PIC24 / dsPIC33 / PIC32MM MCUs - 1.75.1
        Device            :  PIC32MM0064GPL020
    The generated drivers are tested against the following:
        Compiler          :  XC16 v1.35
        MPLAB 	          :  MPLAB X v5.05
 */

/*
    (c) 2016 Microchip Technology Inc. and its subsidiaries. You may use this
    software and any derivatives exclusively with Microchip products.

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
    IN NO EVENT WILL MICROCHIP BE LIABLE FOR ANY INDIRECT, SPECIAL, PUNITIVE,
    INCIDENTAL OR CONSEQUENTIAL LOSS, DAMAGE, COST OR EXPENSE OF ANY KIND
    WHATSOEVER RELATED TO THE SOFTWARE, HOWEVER CAUSED, EVEN IF MICROCHIP HAS
    BEEN ADVISED OF THE POSSIBILITY OR THE DAMAGES ARE FORESEEABLE. TO THE
    FULLEST EXTENT ALLOWED BY LAW, MICROCHIP'S TOTAL LIABILITY ON ALL CLAIMS IN
    ANY WAY RELATED TO THIS SOFTWARE WILL NOT EXCEED THE AMOUNT OF FEES, IF ANY,
    THAT YOU HAVE PAID DIRECTLY TO MICROCHIP FOR THIS SOFTWARE.

    MICROCHIP PROVIDES THIS SOFTWARE CONDITIONALLY UPON YOUR ACCEPTANCE OF THESE
    TERMS.
 */

/**
  Section: Included Files
 */
#include "Main.h"
#include "Mc32Delays.h"
#include "mcc_generated_files/system.h"
#include "mcc_generated_files/spi1.h"
#include "mcc_generated_files/pin_manager.h"
#include "Accelerometre.h"
#include "DeElectronique.h"
#include "mcc_generated_files/tmr1.h"
#include <stdbool.h>
#include <stdlib.h>

/*
                         Main application
 */
appData appdata;

/**
 * @brief Point d'entrée principal de l'application.
 * @return 1 en cas de fin de programme
 */
int main(void) {
    appdata.state=APP_INIT;
    while (1) {
        switch (appdata.state) {
            case APP_INIT:
                /**
                 * @brief Initialisation de l'application.
                 *
                 * - Configure le système et les périphériques.
                 * - Définit les valeurs par défaut des variables d'état.
                 * - Vérifie l'absence d'interruption pour configurer l'accéléromètre.
                 * - Passe à l'état d'attente d'interruption.
                 * - RC is for cycle duty of PWM, initialized to  0
                 * - disp is a flag for display, initialized to 0 (off)  
                 */
                SYSTEM_Initialize();
                appdata.status = 0;
                appdata.firstTimeSincePowerUp = true;
                appdata.shakenHasOccured = false;
                appdata.anymHasOccured = false;
                appdata.APP_DelayTimeIsRunning = false;
                appdata.AppDelay = DISPLAYTIME;
                appdata.disp=0;
                appdata.RC =0;
                //set PWM timing at displayTime/3 
                appdata.cntPwmWaiting = (DISPLAYTIME/(STEPON*10));
                uint16_t randomSum = 0;
                appdata.nombreEntier = 0;
                
                // initialize the device
               
                POWER_HOLD = 1; //maintien alim ON

                //si  pas d'interrupt  
                if (!INT_SHAKE) {
                    //config accelerom�tre
                    MC3419_start();
                    //maintien alim OFF
                   POWER_HOLD = 0;
                }
                SetStates(APP_WAIT_FOR_INT);
                break;


            case APP_WAIT_FOR_INT:
                /**
                 * @brief Attente d'une interruption de l'accéléromètre.
                 *
                 * - Lit le registre d'état de l'accéléromètre.
                 * - Vérifie les interruptions de type "shake" et "any motion".
                 * - Si une interruption est détectée et que c'est la première fois depuis la mise sous tension,
                 *   passe à l'état de calcul.
                 */
                
                //Lecture registre accéle
                appdata.status = MC3419_ReadStatusRegister();
                appdata.shakenHasOccured = (appdata.status & SHAKE_INT);
                appdata.anymHasOccured = (appdata.status & ANYM_INT);
                if ((appdata.shakenHasOccured || appdata.anymHasOccured)&& (appdata.firstTimeSincePowerUp == true)) {
                    appdata.firstTimeSincePowerUp = false;
                    SetStates(APP_CALC);
                }
                break;
            case APP_CALC:
                /**
                 * @brief Calcule la valeur pseudo-aléatoire du dé à partir des registres de l'accéléromètre.
                 *
                 * - Additionne les valeurs des axes X, Y, Z pour obtenir une graine.
                 * - Utilise srand/rand pour générer un nombre pseudo-aléatoire.
                 * - Passe à l'état d'affichage.
                 */
                randomSum =  ReadRegister8(addr_Xout_Ex_L);
                randomSum += ReadRegister8(addr_Xout_Ex_H);
                randomSum += ReadRegister8(addr_Yout_Ex_L);
                randomSum += ReadRegister8(addr_Yout_Ex_H);
                randomSum += ReadRegister8(addr_Zout_Ex_L);
                randomSum += ReadRegister8(addr_Zout_Ex_H);
                srand(randomSum);
                randomSum = rand();
                //pour récupérer une valeur entre 1 et 6
                appdata.nombreEntier = randomSum % 6;
                SetStates(APP_DISPLAY);
                break;
            case APP_DISPLAY:
                /**
                 * @brief Prépare l'affichage du résultat sur les LEDs.
                 *
                 * - Initialise le rapport cyclique PWM (RC) à 10.
                 * - Active l'affichage (disp=1).
                 * - Passe à l'état d'attente d'affichage.
                 */
                appdata.RC =10;
                appdata.disp=1;
                SetStates(APP_DELAY);
                break; 
            case APP_DELAY:
                /**
                 * @brief Lance l'attente d'affichage du résultat.
                 *
                 * - Démarre l'attente bloquante (affichage du dé).
                 * - Passe à l'état d'extinction.
                 */
                APP_WaitStart(DISPLAYTIME);
                SetStates(APP_KILL);
                break;
            case APP_KILL:
                /**
                 * @brief Éteint les LEDs et met le système en veille si aucune interruption n'est détectée.
                 *
                 * - Éteint l'affichage.
                 * - Efface les interruptions de l'accéléromètre.
                 * - Si aucune interruption, coupe l'alimentation et boucle infinie pour arrêt total.
                 */
                DISPLAYNONUM();
                MC3419_clearRegister();
                if (!INT_SHAKE) {
                    // maintien alim OFF
                    MC3419_clearRegister();
                    POWER_HOLD = 0;
                    //boucle infini pour être sur
                    while (1) {
                    };
                    break;
                }







        }
    }
    return 1;
}

/**
 End of File
 */

/*
 * Fct de call back du timer en fct du delay store dans AppData
 */
void APP_TMR1_CallBack(void) {

    if (appdata.AppDelay > 0) {
        appdata.AppDelay--;
    } else {
        appdata.APP_DelayTimeIsRunning = 0;
    }
    appdata.cntPwmWaiting--;
    //APP_WaitStart(cnt);

}

/**
 * @brief Attente bloquante pendant un temps donné en ms (utilise le timer 1).
 * @param waitingTime_ms Durée d'attente en millisecondes
 */
void APP_WaitStart(uint16_t waitingTime_ms) {
    
    int8_t step = 10;
    static int8_t sens = RAMPUP;
    appdata.AppDelay = waitingTime_ms - 1;
    static uint16_t cntFullON = 0;
    TMR1_Start();
    appdata.APP_DelayTimeIsRunning = 1;
    while (appdata.APP_DelayTimeIsRunning) {
        //Display_Dice_PWM with 10% RC 
        if(appdata.disp)
        {
        Display_Dice_PWM(appdata.nombreEntier, appdata.RC);
        

        if (appdata.cntPwmWaiting == 0) {
            //resest the "timer" 
            appdata.cntPwmWaiting = (DISPLAYTIME / (STEPON * STEPPWM));
        
            switch (sens) {
                case RAMPDOWN:
                    appdata.RC -= step;
                    if (appdata.RC < 10) {
                        appdata.RC = 10;
                        sens = RAMPSTATIC;
                    }


                    break;
                case RAMPUP:
                    appdata.RC += step;
                    
                    if (appdata.RC >= 100) {
                        appdata.RC = 100;
                        sens =RAMPSTATIC;
                    }

                    break;
                case RAMPSTATIC:
                   
                    if (cntFullON >= (STEPPWM-1))
                    {
                        sens =RAMPDOWN;
                    }
                    else
                    {
                        cntFullON++;
                    }
                    break;

                default:
                    sens = 1;
                    appdata.RC = 10; // start at minimum

                    break;
            }

            }
        }
    }
    TMR1_Stop();
    
    
}

/**
 * @brief Change l'état courant de l'application.
 * @param newstate Nouvel état à appliquer
 */
void SetStates(states newstate) {
    appdata.state = newstate;
}

/**
 * @brief Callback du core timer pour gérer la variation de RC.
 */
void APP_CORETIMER_CALLBACK(void)
{
    static int8_t sens=1;
    int8_t step = 10; 
    if (sens == 1) {
        appdata.RC += step;
        if (appdata.RC >= 100) {
            appdata.RC = 100; 
            sens = -1;        
        }
    } else if (sens == -1) {
        appdata.RC -= step;
        if (appdata.RC < 10) {
            appdata.RC = 10; 
            sens = 1;        
        }
    } else {
        sens = 1;
        appdata.RC = 10; // start at minimum
    }
    
}

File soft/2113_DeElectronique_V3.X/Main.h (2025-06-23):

/* 
 * File:   Main.h
 * Author: maxcolloud
 *
 * Created on October 26, 2021, 10:37 AM
 */

#ifndef MAIN_H
#define	MAIN_H
#include "stdint.h"
#include "stdbool.h"
#ifdef	__cplusplus
extern "C" {
#endif

//set the display time to 10s  cause setting are in ms   
#define DISPLAYTIME  3000 //set to 3S
#define STEPON 3 //there is 3 step in display sequence
#define DISPLAY_UP  1000 //ramp up is 1s
#define DISPLAY_ON  1000    //static up is 1s
#define DISPLAY_DODW    1000    //ramp down is 1s
#define STEPPWM 10    //there is 10  step to do 
#define STEPWMSEC (DISPLAY_ON/STEPPWM) //so this is the time per pwm step 
#define TIMERATIO 1000 //and this is time ratio cause 1s= 1000ms


    typedef enum {
        RAMPUP,
        RAMPSTATIC,
        RAMPDOWN,
    } sens;

    typedef enum {
        APP_INIT,
        APP_WAIT_FOR_INT,
        APP_CALC,
        APP_DISPLAY,
        APP_DELAY,
        APP_KILL,
    } states;

    typedef struct {
        uint8_t state;
        bool disp;
        bool firstTimeSincePowerUp;
        bool shakenHasOccured;
        bool anymHasOccured;
        bool APP_DelayTimeIsRunning;
        uint16_t AppDelay;
        uint8_t status;
        uint8_t nombreEntier;
        uint8_t RC;
        uint16_t cntPwmWaiting;
    } appData;


    /**
     * @brief Lance une attente bloquante pendant un temps donné (ms).
     * @param waitingTime Durée d'attente en millisecondes
     */
    void APP_WaitStart(uint16_t waitingTime);
    /**
     * @brief Callback du timer 1, décrémente le délai stocké dans AppData.
     */
    void APP_TMR1_CallBack();
    /**
     * @brief Lance une attente non bloquante (fonction expérimentale).
     * @return true si attente terminée, false sinon
     */
    bool APP_WaitStart_noBlocking();
    /**
     * @brief Change l'état courant de l'application.
     * @param newstate Nouvel état à appliquer
     */
    void SetStates(states newstate);
    /**
     * @brief Callback du core timer pour gérer la variation de RC.
     */
    void APP_CORETIMER_CALLBACK(void);

#ifdef	__cplusplus
}

#endif

#endif	/* MAIN_H */

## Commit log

2025-01-31 MAJ PRJ 2113 - 31.01.2025
    [2113A_DeElectrinique.SchDoc, 2113A_DeElectronique.PcbDoc, 2113A_DeElectronique.PrjPcb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]
2025-05-19 refractor main sm -> add coretimer to modify the pwm
2025-06-01 added jdv from git
    [work_journal.csv]
2025-06-01 added diagrams
    [work_journal.csv]
2025-06-02 added results
    [result.csv]
2025-06-02 modif jdv
    [work_journal.csv]
2025-06-02 modifs comments
    [work_journal.csv]
